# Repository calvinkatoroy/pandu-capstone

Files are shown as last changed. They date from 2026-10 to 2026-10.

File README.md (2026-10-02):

# PANDU capstone (Kelompok 13)

- `weekly/`   laporan dan progres per pekan (WEEK_2 .. WEEK_6)
- `hardware/` ekspor desain (Gerber, netlist, SCAD terbaru), diisi setelah PCB final
- `docs/`     dokumentasi pendukung

Sumber kebenaran skematik/PCB: project EasyEDA Pro "Pandu-Capstone". Repo ini hanya menyimpan salinannya.
Gerber di `weekly/WEEK_6/Gerber` adalah versi lama, JANGAN dipesan.

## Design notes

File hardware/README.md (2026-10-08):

# hardware/

PERHATIAN: Gerber di sini belum boleh dipesan, lihat gerber/README.md dan docs/AUDIT_V2.md. (Teks lama di bawah, usang:)
- `gerber/Gerber_PCB1_2026-10-03.zip`  Vest Node (ESP32 DevKitC V4, 107,95 x 95,25 mm)
- `gerber/Gerber_PCB3_2026-10-03.zip`  Edge Gateway (ESP32 DevKitC V4)

- `gerber/Gerber_PCB2_2026-10-03.zip`  Helmet Node (ditambah C2 100 uF tantalum 6,3 V di 3V0_HELMET, outline +~0,5 inci ke bawah)

Gerber lama di `weekly/WEEK_6/Gerber` JANGAN dipesan.

Sebelum order: lihat checklist "Sebelum order" di ../HANDOVER.md
(ukur board fisik, cek urutan pin modul LoRa/TP4056/boost, VBOOST_5V masih 10 mil).

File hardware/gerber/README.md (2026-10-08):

# Gerber

JANGAN dipesan, semua versi di bawah memuat masalah yang diaudit di docs/AUDIT_V2.md:
- footprint LoRa RA-02 tidak cocok dengan modul XL1276 (RFM95), PCB1 dan PCB3
- proteksi TP4056 terlewati (B- dan OUT- digabung GND), PCB1 dan PCB2
- SAW1 di PCB2 adalah filter SMD, bukan saklar
- TTP223 di PCB2 tidak dipakai lagi

`_obsolete/` = versi lama. Gerber valid berikutnya dibuat dari branch `v3` setelah revisi EasyEDA (docs/PLAN_REVISI.md).
Berkas yang masih ada di folder ini (Gerber_PCB1_2026-10-06, Gerber_PCB2_2026-10-08, Gerber_PCB3_2026-10-06) adalah yang TERBARU sebelum revisi, tetap belum boleh dipesan.

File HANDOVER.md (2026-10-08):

# HANDOVER: PANDU hardware (per 2 Okt 2026)

Penerima: sesi baru (cloud atau lokal). Baca ini dulu, lalu `weekly/WEEK_6/Audit_Skematik_Status.md`.

## Konteks singkat
- Proyek: P.A.N.D.U (Perangkat Alarm Nirkabel Deteksi Urgensi), wearable keselamatan pandu laut. Kelompok 13, user: Calvin (bahasa Indonesia santai).
- Proposal: `weekly/WEEK_2/Proposal Bab 6 ... .pdf`. Riwayat Pekan 2-5: `weekly/WEEK_6/Riwayat_Progres_Pekan2-5.md`. Jangan ulang konten itu di laporan Pekan 6.
- 3 board di EasyEDA Pro project **Pandu-Capstone**: Board1/PCB1 Vest Node Master, Board2/PCB2 Helmet Node, Board3/PCB3 Edge Gateway.
- Sumber kebenaran skematik/PCB = EasyEDA (akun calvinwkatoroy). Repo ini hanya salinan.

## Keputusan yang sudah final
- Sensor Vest: MPU6050, XKC-Y25 (air, non-kontak, VCC 5 V), GPS NEO-6M, LoRa. **Tanpa VL53L0X dan BME680** (false positive anti-crush). Tanpa buzzer di Vest.
- Board ESP32 Vest: **ESP32-DevKitC V4 WROOM-32D (klasik, Micro USB)**, bukan DevKitM-1/C3. Nama part di EasyEDA "ESP32-DEVKITM-1" menyesatkan.
- Daya Vest: 18650 > TP4056 > `VBAT_RAW` (tanpa saklar seri). Boost 5 V selalu aktif memberi pin 5V ESP32 dan `VBOOST_5V`. AMS1117, C1, C2 dihapus.
- SW1 (tact + rubber boot) = input GPIO RTC (IO13), toggle deep sleep di firmware. SOS (SW2) di IO27 (RTC).
- Gating hemat daya: GPS lewat P-MOSFET Q1 (`GPS_EN`=IO4); XKC-Y25 lewat Q2 + level shifter Q5 (`XKC_EN`=IO2). Default OFF saat sleep.
- Casing: PETG, plug silikon bertali untuk USB, SMA bulkhead, boot karet di tombol, gasket di sambungan. Klaim jujur "tahan percikan" kecuali ada uji rendam.

## Status per board
**PCB1 (Vest)**: skematik sudah diperbaiki (RA-02 pin 1 = ANT bukan GND, GND pin 2/9/16, GPS_EN tersambung, gating MOSFET). PCB di-update, auto-route, DRC 0 error, 0 ratline.
**PCB2 (Helmet)**: belum diubah. Risiko brownout CR2032 (tambah 100-220 uF low-ESR di 3V0).
**PCB3 (Gateway, sudah diganti ke DevKitC, lihat blocker 2)**: EN pull-up + 100 nF, header program J1 1x6, ANT RA-02 diperbaiki, EP ke GND, pull-down gate sirine R3. DRC 0 error. Masih ESP32 **modul polos** WROOM-32.

## BLOCKER (urut prioritas)
1. **[SELESAI di PCB1, 2 Okt malam]** Footprint ESP32 PCB1 sudah diganti ke DevKitC V4 (part LCSC C571181, designator U3, jarak baris resmi 1,0"). Skematik PCB1 tersimpan, PCB di-update, auto-route 0 ratline, DRC 0 error. Yang masih harus dicek: ukuran fisik board klon, dan USB micro DevKit sekarang menghadap ke dalam papan (perhatikan akses di casing). Teks lama:
   **Footprint ESP32 di PCB1 salah.** Sekarang 17 pin/sisi, jarak baris 0,9". Board yang dibeli (DevKitC V4) 2x19 pin, jarak baris resmi 25,4 mm (klon kadang 22,86 mm). **Part siap pakai ADA** di library EasyEDA (System): cari "DevKitC" di tab Device, baris ke-7 (LCSC C571181, nama ESP32-DEVKITC...). Simbol 38 pin (3V3, EN, VP, VN, IO34... GND, IO23, IO22, TX, RX, ... CLK) cocok dengan pinout DevKitC V4, footprint 2x19 THT dengan jarak baris sekitar 1,0" (estimasi dari preview, **ukur setelah ditempatkan**). Tidak perlu membuat dari nol. Tetap minta Calvin ukur board fisik (jarak tengah lubang kiri-kanan) sebelum order PCB.
2. **PCB3**: BOM beli DevKit tapi PCB3 didesain untuk modul polos. Rekomendasi: ganti ke footprint DevKitC V4 yang sama, hapus U4/C1/C2/J1/R2/C3 (DevKit sudah punya regulator dan USB).
3. **Modul LoRa yang dibeli bukan Ra-02**: listing "Wifi LoRa XL1276/SX1276 915MHz" (akhishop, Rp95k, datang dengan antena pegas, 1,8-3,7 V, SPI, foto mirip RFM95). Simbol/footprint RA-02 di PCB1/PCB3 mungkin tidak cocok. Minta foto sisi pin atau datasheet modul, cek urutan pin.
4. Setelah 1-3: lebarkan trek daya (VBAT_RAW, VBAT_POS 20 mil; auto-route menimpa ke 10 mil), DRC, ekspor Gerber PCB1/2/3 baru ke `hardware/`.

## Item terbuka lain
- Gateway: Q1 IRFZ44N bukan logic-level, ganti IRLZ44N (footprint sama). USB-C tanpa resistor CC 5,1k (pakai kabel A-ke-C). Dioda flyback hanya jika beban induktif.
- Pin TP4056 dan boost: urutan harus dicek ke modul fisik.
- Casing SCAD (`weekly/WEEK_6/PANDU_VestNode_Casing.scad`) belum diupdate: TP4056 di sisi Bottom (bukaan USB), posisi boost (kiri), XKC-Y25, plug USB, alur gasket.
- Gerber lama (`weekly/WEEK_6/Gerber`) **jangan dipesan**.
- Laporan Pekan 6 belum ditulis. Catat sebagai perubahan scope: tanpa ToF/BME680, PCB1 di-routing ulang setelah audit, casing dibuat ulang mengikuti PCB.
- BOM sheet (Google Sheets "Bills of Materials") belum di-update oleh tim; Rafif bilang semua sudah dibeli kecuali baris kuning dan PCB. ESP32 Vest dan LoRa Gateway tercentang FALSE padahal link sama (kemungkinan sudah dibeli 2). Harga ESP32 di listing Rp128k vs BOM Rp80k. VL53L0X/BME680 masih di BOM (hapus, hemat Rp250k). Belum ada di BOM: boost 5 V, XKC-Y25, antena+SMA untuk Vest, komponen SMD (AO3401A, 2N7002, resistor), IRLZ44N. Total BOM Rp2,495 jt vs dana Rp2 jt.
- RA-02/LoRa: proposal 915 MHz, modul dibeli 915 MHz (OK). Regulasi Indonesia 920-923 MHz, sebut di laporan.
- Angka "akurasi sensor 96,2%" di laporan kelompok tidak punya data pengujian; cek atau hapus.

## Catatan teknis EasyEDA (penting, UI-nya rapuh)
- Dikendalikan lewat ekstensi Claude-in-Chrome (klik koordinat). **Cloud session tidak bisa menjangkau Chrome lokal Calvin**, jadi pekerjaan EasyEDA harus dilakukan di sesi lokal. Cloud cocok untuk dokumen, laporan, riset, BOM, SCAD.
- Kabel yang digambar dengan klik sering meleset beberapa piksel dari ujung pin dan pin tetap mengambang. Taruh **net label tepat di titik ujung pin**, lalu verifikasi dengan DRC skematik ("Pins floating", baca via get_page_text).
- Jangan `ctrl+a` kecuali fokus pasti di kolom input; di kanvas PCB ia memilih semua objek. Mengetik teks saat fokus di kanvas memicu hotkey. Selalu klik kolom input dulu.
- Edit X/Y komponen lewat panel properti kadang tidak tersimpan; verifikasi dengan zoom ke panel. Drag di kanvas lebih andal.
- Alur PCB: Design > Update PCB from Schematic (Apply Changes), Route > Unroute > All, Route > Auto Routing (Run), Tools > Copper Manager Rebuild All, Ctrl+S, Check DRC.
- Setiap tool hotkey/aksi destruktif: cek tab tidak berasterisk (*) bila tidak ingin perubahan.

## File penting
- `weekly/WEEK_6/PANDU_VestNode_Casing.scad` (+ png render), `PCB1_Verifikasi_Skematik.md` (versi lama), `Audit_Skematik_Status.md` (status terbaru), `Riwayat_Progres_Pekan2-5.md`.
- `weekly/WEEK_6/Gerber/` (LAMA, jangan dipesan).
- `APP/` (di luar repo ini) = dashboard wireframe, repo `pandu-dashboard`.

## Pemetaan pin final
- Vest (U3 DevKitC): PWR_BTN=IO13, BTN_SOS=IO27, WATER_SIG=IO34, GPS_EN=IO4, **XKC_EN=IO32** (bukan IO2, strapping), SPI MOSI/MISO/SCK=IO23/19/18, LORA_CS=IO5, LORA_RST=IO25, LORA_DIO0=IO26, I2C SDA/SCL=IO21/22, GPS RX/TX=IO17/16.
- Gateway (U5 DevKitC): SPI IO23/19/18, LORA_CS=IO5, LORA_RST=IO14, LORA_DIO0=IO26, SD_CS=IO13, SIREN_DRV=IO4, 3V3 dan 5V_SYS dari/ke pin DevKit.
- Modul baru yang akan dibeli (kata Calvin): XKC-Y25, boost 5 V; CATATAN KOREKSI: RA-02 itu SX1278 (433 MHz), BUKAN 915 MHz. Footprint "RA-02" di PCB hanya mewakili pinout 16 pin 2 mm. Untuk 915 MHz pakai modul SX1276 (mis. Ra-01H atau RFM95W) dan cek pinout + jarak antar deret pad terhadap footprint, bukan membeli RA-02.

## Update 3 Okt 2026 (akhir sesi lokal)
- Gerber ketiga board baru ada di `hardware/gerber/` (DRC 0 error). PCB1: TP4056 diputar 180 (USB-C ke dinding kiri). PCB2: +C2 100 uF tantalum.
- Casing `weekly/WEEK_6/PANDU_VestNode_Casing.scad` v5 (standoff 9 mm, boost di atas DevKit, ekstensi micro-USB DevKit di dinding bawah). Asumsi yang perlu diverifikasi: tinggi modul TP4056 + header (~8,5 mm), tinggi holder baterai.
- Draft laporan Pekan 6: `weekly/WEEK_6/draft_isian_Pekan6.md` (butuh keputusan tim di bagian [ISI]).
- Sisa: cek fisik modul (LoRa bukan Ra-02, TP4056, boost), pesan modul kurang (XKC-Y25, boost), VBOOST_5V masih 10 mil, casing Helmet dan Gateway belum, firmware belum.

## Versi (6 Okt 2026)
- **v1** = kondisi sebelum perbaikan netlist: tag git `v1` (Gerber 3 Okt, netlist 6 Okt) dan version node EasyEDA `v1-sebelum-perbaikan` (File > Version Control > Version Management; buka node itu untuk revert).
- **v2** = branch git `v2` untuk perbaikan: konektor antena PCB1/PCB3, backfeed 5V, pull-up SD_CS, kapasitor bulk 3V3 PCB1. Di EasyEDA, v2 dikerjakan di `main` (revert lewat node v1).
- Temuan lengkap: `hardware/netlist/` (PCB1-3 .tel + check_netlist.py).

## v2 (6 Okt 2026): perbaikan dari cek netlist (branch `v2`, EasyEDA `main`)
Gerber v2: `hardware/gerber/Gerber_PCB1_2026-10-06.zip` dan `Gerber_PCB3_2026-10-06.zip` (DRC 0 error). PCB2 tidak berubah (pakai Gerber 3 Okt). Netlist terbaru: `hardware/netlist/` (cek: `python check_netlist.py`).
- PCB1: + header 2 pin H1 untuk antena (pigtail ke SMA, `LORA_ANT` sekarang terhubung ke RA-02 pin 1, `GND`); + C1 100 uF tantalum di 3V3_SYS; + D1 SS14 antara `VBOOST_5V` (anoda) dan pin 5V DevKit (`5V_DK`, katoda) agar USB DevKit tidak backfeed ke boost/baterai.
- PCB3: USB-C (USB1) dihapus, hanya micro-USB DevKit (satu port); + R2 10k pull-up SD_CS ke 3V3; + H2 header antena; Q1 IRFZ44N diganti IRLZ44N (logic-level, footprint TO-220 vertikal).
- Catatan: sirine di PCB3 sekarang disuplai lewat jalur 5V DevKit/USB (arus sirine lewat konektor micro-USB; cek rating adaptor dan jalur DevKit). Antena: sambung pigtail U.FL/SMA ke H1/H2 manual.
- Belum: modul fisik belum diverifikasi, PCB2 (dioda D1 + CR2032 vs ESP32), casing Helmet/Gateway, firmware Gateway.

- PCB2 (v2): dioda D1 1N5819 dihapus (drop 0,3-0,45 V membuat modul < 3,0 V dari CR2032); SAW1.OUTPUT langsung ke `3V0_HELMET`. DRC 0 error, Gerber `hardware/gerber/Gerber_PCB2_2026-10-06.zip`. Arus puncak BLE vs CR2032 tetap perlu uji nyata (cadangan: Li-ion kecil / 2xCR2032).

- PCB1 (v2, +pembagi baterai): R6/R7 100k + C2 100 nF, `VBAT_RAW` > `BAT_SENSE` > IO35 (ADC1_CH7). Firmware menambah kolom mV baterai di semua paket LoRa: `PANDU,V1,<jenis>,<lat>,<lon>,<mV>`. Drain pembagi ~21 uA. Kalibrasi `BAT_DIV` dengan multimeter. DRC 0 error; Gerber PCB1 tanggal 6 Okt diganti versi terbaru.

- PCB2 (v2, +tombol on/off): tact switch SW1 (tanpa saklar geser tambahan) antara `PWR_BTN` dan GND, pull-up R1 100k ke `3V0_HELMET`, `PWR_BTN` = GPIO4 SuperMini (pin RTC/deep sleep C3 = GPIO0-5). Firmware Helmet (belum ada) harus toggle deep sleep seperti Vest: tekan = tidur, tekan lagi = bangun (`esp_deep_sleep_enable_gpio_wakeup` aktif-LOW). SAW1 (saklar geser) tetap sebagai isolasi baterai penuh. DRC 0 error, Gerber `Gerber_PCB2_2026-10-06.zip` diganti, netlist `PCB2.tel` diperbarui.

## Status Vest Node (6 Okt 2026, v2)
Firmware: SOS bangun dari sleep dan langsung kirim (3x ulang), alert baru dikirim segera (tanpa tunggu 5 s), FALL/MOB 2x ulang, baterai mV di tiap paket. Casing v5 tidak perlu diubah untuk v2 (SMA bulkhead sudah ada; header antena/dioda/pembagi rendah). Belum: lebarkan trek VBAT_RAW (auto-router + clearance bentrok, 10 mil cukup untuk ~0,5 A rata-rata), uji perangkat nyata, kalibrasi ambang jatuh dan BAT_DIV.

## Firmware Helmet (6 Okt 2026)
`firmware/helmet_node/` (PlatformIO, ESP32-C3 SuperMini, NimBLE). Hanya BLE advertising 'PANDU-HELM', manufacturer data `FF FF 'P' 'H' worn counter`. Dipakai = TOUCH_SIG (GPIO2) stabil 1 s, lepas = 5 s. Tombol GPIO4 = toggle deep sleep (wake GPIO aktif-LOW). Advertising 1 s, 0 dBm, refresh tiap 10 s. Kompilasi OK, belum diuji perangkat. Belum ada: Vest men-scan BLE ini (field 'helm dipakai' di paket LoRa). Tidak ada sensor baterai di Helmet.

- Helmet firmware v2 (hemat daya): Arduino-ESP32 bawaan tanpa CONFIG_PM_ENABLE -> light sleep+BLE tidak tersedia, diganti duty-cycle deep sleep (bangun tiap 8 s, burst BLE 400 ms, state di RTC memory; tombol GPIO4 = toggle ON/OFF, OFF = tidur tanpa timer). Estimasi rata-rata ~1,5-2 mA (belum diukur), lebih baik dari ~15-20 mA sebelumnya. Latensi status helm ~8-24 s. Vest harus menyimpan status helm dengan timeout >= 30 s.

- Vest scanner BLE (6 Okt): NimBLE pasif, interval 62,5 ms/window 31 ms, scan terus-menerus; paket helm = manufacturer data FF FF 'P' 'H' worn counter. Paket LoRa sekarang: `PANDU,V1,<jenis>,<lat>,<lon>,<mV>,<helm>` dengan helm 1=dipakai, 0=terdengar tidak dipakai, 2=tidak terjangkau (timeout 30 s, juga 2 setelah bangun sampai paket pertama ~8 s). Konsekuensi: scan terus menambah arus Vest (perkiraan +10-15 mA, ukur) -> kalau boros, ganti ke scan berkala. Gateway/dashboard harus mem-parse field ke-7. Kompilasi OK (flash 48%), belum diuji.

## Firmware Gateway (6 Okt 2026)
`firmware/gateway/` (PlatformIO, DevKitC V4). Terima LoRa 915 MHz, parse `PANDU,V1,<jenis>,<lat>,<lon>,<mV>,<helm>`, keluarkan JSON per baris di serial 115200 (tambahan rssi/snr), log CSV ke SD (/pandu.csv), sirine (IO4 HIGH): SOS/MOB 500 ms, FALL 200 ms, otomatis berhenti 60 s tanpa alert baru, kirim 'M' di serial untuk mute. Peringatan `vest_lost` setelah 90 s tanpa paket (sirine mati secara default, `SIREN_ON_LOST`). Kompilasi OK (flash 26%), belum diuji. Belum: ACK ke Vest, enkripsi/otentikasi paket, tombol mute fisik (PCB3 tidak punya), jembatan serial -> dashboard.

## PCB2 v2.1 (8 Okt 2026): Helmet pakai LiPo + TP4056 (keputusan Calvin)
CR2032 dan holder dihapus. Rangkaian: LiPo (header H2 2-pin, `VBAT_POS`/GND) > modul TP4056 USB-C berproteksi (U7, OUT+ = `VBAT_RAW`) > saklar geser SAW1 > `VBAT_SW` > pin **5V** SuperMini (regulator onboard 3,3 V). 3V3 dari board memberi daya TTP223 (net `3V0_HELMET`, sebenarnya 3,3 V). Tombol tact GPIO4 dan sensor sentuh GPIO2 tidak berubah. Outline diperpanjang jadi 1245 x 3900 mil. DRC 0, tanpa ratline. Gerber: `hardware/gerber/Gerber_PCB2_2026-10-08.zip` (menggantikan versi 6 Okt). Netlist `PCB2.tel` diperbarui. USB SuperMini aman dicolok bersama baterai karena baterai masuk lewat pin 5V (diode onboard SuperMini ke VBUS harus diverifikasi di board fisik). Belum: casing Helmet, cek apakah pin 5V SuperMini benar-benar lewat LDO (bukan terhubung langsung ke 3V3), arus TP4056 saat beban.

## Temuan modul LoRa (foto pad, 8 Okt 2026)
- Modul XL1276-P01 (SX1276) berpinout **RFM95**, bukan RA-02: footprint PCB1/PCB3 (`WIRELM-SMD_RA-02-BL`) tidak cocok. Pinout dari foto: kiri atas-bawah DIO2, DIO1, DIO0, VCC, DIO4, DIO3, GND, ANT; kanan GND, MISO, MOSI, SCK, NSS, REST, DIO5, GND.
- Kotak pita frekuensi di foto menandai **868M** (belum dicek di modul fisik). Firmware memakai 915 MHz.
- Tindakan: ganti footprint ke RFM95 di EasyEDA (PCB1 dan PCB3) dan netlist ulang; cek pita 868/915 pada modul; jangan order PCB sebelum itu.

## Koreksi desain Helmet (8 Okt 2026)
Deteksi helm TIDAK memakai sensor sentuh. Alur: tombol ON/OFF di Helmet (GPIO4) -> Helmet menyiarkan BLE `PANDU-HELM` -> Vest menilai dekat/jauh dari RSSI (`HELM_RSSI_MIN`, default -85 dBm, dikalibrasi). Field helm di paket LoRa: 1 = beacon terdengar dan dekat, 0 = terdengar tapi jauh, 2 = tidak terdengar (OFF atau jauh > 30 s). Firmware `helmet_node` sudah disederhanakan (tanpa TTP223/GPIO2). TODO PCB2: hapus TTP223 (H1), net `TOUCH_SIG`, dan ganti `SAW1` (salah, bukan saklar). Catatan: checklist dan tutorial breadboard masih menyebut sensor sentuh; abaikan bagian itu.

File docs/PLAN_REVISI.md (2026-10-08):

# Plan revisi PANDU (EasyEDA, firmware, dokumen, dashboard)

Dasar: [AUDIT_V2.md](AUDIT_V2.md) (kode temuan A1.., B1.., C1.., D1..) dan definisi proyek terbaru dari Calvin.
Ukuran pekerjaan: S = kecil (menit), M = sedang (sekitar satu sesi), L = besar (beberapa sesi). Perkiraan kasar, bukan janji.

## Keputusan yang sudah dikunci
- MOB = jatuh, lalu basah (>=3 s) dalam 60 s. FALL sendiri = danger. SOS manual = danger. Basah saja = bukan alarm.
- Tahap: 1 aman, 2 warning (helm tidak dekat), 3 danger. Status terpisah: tidak terjangkau dan inaktif (paket OFF).
- Helm: tombol on/off + beacon BLE + RSSI. Tanpa sensor sentuh. Baterai LiPo + TP4056 (bukan CR2032).
- Sampai 8 Vest, ID tetap 1-8 (firmware) + ID perangkat dari MAC. Heartbeat 30 s dengan jitter, paket biner kompak, SF10-12.
- Gateway di dermaga: WiFi, cloud (Supabase atau Firebase), microSD hanya buffer offline (store-and-forward), buzzer lokal, NTP.
- Alarm hilang saat normal, bisa di-mute dan dihapus operator. Danger yang kehilangan kontak tetap sampai operator mengakui.
- Demo awal tanpa LoRa (lihat TUTORIAL_DEMO_TANPA_LORA.md).

## Keputusan yang masih menunggu
| # | Pertanyaan | Mempengaruhi |
|---|---|---|
| K1 | Varian XKC-Y25 (NPN atau tegangan) dan polaritasnya: ukur saat modul datang | PCB1 rangkaian IO34 |
| K2 | Indikator di Vest (LED/haptic): masuk atau dibuang dari BOM | PCB1 |
| K3 | Dashboard untuk overseer atau pandu? Tombol "I'm safe" dan "Hold to send SOS" dibuang atau dipertahankan (butuh downlink) | APP, Gateway |
| K4 | Baterai helm perlu dilaporkan di dashboard? | PCB2 (pembagi), beacon |
| K5 | Cadangan daya Gateway (UPS atau power bank) | PCB3, casing |
| K6 | Cloud: Supabase atau Firebase (tanya Rafif) | Gateway, APP |

## Gerbang sebelum PCB dipesan
Semua harus terpenuhi: (1) cek modul fisik di bawah selesai, (2) revisi EasyEDA selesai dan DRC 0, (3) tes demo Vest + Helmet lulus, (4) tautan LoRa Vest ke Gateway lulus di breadboard, (5) Gerber lama di repo ditandai tidak valid.

## Fase 0: Persiapan (S)
1. Di EasyEDA buat salinan project ("Pandu-Capstone-v2.1-backup") sebelum mengedit apa pun, supaya bisa dikembalikan.
2. Git: tag `v2.1` pada commit sekarang, kerja revisi di branch baru `v3`.
3. Pindahkan Gerber lama (10-03, 10-06) ke `hardware/gerber/_obsolete/` dan tandai di README.

## Fase 1: Cek modul fisik (M, Calvin, sebelum edit PCB)
Hasilnya ditulis di bagian 7 `TUTORIAL_BREADBOARD.md`.
| Item | Yang diukur/dicek |
|---|---|
| ESP32 DevKit | Jarak tengah lubang kiri-kanan (25,4 atau 22,86 mm), ukuran papan |
| Modul LoRa XL1276-P01 | Lebar dan jarak deret pad, panjang modul, pita 868M atau 915M (kotak yang terisi), jarak pitch 2 mm |
| TP4056 HW-373 | Urutan pad kiri ke kanan (OUT−, B−, B+, OUT+ dari foto), ukuran papan, posisi USB-C |
| GY-521 | Urutan pin header dan jarak, posisi lubang baut |
| GPS NEO-6M | Urutan pin (VCC, RX, TX, GND?), ukuran, konektor antena |
| SuperMini | Pin map (GPIO4, 3V3, 5V, GND), apakah pin 5V lewat regulator (ukur 3V3 dengan 4 V di pin 5V), dioda ke VBUS |
| Boost MT3608 | Urutan pad IN+, IN-, OUT-, OUT+ |
| Modul microSD | Urutan pin header, level logika |
| XKC-Y25 | Varian, tegangan output saat kering dan basah (K1) |
| Sensor air murah | Konektor S/+/- |

## Fase 2: Revisi EasyEDA

### Cara kerja (dari HANDOVER, UI rapuh)
- Satu perubahan, satu simpan, satu DRC. Net label tepat di ujung pin. Jangan `ctrl+a` kecuali fokus pasti di kolom input.
- Alur PCB: Design > Update PCB from Schematic (Apply Changes) > Route > Unroute All > Auto Route (Run) > Tools > Copper Manager Rebuild All > DRC.
- Setelah tiap board: ekspor netlist (`.tel`), jalankan `check_netlist.py`, ekspor Gerber (jangan klik Order PCB), simpan di `hardware/`.

### PCB2 Helmet (M) kerjakan lebih dulu, paling kecil
| # | Tugas | Kode audit |
|---|---|---|
| P2-1 | Ganti `SAW1` dengan saklar geser sungguhan (SPDT/SPST THT 2,54 mm) atau header 2 pin + jumper; perbarui footprint | A1 |
| P2-2 | Pisahkan negatif baterai: net `BAT_NEG` = `H2.2` + pin `B-` TP4056; hanya `OUT-` dan `IN-` ke GND | A2 |
| P2-3 | Hapus TTP223 (`H1`) dan net `TOUCH_SIG` | A5 |
| P2-4 | Cocokkan pin map SuperMini (`U1` pin 13 GPIO4, 14 3V3, 16 5V) dengan modul fisik | A12 |
| P2-5 | (jika K4) pembagi baterai ke satu GPIO ADC | K4 |
| P2-6 | Kecilkan outline setelah TTP223 dilepas, DRC, Gerber, netlist | |

### PCB1 Vest (L)
| # | Tugas | Kode audit |
|---|---|---|
| P1-1 | Pisahkan negatif baterai: `BAT_NEG` = `BT1.2` + `U7.3 (B-)`; `U7.4 (OUT-)` dan `U7.6 (IN-)` ke GND | A2 |
| P1-2 | Ganti footprint LoRa `U6` ke RFM95 (pinout fisik), sambung ulang ANT, GND, 3V3, RST (IO25), DIO0 (IO26), NSS (IO5), SCK/MISO/MOSI | A3 |
| P1-3 | Sensor air: sesuai K1. Siapkan pembagi `R8` 10 k dan `R9` 20 k (bisa tidak dipasang) di `WATER_SIG`; `R1` pull-up hanya untuk varian open-collector | A4 |
| P1-4 | Lebarkan `VBAT_RAW`, `VBOOST_5V`, `VBAT_POS` ke sekitar 25 mil | A13 |
| P1-5 | (jika K2) LED atau haptic + resistor ke GPIO bebas | A11 |
| P1-6 | Cocokkan footprint GY-521, TP4056, GPS, DevKit dengan hasil Fase 1 | A12 |
| P1-7 | (opsional) lepas jalur TX ESP ke GPS | A14 |
| P1-8 | Titik uji untuk 3V3, 5V, GND, BAT, WATER; label versi di silkscreen | |
| P1-9 | Route ulang (papan padat, kemungkinan perlu geser komponen), DRC, Gerber, netlist | |

### PCB3 Gateway (M)
| # | Tugas | Kode audit |
|---|---|---|
| P3-1 | Ganti footprint LoRa `U1` ke RFM95 | A3 |
| P3-2 | Pindahkan microSD ke bus SPI terpisah: usul `SD_SCK`=IO25, `SD_MISO`=IO35 (input-only, cukup), `SD_MOSI`=IO32, `SD_CS`=IO33; hindari pin strapping (0, 2, 5, 12, 15). LoRa tetap di IO18/19/23 | A8 |
| P3-3 | Tombol mute (tact ke GND di IO27, pull-up internal); LED status memakai LED onboard DevKit (IO2) | A9 |
| P3-4 | Dioda flyback (1N4148/1N5819) di terminal sirine, bisa tidak dipasang untuk buzzer elektronik | A15 |
| P3-5 | Cocokkan urutan header microSD `H1` dengan modul fisik | A12 |
| P3-6 | (jika K5) konektor cadangan daya | A10 |
| P3-7 | DRC, Gerber, netlist | |

### Setelah ketiganya
- Perbarui `check_netlist.py` agar mencakup PCB2 dan pin map baru PCB3.
- Pembaruan `hardware/README.md` dan HANDOVER dengan daftar Gerber yang valid.

## Fase 3: Firmware (M-L)
| # | Tugas | Kode audit |
|---|---|---|
| F-1 | Paket biner v2: ID Vest, nomor urut, jenis (HB, SOS, FALL, MOB, OFF), lat, lon, baterai, helm, usia posisi, opsional sat/HDOP | B2, B9 |
| F-2 | Vest: FALL lalu MOB (sudah di kode, perlu uji), paket OFF saat tidur, jitter heartbeat, ID di NVS (set lewat serial) | B1, B6 |
| F-3 | Pairing: beacon helm membawa ID, Vest hanya menerima ID pasangannya | B7 |
| F-4 | LoRa: SF, BW, daya lewat konstanta dua sisi; ACK untuk SOS dengan ulang sampai diterima | B3, B6 |
| F-5 | Gateway: WiFi, NTP, dorong ke server, antrean di SD (store-and-forward), SD di SPI kedua, pemetaan tahap 1/2/3, tombol mute | B4, A8, A9 |
| F-6 | Tes logika di laptop (native test) untuk FALL/MOB, tahap, timeout, antrean | |
| F-7 | Kalibrasi: ambang jatuh, air, RSSI helm dengan data nyata | B5 |

## Fase 4: Dashboard (M-L, Rafif + Calvin)
1. Sepakati skema data JSON (id, seq, waktu, jenis, lat, lon, baterai, helm, rssi, usia posisi).
2. Backend (K6): tabel `events`, `vests` (last_seen); Realtime untuk push ke web.
3. Web/PWA: daftar sampai 8 pandu dengan warna tahap, peta live (Leaflet + OpenStreetMap), log kejadian, mute dan hapus alarm, notifikasi saat danger.
4. Ganti `APP/index.html` statis dengan versi terhubung ke data; sesuaikan elemen yang tidak ada di hardware (C5, C6).
5. Status "tidak terjangkau" setelah 3 heartbeat hilang; "inaktif" jika paket OFF.

## Fase 5: BOM dan dokumen (S-M)
- Perbarui BOM sheet dengan `BOM_V2.md` dan hasil revisi (RFM95, saklar, pembagi, tombol mute, dioda).
- Rapikan HANDOVER, hapus catatan usang, perbarui checklist dan tutorial breadboard (TTP223, CR2032).
- Laporan Pekan 6 dan 7: perubahan scope, temuan audit, hasil tes.

## Fase 6: Uji dan pesan PCB
1. Demo Vest + Helmet lulus (TUTORIAL_DEMO_TANPA_LORA.md).
2. Modul LoRa kedua datang, tautan Vest ke Gateway di breadboard, survei RSSI di beberapa jarak.
3. Tes XKC (hujan, keringat, celup), tes baterai dan charging dengan TP4056 yang benar.
4. Gerbang PCB terpenuhi, baru pesan. Setelah PCB datang: ulangi checklist rakit.
5. Casing Helmet dan Gateway, update casing Vest.

## Urutan kerja yang disarankan
Fase 0 → Fase 1 (paralel: Fase 3 F-1 s/d F-3) → Fase 2 (PCB2, lalu PCB3, lalu PCB1) → Fase 3 F-4 s/d F-6 → Fase 4 → Fase 6.

## Risiko
- Jarak 5 km di atas laut belum terbukti; antena Gateway harus tinggi, perlu survei lapangan.
- XKC terhadap keringat dan hujan hanya terbukti lewat tes nyata.
- Umur baterai Vest kemungkinan sekitar 4-5 jam (perkiraan kasar), di bawah target satu shift.
- Auto-router PCB1 padat; tiap perubahan dapat memerlukan penempatan ulang.

## Status pelaksanaan (8 Okt 2026, malam)
- Fase 0 selesai: tag `v2.1`, branch `v3`, Gerber lama dipindah ke `hardware/gerber/_obsolete/`, backup project EasyEDA `Pandu-Capstone-v2.1-backup`.
- PCB2: P2-1 (SAW1 diganti header jumper `J1`), P2-2 (`BAT_NEG`), P2-3 (TTP223 dan `TOUCH_SIG` dihapus) selesai di EasyEDA, DRC 0, `hardware/netlist/PCB2.tel` diperbarui. Sisa: P2-4 (cek pin SuperMini fisik), P2-6 (kecilkan outline), hapus stub `$1N31` di `U1` pin 11.
- PCB3: P3-2 selesai (SD di bus sendiri: SCK=IO25, MISO=IO35, MOSI=IO32, CS=IO33), DRC 0, `PCB3.tel` diperbarui, firmware Gateway disesuaikan. Sisa: P3-1 (footprint LoRa RFM95), P3-3 (tombol mute), P3-4 (dioda flyback opsional), P3-5, P3-6.
- PCB1: belum disentuh (P1-1 `BAT_NEG`, P1-2 footprint LoRa, P1-3 sensor air, dst).
- Gerber BELUM diekspor ulang untuk revisi ini; tunggu gerbang pesan PCB.
- `check_netlist.py` kini mencakup PCB2 dan pin map PCB3 baru (semua OK).

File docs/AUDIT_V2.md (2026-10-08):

# Audit PANDU v2 vs definisi proyek (8 Okt 2026)

Definisi acuan (dari Calvin): Vest = MOB (jatuh AND ada air di balik casing, non-contact) + deteksi helm via RSSI BLE + LoRa 915 ke Gateway + GPS + USB-C + 18650 1200 mAh + 2 tact (SOS, power). Helmet = beacon BLE, tact on/off, baterai kecil. Gateway = LoRa, microSD, dashboard 3 tahap (1 aman, 2 warning APD tidak lengkap, 3 danger SOS/FALL/MOB), peta real-time, buzzer lokal, WiFi di dermaga, sampai 8 Vest.

Yang diperiksa: netlist `PCB1/2/3.tel`, skematik EasyEDA (Vest, Helmet, Gateway, dibuka langsung), PCB1 (cek sebagian), firmware di `firmware/`, dashboard `APP/index.html`, BOM sheet, dokumen repo.
Tingkat: **KRITIS** = alat tidak jalan/berbahaya, **SEDANG** = tidak sesuai definisi atau berisiko, **MINOR** = rapikan.

## A. Skematik dan PCB (EasyEDA)

| # | Tingkat | Board | Temuan | Perbaikan |
|---|---|---|---|---|
| A1 | KRITIS | PCB2 | `SAW1` = filter SMD SAPPLAND SPST40SU03C (footprint FILTER-SMD 1,1x0,9 mm), bukan saklar. Jalur baterai Helmet lewat komponen ini | Ganti saklar geser sungguhan atau header 2 pin + jumper |
| A2 | KRITIS | PCB1, PCB2 | TP4056: pin `B-` dan `OUT-` sama-sama GND, negatif baterai ke GND. Proteksi DW01 terlewati (over-discharge, over-current, korslet) | Negatif baterai hanya ke `B-`; `OUT-` ke GND sistem |
| A3 | KRITIS | PCB1, PCB3 | Footprint LoRa `RA-02` (pin 1 ANT, 3 3,3V, 4 RST, 5 DIO0, 12-15 SCK/MISO/MOSI/NSS). Modul fisik XL1276-P01 berpinout RFM95 (kiri atas-bawah DIO2, DIO1, DIO0, VCC, DIO4, DIO3, GND, ANT; kanan GND, MISO, MOSI, SCK, NSS, REST, DIO5, GND) | Ganti footprint ke RFM95, cek jarak deret pad, route ulang |
| A4 | KRITIS | PCB1 | XKC-Y25 (5 V) ke IO34 tanpa pembagi/pelindung. Beberapa varian outputnya naik ke tegangan suplai (5 V), batas IO34 sekitar 3,6 V. Pull-up R1 ke 3V3 hanya cocok untuk varian open-collector | Ukur output saat modul datang; tambah pembagi 10k/20k atau pakai pull-up saja sesuai varian; cek polaritas |
| A5 | SEDANG | PCB2 | TTP223 (`H1`), net `TOUCH_SIG` masih ada, padahal deteksi helm via tombol + BLE + RSSI | Hapus H1 dan TOUCH_SIG; GPIO2 bebas |
| A6 | SEDANG | PCB2 | Definisi: CR2032. EasyEDA: LiPo + TP4056 (CR2032 tidak kuat untuk lonjakan BLE dan tidak bisa diisi ulang). Pin 5V SuperMini harus lewat regulator (belum diverifikasi), dan USB SuperMini + baterai bersamaan belum diuji | Perbarui definisi ke LiPo. Cek pin 5V di board fisik |
| A7 | SEDANG | PCB1 | TP4056 HW-373 mengisi default sekitar 1 A (R-prog 1,2k). Baterai 1200 mAh: 0,83C, di atas 0,5C yang umum disarankan | Cek datasheet sel; ganti R-prog sekitar 2k (sekitar 580 mA) |
| A8 | SEDANG | PCB3 | microSD satu bus SPI dengan LoRa (IO18/19/23). Penulisan SD memblokir sampai ratusan ms, paket LoRa bisa hilang | Pisahkan SD ke bus SPI kedua |
| A9 | SEDANG | PCB3 | Tidak ada tombol mute atau LED di Gateway; mute hanya lewat serial `M`. Definisi: operator bisa mematikan alarm | Tombol mute fisik, dan/atau mute dari dashboard (perlu downlink MQTT) |
| A10 | SEDANG | PCB3 | Tidak ada cadangan daya. Mati listrik di dermaga = sistem keselamatan mati | Catat sebagai risiko, atau tambah UPS/powerbank |
| A11 | SEDANG | PCB1 | Tidak ada indikator di Vest (LED/haptic) untuk memberi tahu "SOS terkirim/diterima". HANDOVER: tanpa buzzer di Vest, tapi BOM berisi "LED indikator, buzzer/haptic" | Putuskan: LED/haptic atau hapus dari BOM |
| A12 | MINOR | PCB1 | Urutan pad footprint GY-521 (simbol memberi nomor 8..1, VCC = 8), TP4056, DevKit (jarak baris), SuperMini belum dicocokkan ke modul fisik | Cek satu per satu dengan modul |
| A13 | MINOR | PCB1 | `VBAT_RAW` dan `VBOOST_5V` masih 10 mil untuk arus beberapa ratus mA | Lebarkan 20-30 mil |
| A14 | MINOR | PCB1 | Jalur UART TX ESP ke GPS (IO17) tidak dipakai firmware; saat GPS dimatikan, TX bisa memberi daya lewat dioda proteksi | Boleh tidak disambung |
| A15 | MINOR | PCB3 | Sirine lewat IRLZ44N tanpa dioda flyback (aman untuk buzzer elektronik, tidak untuk beban berkoil) | Pastikan jenis buzzer |

Yang sudah sesuai: 2 tact di Vest (power IO13 RTC, SOS IO27 RTC aktif-HIGH), 18650 + TP4056 USB-C, GPS gating Q1, MPU6050 I2C, pembagi baterai IO35, pin map firmware vs netlist (script OK untuk PCB1 dan PCB3), IRLZ44N logic-level di Gateway, tact on/off + pull-up di Helmet.

## B. Firmware vs definisi

| # | Tingkat | Temuan | Perbaikan |
|---|---|---|---|
| B1 | KRITIS | MOB: firmware memicu `FALL` dan `MOB` sebagai alarm terpisah (OR). Definisi: jatuh AND basah | FALL langsung danger; naik ke MOB jika basah (>=3 s) dalam 60 s setelah jatuh |
| B2 | KRITIS | Paket `PANDU,V1,...` tanpa ID Vest dan nomor urut. Tidak bisa banyak Vest, tidak bisa membuang duplikat SOS | Format biner v2: ID, seq, jenis, lat, lon, baterai, helm, usia posisi |
| B3 | KRITIS | LoRa memakai default library (SF7). Anggaran link sekitar 142 dB; jarak 5 km di atas air perlu SF10-12 | Atur SF, BW, daya lewat konstanta di kedua sisi |
| B4 | KRITIS | Gateway tidak ada WiFi/cloud/pemetaan tahap. Hanya JSON ke serial dan CSV dengan `millis()` | WiFi, NTP, kirim ke server, antrean SD, tahap 1/2/3 |
| B5 | SEDANG | Deteksi jatuh memakai akselerometer saja; definisi menyebut gyroscope. Ambang 0,6 g / 2,5 g belum divalidasi (hanya jatuh ke kasur) | Pertimbangkan laju rotasi; kalibrasi dengan data nyata |
| B6 | SEDANG | SOS dikirim 3x tanpa ACK, heartbeat tetap 30 s tanpa jitter, tidak ada paket OFF (inaktif vs tidak terjangkau tidak bisa dibedakan) | ACK untuk SOS, jitter, paket OFF |
| B7 | SEDANG | Beacon helm tanpa ID: Vest bisa menangkap helm orang lain. Ambang RSSI -85 dBm tebakan | Pairing ID, kalibrasi |
| B8 | SEDANG | Tidak ada downlink Gateway ke Vest (untuk mute/"aku selamat") | Putuskan perlu atau tidak |
| B9 | MINOR | Firmware hanya mengirim posisi terakhir + usia; sat, HDOP, kecepatan, arah tidak dikirim | Tambah jika dashboard menampilkannya |

Sudah sesuai: Helmet beacon + tombol (tanpa sentuh), Vest membaca RSSI, posisi terakhir dengan usia, paket baterai, SOS wake dari tidur, buzzer lokal di Gateway (pola SOS/MOB 500 ms, FALL 200 ms).

## C. Dashboard (`APP/index.html`)

File ini mockup statis (satu pandu, tombol "Mockup state" Safe/Offline/SOS, data hardcode).

| # | Tingkat | Temuan |
|---|---|---|
| C1 | KRITIS | Tidak ada sumber data (tanpa backend/WebSocket), semua teks hardcode |
| C2 | SEDANG | Hanya 3 state: ON STATION / SIGNAL LOST / SOS SENT. Definisi: aman / warning (APD tidak lengkap) / danger. Warning tidak ada; FALL vs MOB tidak dibedakan |
| C3 | SEDANG | Satu pandu ("Capt. A. Ridwan"). Definisi: overseer memantau sampai 8 pandu; perlu daftar dan ringkasan |
| C4 | SEDANG | Peta = SVG statis Tg. Priok, bukan peta live (perlu Leaflet/OpenStreetMap atau peta laut) |
| C5 | SEDANG | Menampilkan baterai helm (%), jumlah satelit, akurasi (m), heading dan kecepatan (kt). Hardware tidak mengirim baterai helm, sat, HDOP, arah, kecepatan |
| C6 | SEDANG | Tombol "I'm safe" dan "Hold to send SOS" di app. Definisi: SOS hanya dari tact Vest. App menyiratkan uplink dan peran pandu sebagai pengguna app, bukan overseer |
| C7 | MINOR | Tidak ada kontrol operator: mute, hapus alarm, log kejadian ("Log ›" belum ada isinya) |
| C8 | MINOR | Label campur Inggris dan Indonesia |

Sudah sesuai: dua indikator yang tersedia (sinyal LoRa dalam dBm, baterai Vest) dan tata letak mobile, peta di tengah, log kejadian terakhir.

## D. Dokumen, BOM, repo

| # | Tingkat | Temuan |
|---|---|---|
| D1 | SEDANG | Folder `hardware/gerber/` memuat versi lama (10-03, 10-06) yang sudah tidak valid, dan semua versi memuat A1-A3. Jangan dipesan |
| D2 | SEDANG | BOM sheet (6 Okt) masih memuat VL53L0X, BME680, AMS1117, CR2032; belum ada boost, MOSFET, LiPo, TP4056 kedua, XKC, saklar |
| D3 | MINOR | `HANDOVER.md` bagian awal usang (mis. "XKC_EN=IO2" vs IO32 di bagian bawah; PCB2 "belum diubah"). `hardware/README.md` menyebut Gerber 3 Okt sebagai terbaru |
| D4 | MINOR | Checklist dan tutorial breadboard masih menyebut TTP223 dan umur CR2032 |
| D5 | MINOR | Laporan kelompok memuat "akurasi sensor 96,2%" tanpa data uji (catatan lama di HANDOVER) |
| D6 | MINOR | Klaim "tahan percikan" belum ada uji |

## E. Belum diperiksa
Footprint dan posisi pad fisik di PCB (GY-521, TP4056, SuperMini, DevKit), hasil DRC terbaru (terakhir 0 error), lebar trek, casing SCAD, dan skematik PCB2 untuk pin map SuperMini terhadap modul fisik.

## F. Ringkasan
- KRITIS: A1, A2, A3, A4, B1, B2, B3, B4, C1 (9 item)
- SEDANG: A5-A11, B5-B8, C2-C6, D1-D2 (21 item)
- MINOR: sisanya
- Yang sudah benar: pin map firmware, 2 tombol, daya Vest, USB-C, gating GPS, beacon + RSSI, logika posisi terakhir.

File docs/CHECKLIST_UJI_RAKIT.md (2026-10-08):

# Checklist Uji Rakit PANDU (v2)

Urutan dari paling aman ke paling berisiko. Centang `[x]` hanya jika diukur sendiri. Jangan lanjut ke tahap berikutnya kalau tahap sebelumnya gagal.
Alat: multimeter, power supply 5 V terbatas arus (atau USB), kabel USB, kabel jumper, perfboard/breadboard, 1 antena LoRa (JANGAN transmit tanpa antena).

Firmware: `firmware/vest_node`, `firmware/helmet_node`, `firmware/gateway` (build: `python -m platformio run`, upload: `python -m platformio run -t upload`, monitor: `python -m platformio device monitor`).

## 0. Verifikasi modul fisik (sebelum order PCB)
- [ ] **ESP32 DevKit**: ukur jarak tengah lubang pin kiri-kanan. Resmi 25,4 mm. Hasil: ____ mm. Jika 22,86 mm, footprint PCB1/PCB3 harus diubah.
- [ ] **Modul LoRa**: foto sisi pin, cocokkan urutan dengan RA-02 (pin 1 ANT, 2 GND, 3 3,3V, 4 RESET, 5 DIO0 ... 12 SCK, 13 MISO, 14 MOSI, 15 NSS, 16 GND). Hasil: ____ (cocok / tidak cocok). Jika bukan RA-02, footprint harus diubah.
- [ ] **TP4056**: urutan pin/pad (IN+, IN-, OUT+, OUT-, B+, B-) dan posisi USB-C sesuai footprint.
- [ ] **Boost MT3608**: urutan IN+/IN-/OUT-/OUT+ sesuai header 4 pin (`IN+ IN- OUT- OUT+`).
- [ ] **SuperMini C3 (Helmet)**: urutan pin dan posisi pin 3V3/5V/GND/GPIO2/GPIO4 sesuai simbol.
- [ ] **XKC-Y25**: tipe output (NPN open-collector atau tegangan) dan tegangan kerja. Hasil: ____. Jika output 5 V, IO34 butuh pembagi/level shifter.
- [ ] **Modul sentuh TTP223**: mode (momentary/toggle), output aktif-HIGH atau LOW. Hasil: ____.
- [ ] **Holder 18650, GPS NEO-6M, MPU6050**: ukur dimensi untuk dicocokkan ke casing.

## 1. Daya Vest (tanpa ESP32 terpasang)
- [ ] **Setel boost ke 5,0 V dulu**, sebelum disambung ke apa pun: input 3,7 V dari power supply, putar trimmer, ukur output. Hasil: ____ V (target 5,0 ± 0,1).
- [ ] TP4056: colok USB-C tanpa baterai, ukur tegangan OUT. Dengan baterai terpasang: LED merah (charging) menyala, lalu biru/hijau saat penuh.
- [ ] Baterai 18650 terpasang, ukur `VBAT_RAW` di PCB: ____ V (3,0–4,2).
- [ ] Ukur `BAT_SENSE` (tengah R6/R7): harus separuh `VBAT_RAW`. Hasil: ____ V.
- [ ] Ukur 5V di pin 5V DevKit dan `VBOOST_5V`. Selisih = drop D1 (SS14, sekitar 0,3–0,5 V). Hasil: ____ V.
- [ ] Ukur arus tanpa beban (hanya boost): ____ mA.

## 2. Vest: boot dan sensor
- [ ] Upload `vest_node`. Serial menunjukkan `Boot: MPU=1 LoRa=1 wake=other`. Jika `MPU=0`: cek I2C (SDA IO21, SCL IO22, alamat 0x68). Jika `LoRa=0`: cek CS IO5, RST IO25, DIO0 IO26, antena.
- [ ] **3V3**: ukur 3V3_SYS = ____ V (3,2–3,4).
- [ ] **Gating GPS**: `GPS_EN` (IO4) LOW → `GPS_3V3` ≈ 3,3 V; hi-Z → `GPS_3V3` ≈ 0 V. Hasil ON: ____ V, OFF: ____ V.
- [ ] **Gating XKC-Y25**: `XKC_EN` (IO32) HIGH → `XKC_5V` ≈ 5 V; LOW → ≈ 0 V. Hasil ON: ____ V, OFF: ____ V.
- [ ] **GPS**: di luar ruangan, NMEA terbaca dan fix didapat dalam ____ detik. Paket LoRa berisi lat/lon (bukan `NOFIX`).
- [ ] **MPU6050**: jatuhkan alat ke kasur dari ±1 m. Ambang jatuh (0,4 g / 2,5 g) memicu `FALL`? Tidak memicu saat diayun/diguncang biasa? Catat nilai yang berhasil: ____ g / ____ g.
- [ ] **Sensor air**: celupkan XKC-Y25 ke air. `WATER_SIG` (IO34) berubah dan `MOB` terkirim setelah 3 detik. Percikan singkat < 3 detik tidak memicu.
- [ ] **Tombol power (IO13)**: tekan = tidur (serial `Sleep...`), tekan lagi = bangun.
- [ ] **Tombol SOS (IO27)**: tahan 2 detik = `SOS` terkirim. Saat tidur, tekan SOS membangunkan alat dan langsung mengirim (3x ulang).
- [ ] **Baterai di paket**: mV di paket ≈ nilai multimeter (selisih < 50 mV). Kalibrasi `BAT_DIV`. Hasil: ____.

## 3. Gateway
- [ ] Upload `gateway`. Serial `{"boot":true,"lora":1,"sd":1}`. Jika `sd":0`: cek kartu SD (FAT32), CS IO13, kabel.
- [ ] Sirine lepas dulu, ukur gate IRLZ44N: 0 V saat idle, ≈ 3,3 V saat sirine ON.
- [ ] Sambung sirine/beban uji (jangan langsung sirine penuh): LED + resistor dulu, lalu sirine. Arus sirine ____ A, jalur 5V DevKit tidak jatuh di bawah 4,5 V.
- [ ] **Hanya satu port USB** dicolok (micro-USB DevKit). Jangan pernah dua sumber 5 V bersamaan.
- [ ] Mute: kirim `M` di serial, sirine berhenti.

## 4. Tautan LoRa Vest → Gateway
- [ ] Frekuensi sama (915 MHz default kedua firmware). Antena terpasang di kedua sisi.
- [ ] Jarak 1 m: paket `HB` (heartbeat tiap 30 s) diterima. Catat RSSI: ____ dBm.
- [ ] Jarak 10, 50, 100 m (terbuka): RSSI ____ / ____ / ____ dBm; paket hilang? ____ %.
- [ ] Simulasikan `SOS`: sirine Gateway bunyi dalam < 2 detik; `/pandu.csv` bertambah satu baris.
- [ ] Simulasikan `FALL` dan `MOB`: pola sirine berbeda (200 ms vs 500 ms).
- [ ] Matikan Vest: setelah 90 detik Gateway mencetak `vest_lost`.
- [ ] Paket asing (kirim string acak dari modul lain) diabaikan (`bad_packet`).

## 5. Helmet
- [ ] LiPo + TP4056: ukur `VBAT_SW` (setelah saklar) ≈ tegangan baterai ____ V; ukur 3V3 output SuperMini = ____ V (harus 3,3 V, di baterai 3,3-4,2 V).
- [ ] Cek di board SuperMini: pin 5V melewati regulator (jangan memberi 4,2 V ke pin 3V3). Colok USB SuperMini sambil baterai terpasang: tidak ada arus balik ke USB (ukur arus), tidak ada panas.
- [ ] Isi baterai lewat TP4056 USB-C: LED charging menyala, suhu normal.
- [ ] Upload `helmet_node`. Serial: `helm dipakai=0`.
- [ ] Sentuh sensor TTP223: setelah 2 siklus (≈ 8–16 s) `helm dipakai=1`. Lepas: berubah ke 0 setelah 3 siklus.
- [ ] Tombol GPIO4: tekan = OFF (tidur tanpa timer), tekan lagi = ON.
- [ ] **Arus rata-rata** (ampere-meter seri dengan baterai, rata-rata ≥ 60 s): ____ mA. Arus saat tidur: ____ µA. Target < 2 mA. Perkiraan umur CR2032 = 220 mAh ÷ arus = ____ jam.
- [ ] Tegangan saat burst BLE (osiloskop jika ada, atau pantau brownout): tidak ada reset acak.
- [ ] Lepas LED daya SuperMini dan ukur ulang arus: ____ mA.

## 6. Vest ↔ Helmet (BLE)
- [ ] Helm dipakai: paket LoRa Vest berisi field helm `1` setelah ≤ 24 s.
- [ ] Helm dilepas: field berubah ke `0`. Helm dimatikan/jauh > 30 s: `2`.
- [ ] Beberapa helm PANDU berdekatan: Vest tidak salah menangkap helm lain? (belum ada ID pasangan)
- [ ] Jarak BLE maksimum (helm ke Vest di badan): ____ m.
- [ ] Arus Vest naik berapa dengan scan BLE terus-menerus? ____ mA (perkiraan +10–15 mA).

## 7. Uji ketahanan
- [ ] Vest aktif penuh (GPS + BLE + LoRa) sampai baterai 3,3 V: ____ jam. Target ≥ 8 jam (satu shift).
- [ ] Uji percikan air pada casing/plug USB (hanya klaim "tahan percikan" kalau lolos).
- [ ] Uji getar/jatuh ringan: tidak ada sambungan lepas.
- [ ] Charging di dalam casing: suhu TP4056 tidak > 60 °C.

## Catatan hasil
| Tanggal | Bagian | Hasil | Tindak lanjut |
|---|---|---|---|
| | | | |

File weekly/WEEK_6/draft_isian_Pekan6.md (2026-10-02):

# Draft isian: LAPORAN KEMAJUAN Pekan 6 Group 13

Periode: 28 Sep - 3 Okt 2026. Hanya hal BARU di Pekan 6 (Pekan 2-5 lihat `Riwayat_Progres_Pekan2-5.md`).
Bagian bertanda `[ISI]` perlu diputuskan tim. Angka dan temuan di bawah sudah diverifikasi lewat EasyEDA (DRC 0 error) dan OpenSCAD.

## Ringkasan
Pekan ini fokus mematangkan desain hardware setelah audit skematik. Routing PCB Vest Node diulang, daya diubah (AMS1117 dihapus, boost 5 V, gating GPS dan sensor air lewat MOSFET), board ESP32 disamakan dengan komponen yang dibeli (ESP32-DevKitC V4), dan casing Vest Node dibuat ulang mengikuti PCB. Ketiga PCB sudah memiliki Gerber baru dengan DRC 0 error.

## Perubahan scope (catat di laporan)
- Sensor VL53L0X (anti-crush) dihapus: berisiko banyak false positive saat pandu menempel dinding kapal tanpa terjepit. Deteksi difokuskan ke jatuh (MPU-6050) dan Man Overboard (sensor air). BME680 sudah dihapus sejak Pekan 2.
- Buzzer di Vest Node dihapus. Alarm bunyi ada di Edge Gateway.
- Sensor air diganti ke XKC-Y25 (non-kontak) untuk ketahanan korosi air laut; membutuhkan 5 V sehingga ditambah modul boost.

## Realisasi kegiatan (tabel Pekan 6)
| Kegiatan | Hasil |
|---|---|
| Audit skematik 3 PCB | Ditemukan: AMS1117 tidak dapat 3,3 V dari Li-ion (dropout), dua sumber 3V3 paralel, tombol sesaat dipakai sebagai saklar daya, pin 1 RA-02 salah dihubungkan ke GND (itu pin antena), GND tambahan RA-02 belum tersambung, ESP32 Gateway tanpa rangkaian program/EN, gate MOSFET sirine tanpa pull-down. Dokumen: `Audit_Skematik_Status.md`. |
| Perbaikan PCB1 (Vest) | Daya: U3/C1/C2 dihapus, TP4056 ke VBAT_RAW, boost 5 V untuk ESP32 dan XKC-Y25. Tombol power jadi input GPIO (deep sleep di firmware). Gating GPS dan XKC-Y25 via MOSFET (standby hemat). RA-02 diperbaiki. Footprint ESP32 diganti ke DevKitC V4. TP4056 di sisi bawah dan diputar agar USB-C menghadap dinding. Trek VBAT_POS 20 mil. DRC 0 error. |
| Perbaikan PCB3 (Gateway) | ESP32 diganti ke DevKitC V4, regulator dan header program dihapus (sudah ada di DevKit), RA-02 diperbaiki, pull-down gate sirine, SD_CS dipindah dari pin strapping. DRC 0 error. |
| Perbaikan PCB2 (Helmet) | Ditambah C2 100 uF tantalum 6,3 V di rel CR2032 untuk menahan lonjakan arus BLE. Outline diperpanjang. DRC 0 error. |
| Gerber ketiga board | `hardware/gerber/` (3 Okt 2026). Belum dipesan. |
| Casing Vest Node v5 | Dibuat ulang mengikuti PCB1: 114 x 101 x 36,6 mm (PETG). Bukaan: USB-C charging (dinding kiri), ekstensi micro-USB DevKit dan SMA (dinding bawah), plunger tombol power/SOS di tutup, boost digantung di tutup. Validasi dimensi otomatis lulus. |
| Cross-check BOM | Ditemukan selisih BOM vs desain (lihat bawah). |

## Selisih BOM vs desain (butuh tindak lanjut Rafif/Gibran)
- Hapus: VL53L0X x2 (Rp80k) dan BME680 (Rp170k) -> hemat Rp250k.
- Tambah: XKC-Y25, modul boost 5 V, antena + SMA bulkhead untuk Vest, MOSFET (AO3401A, 2N7002), resistor/kapasitor, IRLZ44N (Gateway), kapasitor tantalum 100 uF (Helmet), kabel ekstensi panel-mount micro-USB.
- ESP32 DevKit dan LoRa Vest/Gateway: BOM menandai FALSE padahal link sama dengan yang TRUE; konfirmasi jumlah.
- Modul LoRa yang dibeli (SX1276 915 MHz, bentuk RFM95/XL1276) BUKAN Ra-02; footprint PCB memakai Ra-02. Dinilai: beli Ra-02 atau sesuaikan footprint.
- Harga ESP32 di listing Rp128k vs BOM Rp80k. Total BOM Rp2,495 jt vs dana Rp2 jt.

## Kendala dan solusi
| Kendala | Solusi |
|---|---|
| Desain awal tidak cocok dengan komponen yang dibeli (ESP32 dan LoRa) | Desain disesuaikan: footprint DevKitC V4; LoRa menunggu konfirmasi |
| Port USB beberapa modul menghadap ke dalam papan, tidak terjangkau dari dinding | TP4056 diputar 180 derajat; DevKit memakai kabel ekstensi panel-mount |
| Auto-router menimpa lebar trek daya | Dilebarkan manual per net; VBOOST_5V dan VBAT_RAW tetap 10 mil karena clearance |

## Belum selesai / rencana Pekan 7
1. Ukur board ESP32 fisik (jarak baris pin) dan cek urutan pin LoRa, TP4056, boost sebelum order PCB.
2. Pesan modul yang kurang; update BOM dan kolom harga final.
3. Uji rakit di breadboard/perfboard sebelum fabrikasi.
4. Firmware: deep sleep + wake RTC, kontrol GPS_EN/XKC_EN, deteksi jatuh.
5. Casing Helmet Node dan Gateway disesuaikan ke PCB baru.
6. Persentase progres: `[ISI]` (PCB 3 unit desain selesai, belum fabrikasi).

## Dokumentasi (gambar)
- `PANDU_VestNode_Casing.png`, `_exploded.png`, `_top.png` (render OpenSCAD v5).
- Screenshot EasyEDA PCB1/PCB2/PCB3 (ambil ulang dari editor; folder screenshots sengaja tidak di repo).

## Catatan sebelum disubmit
- Angka "akurasi sensor 96,2%" di laporan kelompok lama tidak punya data pengujian; hapus atau lengkapi datanya.
- Samakan penyebutan ESP32 (proposal WROOM-32; laporan lama C3/DevKitM-1; desain final DevKitC V4 WROOM-32D).
- Gerber lama di `weekly/WEEK_6/Gerber` jangan dipesan.

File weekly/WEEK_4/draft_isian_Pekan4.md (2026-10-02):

# Draft isian — LAPORAN KEMAJUAN Pekan 4 Group 13

Tinggal copy-paste ke bagian yang kosong di file .docx. Yang ditandai
`[PILIH SALAH SATU]` perlu diputuskan tim dulu sebelum dipaste.

## Checklist — semua yang harus diisi

- [ ] Section 3: centang checkbox No 3 & 4 jadi "Belum"
- [ ] Section 5: update tugas Calvin (tambahan validasi dimensi via OpenSCAD)
- [ ] Section 4: isi kolom "Penanggung Jawab" di 4 baris (kosong semua)
- [ ] Section 4: isi kolom "Hasil" baris 2 (3D model) & baris 3 (mockup dashboard)
- [ ] Section 6: isi "Status integrasi" (Hardware)
- [ ] Section 6: ganti "..." di Software (Fitur selesai & masih dikembangkan)
- [ ] Section 6: ganti "..." di Mekanik/Biomedik + putuskan angka 18mm vs 23mm
- [ ] Section 7: tambah Gambar 7 & 8 (render OpenSCAD Vest Node & Helmet Node) — lihat di bawah
- [ ] Section 8: isi tabel pengujian (simulasi/verifikasi dimensi) + Analisis Singkat
- [ ] Section 9: isi 3 baris Kendala dan Solusi (kosong total)
- [ ] Section 2: tambah kalimat soal validasi dimensi ke ringkasan (opsional tapi disaranin)
- [ ] Section 11: perjelas task Yoga (revisi dimensi spesifik apa)
- [ ] Section 12: pertimbangkan naikin persentase "Pengujian" (masih 0%, padahal Section 8 sekarang ada isinya)
- [ ] Section 13: tambah kalimat soal temuan validasi ke kesimpulan (opsional tapi disaranin)

---

## 3. Target Pekan Ini — centang checkbox

- No 3 "Perancangan mockup dashboard awal": **☑ Belum** (baru tahap persiapan/referensi, belum jadi mockup)
- No 4 "Order semua komponen lewat e-commerce": **☑ Belum** (baru 80%, sebagian belum sampai)

---

## 4. Realisasi Kegiatan

**Baris 1 — PCB Design**
- Penanggung Jawab: `Gibran, Rifat`

**Baris 2 — 3D model**
- Penanggung Jawab: `Yoga`
- Hasil: `Draft 3D casing P.A.N.D.U selesai dibuat menggunakan Autodesk Fusion 360 (Gambar 1). Blueprint 2D presisi dengan dimensi 55 x 65 x 18 mm telah disusun sebagai acuan tata letak komponen pada PCB (Gambar 2).`

**Baris 3 — Perancangan mockup dashboard**
- Penanggung Jawab: `Rafif, Calvin`
- Hasil: `Persiapan perancangan mockup dashboard sesuai layout device yang akan ditentukan. Belum masuk tahap desain visual final karena masih menunggu layout device dikunci.`

**Baris 4 — Order komponen lewat e-commerce**
- Penanggung Jawab: `Rafif`

---

## 2. Ringkasan Kemajuan Pekanan — tambahan (opsional)

Tambahkan 1 kalimat di akhir paragraf yang sudah ada:
`Validasi dimensi casing terhadap komponen elektronik juga dilakukan menggunakan simulasi parametrik (OpenSCAD), yang menemukan perlunya revisi ukuran casing sebelum masuk tahap cetak 3D.`

---

## 5. Kemajuan Tiap Anggota — update baris Calvin

Tugas Pekan Ini (tambahkan ke isi yang sudah ada, jangan diganti):
`Melakukan persiapan perancangan mockup dashboard sesuai layout device yang nanti ditentukan.`
`Melakukan validasi dimensi casing Vest Node Master & Helmet Node menggunakan model parametrik (OpenSCAD) untuk memastikan komponen elektronik (baterai, PCB, modul LoRa/GPS, ESP32-C3) muat sesuai rancangan sebelum masuk tahap cetak 3D.`

Persentase Penyelesaian: `100%` (tetap, dua-duanya sudah selesai dikerjakan)

---

## 6. Hasil Implementasi

**Hardware — Status integrasi:**
`Belum ada integrasi fisik antar unit. Ketiga PCB (Vest Node Master, Helmet Node, Edge Gateway) masih dalam tahap desain layout di EasyEDA Pro, belum masuk tahap fabrikasi/assembly.`

**Software — Fitur yang telah selesai:**
`Belum ada fitur software yang selesai pada pekan ini.`

**Software — Fitur yang masih dikembangkan:**
`Mockup dashboard (baru tahap persiapan referensi desain). Firmware embedded dan backend belum dimulai, menunggu PCB dan komponen selesai.`

**Mekanik/Biomedik:**
`Draft 3D casing P.A.N.D.U selesai dibuat di Autodesk Fusion 360 (Gambar 1).`
`Blueprint 2D presisi dengan dimensi 55 x 65 x [PILIH SALAH SATU: 18 / 23] mm telah disusun sebagai acuan tata letak komponen PCB (Gambar 2).`

> Catatan buat tim (hapus sebelum submit): dimensi tebal (depth) casing
> awalnya 18mm, tapi hasil validasi ulang terhadap baterai 18650 (Ø18mm)
> menunjukkan 18mm nggak cukup setelah dikurangi dinding cetak 3D —
> direvisi jadi 23mm. Kalau laporan ini mau tetap pakai 18mm (angka asli
> Yoga), berarti masih perlu dikoordinasikan revisinya ke pekan depan.
> Kalau mau langsung pakai angka yang udah divalidasi, ganti ke 23mm.

---

## 8. Pengujian yang Dilakukan

> Ini bukan pengujian fisik (belum ada hardware jadi), tapi pengujian
> simulasi/verifikasi desain -- tetap valid dimasukkan ke tabel ini.

| Parameter | Target | Hasil | Status |
|---|---|---|---|
| Kesesuaian dimensi internal casing Vest Node vs komponen elektronik (baterai 18650, ESP32-WROOM-32, modul LoRa SX1276, GPS NEO-6M) | Seluruh komponen muat di dalam casing tanpa overlap/tabrakan | Ketebalan awal 18mm tidak cukup (baterai overlap 2mm); setelah direvisi ke 23mm dan divalidasi ulang lewat simulasi parametrik (OpenSCAD), seluruh komponen tervalidasi muat | Lulus (setelah revisi) |

**Analisis Singkat:**
`Verifikasi dimensi dilakukan secara simulasi menggunakan model parametrik (OpenSCAD) sebelum casing masuk tahap cetak 3D. Ditemukan bahwa ketebalan awal 18mm tidak mengakomodasi baterai 18650 (diameter 18mm) setelah diperhitungkan dengan tebal dinding cetak. Revisi ketebalan menjadi 23mm, serta revisi tinggi casing dari 65mm menjadi 70mm untuk mengakomodasi panjang baterai (65mm) beserta dinding di kedua ujungnya. Hasil render 3D (Gambar 7, Gambar 8) dan pengecekan otomatis pada model mengonfirmasi seluruh komponen tervalidasi muat setelah revisi.`

**Dokumentasi pendukung:** lihat Gambar 7 & 8 di Section 7 (sudah direferensikan di Analisis Singkat sebagai "Gambar 7, 8").

---

## 7. Dokumentasi Hasil — tambahan gambar

Tambahkan di bagian "Lainnya" (setelah Gambar 6), lanjutan penomoran:

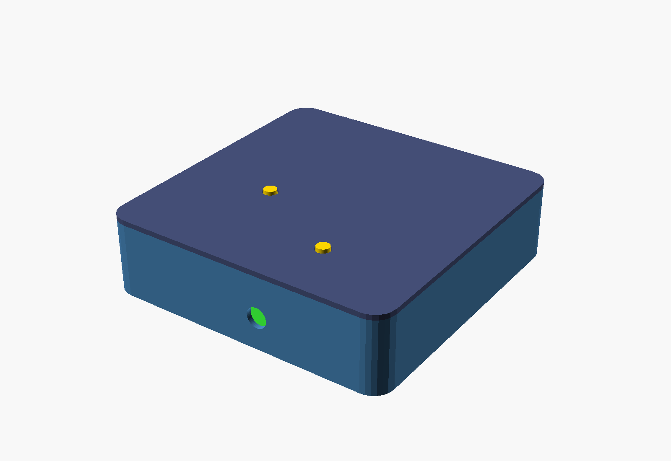
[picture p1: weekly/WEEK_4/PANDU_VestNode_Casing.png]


Gambar 7. Hasil simulasi render 3D casing Vest Node Master untuk validasi kesesuaian dimensi internal komponen (baterai 18650, PCB, modul LoRa/GPS) menggunakan OpenSCAD.

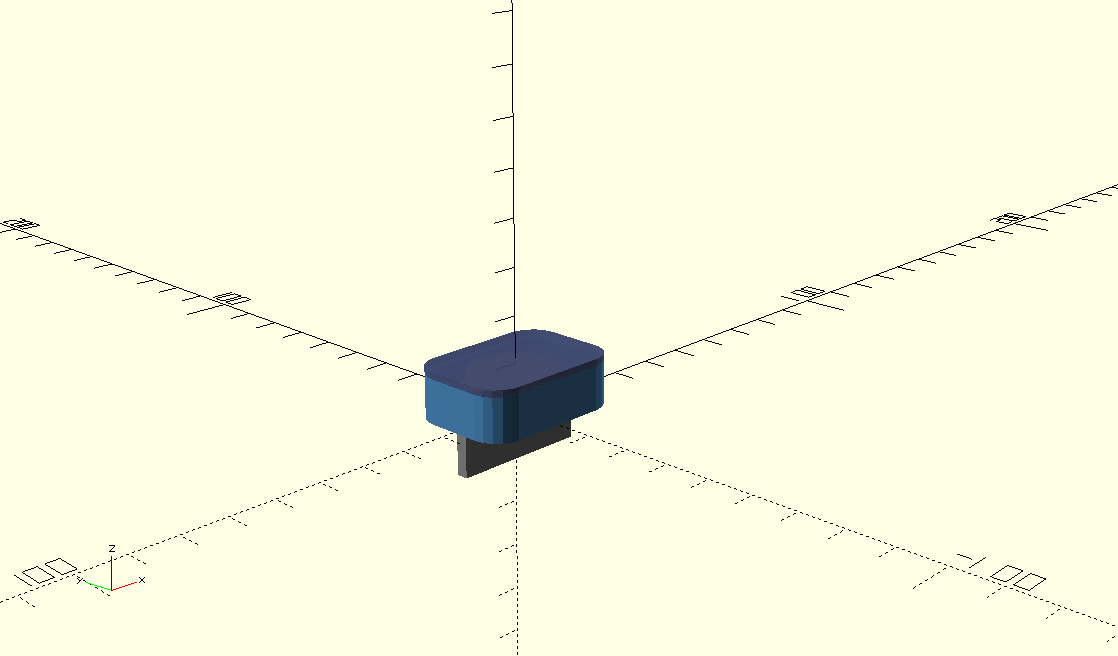
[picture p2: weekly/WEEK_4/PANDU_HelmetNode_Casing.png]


Gambar 8. Hasil simulasi render 3D casing Helmet Node untuk validasi kesesuaian dimensi internal komponen (ESP32-C3 SuperMini, CR2032, tab mounting Euroslot) menggunakan OpenSCAD.

> Catatan: re-export dulu kedua PNG ini setelah render ulang model (ada
> revisi case_h Vest Node 65mm -> 70mm), biar gambar yang masuk laporan
> nunjukkin hasil yang udah bener, bukan yang masih ada baterai nongol.

---

## 11. Rencana Kerja Pekan Berikutnya — perjelas baris Yoga

Ganti "Finalisasi Desain 3D Casing" jadi lebih spesifik:
`Finalisasi Desain 3D Casing (termasuk revisi dimensi hasil validasi: tebal 18mm->23mm, tinggi 65mm->70mm)`

---

## 12. Persentase Progress Proyek — pertimbangkan

Baris "Pengujian" masih 0%, tapi Section 8 sekarang ada isi (pengujian
simulasi dimensi). Diskusikan sama tim: naikkan jadi `5%` (baru mulai,
masih simulasi bukan fisik) atau tetap `0%` kalau tim mau "Pengujian"
cuma dihitung pas ada hardware fisik. Kalau naik ke 5%:
`Progress Total = 27,25% + (15% x 5%) = 28%`

---

## 13. Kesimpulan — tambahan (opsional)

Tambahkan 1 kalimat di akhir paragraf yang sudah ada:
`Validasi dimensi casing menggunakan simulasi parametrik turut dilakukan pekan ini, menemukan kebutuhan revisi ukuran (ketebalan dan tinggi) sebelum desain 3D dikunci final oleh Yoga.`

---

## 9. Kendala dan Solusi

| Kendala | Dampak | Solusi yang Dilakukan |
|---|---|---|
| Routing jalur kelistrikan PCB Edge Gateway (Unit 3) belum selesai | PCB Edge Gateway belum bisa difinalisasi & ikut masuk antrian order bareng 2 unit lain | Melanjutkan routing di pekan berikutnya, diprioritaskan Gibran/Rifat sebelum target order PCB 26 September 2026 |
| Sebagian komponen yang dipesan lewat e-commerce belum sampai | Menghambat rencana perakitan & pengujian komponen individual di pekan berikutnya | Memantau status pengiriman secara berkala; siapkan alternatif vendor kalau keterlambatan signifikan |
| Dimensi awal blueprint casing (55x65x18mm) ternyata tidak cukup untuk baterai 18650 (Ø18mm) setelah diperhitungkan dengan tebal dinding cetak 3D | Yoga perlu merevisi model 3D casing di Fusion 360 (ketebalan 18mm -> 23mm) sebelum desain dikunci final | Ketebalan direvisi menjadi 23mm; divalidasi ulang menggunakan simulasi parametrik (OpenSCAD) untuk memastikan seluruh komponen (baterai, PCB, modul GPS/LoRa) muat sebelum fabrikasi |

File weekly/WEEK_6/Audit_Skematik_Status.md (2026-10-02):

# Audit skematik PANDU: temuan dan status (Pekan 6)

Menggantikan status di `PCB1_Verifikasi_Skematik.md`. Tanggal: 2 Okt 2026.

## Keputusan desain Pekan 6
- Sensor Vest: MPU6050 (jatuh), XKC-Y25 (air/MOB), GPS, LoRa. **Tanpa VL53L0X dan BME680** (ToF rawan false positive saat crew menempel dinding).
- Board ESP32 Vest: **ESP32-WROOM-32 DevKit klasik** (nama part di EasyEDA "DEVKITM-1" menyesatkan).
- Daya: baterai 18650 > TP4056 > `VBAT_RAW` (tanpa saklar seri). Boost 5 V selalu aktif, menyuplai pin 5V ESP32. AMS1117 dan C1/C2 dihapus.
- Tombol power SW1 (tact + rubber boot): input GPIO RTC (IO13), toggle deep sleep di firmware.
- Gating daya (arus standby rendah): GPS lewat P-MOSFET Q1 (`GPS_EN`=IO4), XKC-Y25 lewat Q2 + level shifter Q5 (`XKC_EN`=IO2).
- `BTN_SOS` di IO27 (RTC) agar SOS bisa membangunkan rompi.

## PCB1 (Vest Node Master)
| Temuan | Status |
|---|---|
| AMS1117 tidak cukup dropout dari Li-ion | Beres (dihapus) |
| Dua sumber 3V3 paralel | Beres |
| Tact switch sebagai saklar daya | Beres (jadi input GPIO) |
| RA-02: pin 1 itu ANT, GND = pin 2/9/16 | Beres (`LORA_ANT`, GND tersambung) |
| `GPS_EN` dan GND RA-02 sempat tidak tersambung (kabel meleset) | Beres, diverifikasi DRC "Pins floating" |
| Footprint ESP32 (17 pin/sisi, 0,9") tidak cocok DevKit klasik 30/38 pin | **Terbuka**: butuh nama/foto board |
| Urutan pin TP4056 dan boost | **Terbuka**: cek modul fisik |
| Trek daya kembali 10 mil setelah auto-route | **Terbuka** |
| Gerber PCB1 | **Perlu ekspor ulang** |

## PCB3 (Edge Gateway)
| Temuan | Status |
|---|---|
| ESP32 tanpa pull-up EN, tanpa BOOT, tanpa header program | Beres (R2 10k, C3 100 nF, J1 1x6) |
| Pin 1 RA-02 ke GND | Beres (`LORA_ANT`) |
| Gate MOSFET tanpa pull-down | Beres (R3 100k) |
| EP ESP32 tidak ke GND | Beres |
| IRFZ44N bukan logic-level | **Terbuka**: beli IRLZ44N (footprint sama) |
| USB-C tanpa resistor CC 5,1k | **Terbuka** (pakai kabel A-ke-C untuk PoC) |
| Dioda flyback (jika beban induktif) | Terbuka, bergantung beban |
| Gerber PCB3 | **Perlu ekspor ulang** |

## PCB2 (Helmet Node)
- CR2032 menyuplai ESP32-C3 lewat dioda: lonjakan arus BLE berisiko brownout. Tambah kapasitor 100-220 uF low-ESR di jalur 3V0 atau pakai LiPo kecil. **Terbuka.**

## Lintas board
- RA-02 = SX1278 **433 MHz**, proposal menyebut **915 MHz** (Indonesia: 920-923 MHz). Perlu dicek modul yang dipesan.
- Gerber lama di `WEEK_6\Gerber` **jangan dipesan**.

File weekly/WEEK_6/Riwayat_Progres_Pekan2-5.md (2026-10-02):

# Riwayat progres PANDU, Pekan 2–5 (ringkasan agar Pekan 6 tidak redundan)

Sumber: laporan kemajuan kelompok dan laporan individu Calvin (WEEK_2–WEEK_5).

| Pekan | Tanggal | Yang sudah dilaporkan |
|---|---|---|
| 2 | 31 Agt–5 Sep | On-site visit kapal SPJM (Tanjung Priok). Verifikasi spesifikasi komponen. **Sensor BME680 dipangkas** (tidak relevan). Draft BoM. Masalah: spesifikasi belum IP67. Skenario diubah ke Proof of Concept. Progres total 16,25%. |
| 3 | 7–12 Sep | **Skematik 3 unit selesai** di EasyEDA Pro (Vest, Helmet, Edge Gateway). Pemesanan komponen dimulai. Draft 3D casing Fusion 360 dan blueprint 2D 55×65×18 mm. Wireframe dashboard (Figma). Progres 24,25%. |
| 4 | 14–19 Sep | Laporan menyatakan **PCB Vest dan Helmet "selesai"**, Edge Gateway masih kendala routing. Order komponen 80%. Validasi OpenSCAD: casing direvisi 18→23 mm tebal dan 65→70 mm tinggi (baterai 18650). Progres 27,25%. |
| 5 | 21–26 Sep | Dashboard: marine pilot view dan supervisor view, wireframe HTML/CSS/JS (repo `calvinkatoroy/pandu-dashboard`). Menunggu hardware stack dan endpoint ESP32. |

## Yang BARU di Pekan 6 (jangan dilaporkan ulang sebagai hasil lama)

- **Routing ulang PCB1** sampai bersih DRC. Klaim "PCB Vest selesai" di Pekan 4 ternyata belum final. Placement dirombak. Papan 108×95 mm, tombol dan modul diatur ulang.
- **Casing Vest Node dibuat ulang mengikuti PCB**: 114×101×30,6 mm. Ini menggantikan 55×65×23/70 mm dari Pekan 4. Termasuk bukaan USB, SMA, dan 2 tombol, serta modul boost yang digantung di tutup.
- **Perubahan desain**: buzzer dihapus dari Vest, sensor air diganti **XKC-Y25 (VCC 5 V via boost)**, TP4056 dipindah ke Bottom, trek daya dilebarkan (20 mil).
- **PCB3 (Edge Gateway) diselesaikan.** PCB1 dan PCB3 dibuat lebih kompak.
- **Audit 3 board** dan **export Gerber ketiganya** (belum boleh dipesan, lihat bawah).
- **Verifikasi skematik PCB1 pin-per-pin** (`PCB1_Verifikasi_Skematik.md`). Temuan: AMS1117 tidak bisa 3,3 V dari Li-ion, dua sumber 3V3 diparalel, tact switch dipakai sebagai saklar daya, pin GND RA-02 kurang.

## Catatan konsistensi

- BME680 sudah dibuang sejak **Pekan 2**. Keputusan "tidak pakai VL53L0X" belum tercatat di laporan mana pun. Itu perubahan scope baru, catat di Pekan 6.
- Skematik sedang diperbaiki (U3/C1/C2 dihapus, pin 5V ESP32 ke boost), jadi Gerber lama tidak dipesan dulu.
- Angka "akurasi sensor 96,2%" muncul di semua laporan kelompok tanpa data pengujian. Cek ulang sebelum dikumpulkan.
- Laporan Pekan 4 menyebut ESP32-C3 dan DevKitM-1, sedangkan proposal menyebut ESP32-WROOM-32. Samakan.

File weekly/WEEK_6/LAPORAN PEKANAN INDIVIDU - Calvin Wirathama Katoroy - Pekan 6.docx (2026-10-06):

LAPORAN PEKANAN INDIVIDU

Capstone Project Desain Proyek 2

A. Identitas Mahasiswa

Item | Keterangan
Nama | Calvin Wirathama Katoroy
NPM | 2306242395
Program Studi | Teknik Elektro
Kelompok | 13
Judul Proyek | P.A.N.D.U (Perangkat Alarm Nirkabel Deteksi Urgensi)
Pekan ke- | 6
Periode Tanggal | 28 September - 3 Oktober 2026
Dosen Pembimbing | Tomy Abuzairi, S.T., M.Sc., Ph.D.

B. Target Mingguan

Target yang direncanakan pada awal pekan berdasarkan WBS dan pembagian tugas kelompok.

No | Target Pekerjaan | Luaran yang Diharapkan | Status
1 | Audit skematik 3 PCB (Vest, Helmet, Edge Gateway) dan perbaikan desain PCB hingga siap fabrikasi | Skematik & PCB terkoreksi, DRC 0 error, Gerber baru | ☐ Belum ☑ Selesai
2 | Merancang ulang casing Vest Node mengikuti PCB final | Model OpenSCAD casing + render + validasi dimensi | ☐ Belum ☑ Selesai
3 | Cross-check BOM dengan desain dan komponen yang sudah dibeli | Daftar selisih BOM vs desain | ☐ Belum ☑ Selesai
4 | Finalisasi daftar fitur dashboard & tech stack aplikasi mobile (rencana Pekan 5) | Daftar fitur & keputusan tech stack | ☑ Belum ☐ Selesai

C. Logbook Aktivitas Harian

Hari/Tanggal | Uraian Aktivitas | Waktu (Jam) | Bukti/Dokumen
Senin (28 Sep) | [ISI: kegiatan 28 Sep] | [ISI] | -
Selasa (29 Sep) | [ISI: kegiatan 29 Sep] | [ISI] | -
Rabu (30 Sep) | [ISI: kegiatan 30 Sep] | [ISI] | -
Kamis (1 Okt) | Review proposal & riwayat Pekan 2-5; menetapkan perubahan scope Vest Node (tanpa VL53L0X/BME680, fokus jatuh & sensor air); audit skematik PCB1 dan redesain daya (tanpa AMS1117, boost 5 V, tombol power GPIO, MOSFET untuk GPS & XKC-Y25); perbaikan skematik, update PCB dan routing ulang PCB1 (DRC 0 error) | 8 | EasyEDA project Pandu-Capstone; Audit_Skematik_Status.md
Jumat (2 Okt) | Audit dan perbaikan PCB3 Edge Gateway; mengganti footprint ESP32 PCB1 & PCB3 ke DevKitC V4 sesuai komponen yang dibeli; cross-check BOM (Google Sheets) dengan desain; membuat repository GitHub pandu-capstone dan HANDOVER.md | 7 | github.com/calvinkatoroy/pandu-capstone
Sabtu (3 Okt) | Menambah kapasitor tantalum 100 uF di PCB2; ekspor Gerber 3 board; memutar TP4056 agar USB-C menghadap dinding; membuat ulang casing Vest Node v5 (OpenSCAD); audit dan update Laporan Kemajuan Kelompok Pekan 6 (bagian Calvin) | 7 | hardware/gerber/; PANDU_VestNode_Casing.scad; commit Git

Total Jam Kerja Minggu Ini: [ISI] Jam

D. Realisasi Pekerjaan

1. Aktivitas yang Berhasil Diselesaikan

Tuliskan hasil pekerjaan yang benar-benar telah selesai.

- Audit skematik tiga PCB dan perbaikan temuan: AMS1117 tidak mendapat 3,3 V dari Li-ion, dua sumber 3V3 paralel, tombol sesaat dipakai sebagai saklar daya, pin 1 RA-02 (antena) salah terhubung ke GND, GND tambahan RA-02 belum tersambung, ESP32 Gateway tanpa rangkaian EN/program, gate MOSFET sirine tanpa pull-down.
- Redesain daya Vest Node: baterai 18650 > TP4056 > boost 5 V; tombol power berupa tact switch GPIO (toggle deep sleep di firmware, tahan air dengan boot karet); GPS dan sensor air XKC-Y25 dihemat lewat MOSFET.
- Penyesuaian footprint ESP32 PCB1 dan PCB3 ke DevKitC V4 (komponen yang dibeli), routing ulang, DRC 0 error / 0 ratline pada ketiga board; PCB2 ditambah tantalum 100 uF di rel CR2032.
- Perancangan ulang casing Vest Node v5 (PETG, 114 x 101 x 36,6 mm), cross-check BOM, pembuatan repository dan HANDOVER.md, serta audit dan update Laporan Kemajuan Kelompok Pekan 6 bagian Calvin.

2. Luaran yang Dihasilkan

- Gerber baru PCB1, PCB2, PCB3 (hardware/gerber/, 3 Okt 2026; belum dipesan) dan dokumen Audit_Skematik_Status.md
- Model casing Vest Node v5 (PANDU_VestNode_Casing.scad) beserta render dan validasi dimensi — repository: github.com/calvinkatoroy/pandu-capstone
- Daftar selisih BOM vs desain (hapus VL53L0X/BME680; tambah XKC-Y25, boost 5 V, MOSFET, antena + SMA, dll.)
- Repository pandu-capstone (weekly, hardware, docs) + HANDOVER.md dan update Laporan Kemajuan Kelompok Pekan 6 (bagian Calvin)

E. Capaian Teknis Mingguan

Komponen/Subsistem yang Dikerjakan (pilih sesuai tugas)

Subsistem | Target | Realisasi | Persentase
Hardware | Audit skematik & perbaikan PCB1-3, Gerber siap | Skematik terkoreksi, PCB DevKitC V4, DRC 0 error, Gerber 3 board (belum dipesan) | 90%
Software | - | - | -
Mekanik | Casing Vest Node mengikuti PCB final | Casing v5 (OpenSCAD) tervalidasi dimensi; Helmet & Gateway belum | 70%
Pengujian | - | - | -
Dokumentasi | Dokumentasi audit, BOM, handover, laporan | Audit_Skematik_Status, repo + HANDOVER.md, update laporan kelompok | 100%

Ringkasan Kemajuan

Pekan ini pekerjaan Calvin berfokus pada hardware: audit skematik ketiga PCB, redesain daya Vest Node (tanpa AMS1117, boost 5 V, tombol power GPIO, gating GPS dan sensor air lewat MOSFET), penyesuaian footprint ESP32 ke DevKitC V4, serta pembuatan Gerber baru dengan DRC 0 error. Scope Vest Node disederhanakan (tanpa VL53L0X dan BME680) untuk menghindari false positive. Casing Vest Node dibuat ulang (v5) mengikuti PCB, dan cross-check BOM menemukan sejumlah selisih yang perlu ditindaklanjuti. PCB belum dipesan karena ukuran fisik modul (ESP32, LoRa, TP4056, boost) masih harus diverifikasi. Finalisasi fitur dashboard dan tech stack mobile belum dikerjakan pekan ini.

F. Permasalahan dan Kendala

No | Kendala | Dampak | Tingkat Risiko
1 | Desain awal tidak cocok dengan komponen yang dibeli: footprint ESP32 salah (DevKitC V4) dan modul LoRa yang dibeli (SX1276 915 MHz) bukan Ra-02 | PCB harus diubah; order PCB ditunda hingga pinout dan ukuran modul fisik terverifikasi | Tinggi
2 | Port USB beberapa modul menghadap ke dalam papan sehingga tidak terjangkau dari dinding casing | Orientasi TP4056 diputar dan DevKit memakai kabel ekstensi micro-USB panel-mount; casing perlu dicek ulang dengan modul asli | Sedang
3 | BOM belum diperbarui dan melebihi dana (Rp2,495 jt vs Rp2 jt); beberapa komponen belum ada | Pembelian XKC-Y25, boost 5 V, SMD, dan antena tertunda; perlu keputusan tim | Sedang

Analisis Penyebab

Desain awal dibuat sebelum komponen final dibeli sehingga terdapat ketidaksesuaian footprint dan sistem daya; audit baru dilakukan pekan ini. Tim juga belum memperbarui BOM sehingga selisih baru ditemukan saat cross-check.

G. Tindakan Korektif dan Solusi

Kendala | Solusi/Tindak Lanjut | PIC | Target Penyelesaian
Footprint/pinout tidak cocok komponen fisik | Memakai ukuran resmi DevKitC V4 sementara; ukur modul fisik (jarak baris pin ESP32, pinout LoRa, TP4056, boost) sebelum order PCB | Calvin | 10 Oktober 2026
USB tidak terjangkau dari dinding casing | TP4056 diputar 180 derajat, ekstensi micro-USB panel-mount untuk DevKit; verifikasi dimensi dengan modul asli | Calvin | 10 Oktober 2026
BOM selisih dengan desain dan melebihi dana | Hapus VL53L0X/BME680 (hemat Rp250 rb), tambah komponen yang kurang, update sheet bersama Rafif/Gibran | Calvin, Rafif, Gibran | 10 Oktober 2026

H. Dokumentasi Kemajuan

Lampirkan:

- Foto kegiatan
- Foto perangkat/prototipe
- Screenshot software/dashboard
- Hasil pengujian
- Diagram revisi
- Bukti commit Git
- Bukti pembelian atau pengadaan (jika relevan)

Minimal 2-3 dokumentasi setiap pekan.

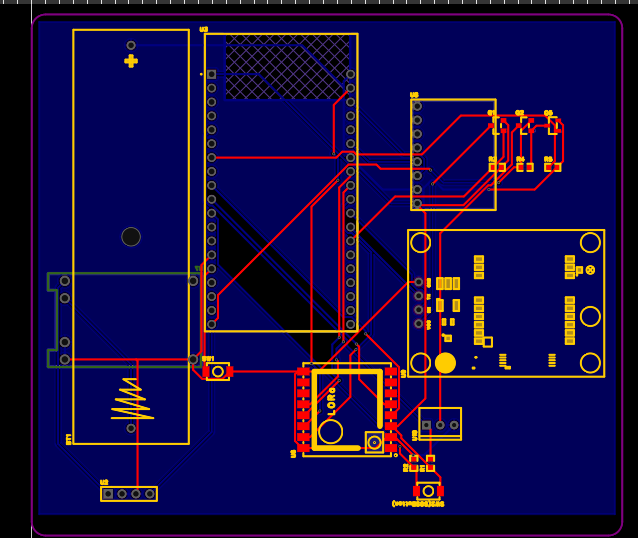
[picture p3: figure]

Gambar 1. Layout PCB1 Vest Node Master setelah audit (ESP32-DevKitC V4, TP4056, boost 5 V, RA-02), DRC 0 error.

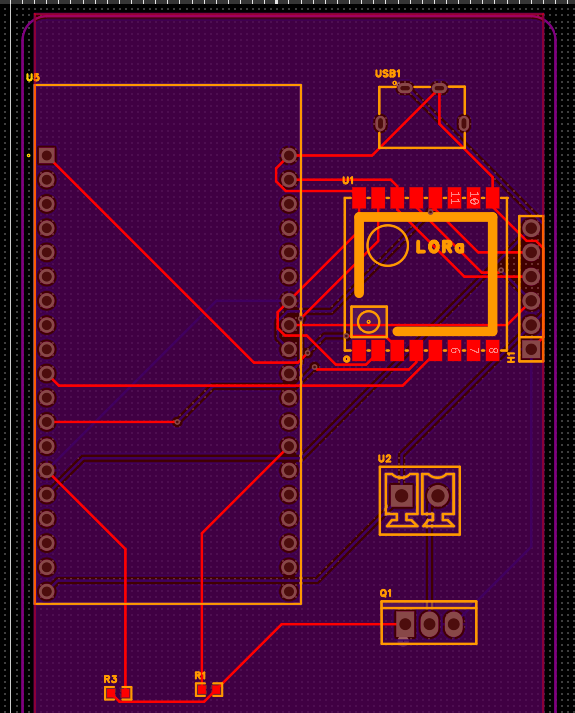
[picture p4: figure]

Gambar 2. Layout PCB3 Edge Gateway setelah diganti ke DevKitC V4, DRC 0 error.

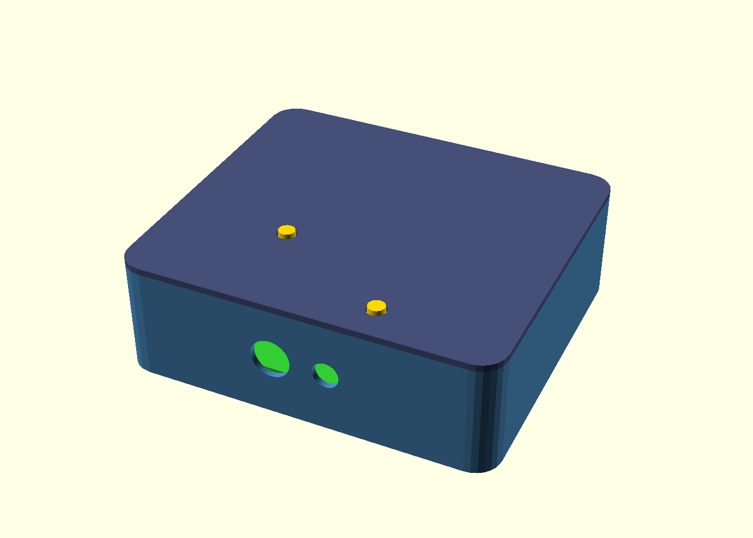
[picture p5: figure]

Gambar 3. Render casing Vest Node v5 (OpenSCAD, PETG) berukuran 114 x 101 x 36,6 mm. Repository: github.com/calvinkatoroy/pandu-capstone

I. Kontribusi Terhadap Tim

Koordinasi yang Dilakukan

- Diskusi tim: penetapan perubahan scope Vest Node (tanpa VL53L0X dan BME680; fokus deteksi jatuh dengan MPU-6050 dan sensor air) bersama anggota kelompok
- Koordinasi BOM: cross-check daftar komponen dengan Rafif dan Gibran (komponen yang sudah dibeli vs desain) serta serah-terima desain lewat repository dan HANDOVER.md
- Koordinasi dengan dosen: Belum ada sesi khusus minggu ini; pembahasan dilakukan internal tim

Kontribusi Pribadi

Berperan dalam mengaudit skematik ketiga PCB, mendesain ulang daya Vest Node, memperbaiki dan merouting ulang PCB1-PCB3 hingga DRC 0 error, mengekspor Gerber, merancang ulang casing Vest Node (OpenSCAD), melakukan cross-check BOM, serta menyiapkan repository dan dokumentasi (HANDOVER.md, laporan kelompok bagian Calvin).

J. Evaluasi Diri

Yang Berjalan Baik

- Audit skematik sebelum order PCB menemukan banyak kesalahan desain (daya, pin RA-02, rangkaian EN) yang tertangkap sebelum fabrikasi.
- Keputusan scope (tanpa VL53L0X/BME680) cepat disepakati dan menyederhanakan desain serta mengurangi biaya.
- Ketiga PCB dan casing Vest Node selesai desain dengan validasi otomatis (DRC dan cek dimensi).

Yang Perlu Diperbaiki

- Desain dibuat sebelum komponen final dipastikan sehingga banyak yang harus diulang; BOM dan desain perlu disinkronkan lebih awal.
- Fitur dashboard dan tech stack aplikasi mobile belum dikerjakan pekan ini karena fokus hardware.
- Ukuran fisik modul belum diverifikasi sehingga order PCB tertunda; perlu jadwal pengecekan fisik.

Pelajaran yang Didapat Minggu Ini

- Desain PCB harus mengacu pada modul yang benar-benar dibeli (nama listing dan ukuran), bukan hanya simbol library.
- Port USB dan akses fisik harus dipertimbangkan sejak desain PCB karena menentukan desain casing.
- Audit kelistrikan (sumber daya, pin strapping, pull-up/down) wajib dilakukan sebelum fabrikasi.

K. Rencana Pekan Berikutnya

No | Rencana Kegiatan | Target Luaran | Estimasi Jam
1 | Ukur modul fisik (ESP32, LoRa, TP4056, boost) dan sesuaikan footprint/casing | Verifikasi dimensi & pinout modul | 3 Jam
2 | Pesan modul yang kurang, update BOM, lalu order PCB | BOM final & PCB dipesan | 3 Jam
3 | Uji rakit perfboard dan mulai firmware (deep sleep, GPS_EN/XKC_EN, deteksi jatuh); lanjut fitur dashboard | Prototipe awal & firmware dasar | 6 Jam

L. Persetujuan

Mahasiswa

Nama: Calvin Wirathama Katoroy

Tanda tangan:

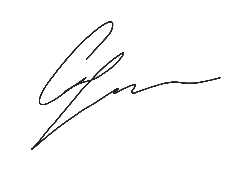
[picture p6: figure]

Tanggal: 3 Oktober 2026

Ketua Kelompok

Nama: Adhi Rajasa Rafif

Tanda tangan:

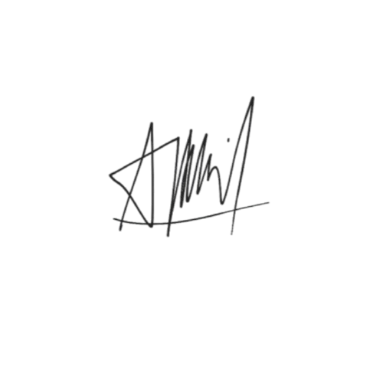
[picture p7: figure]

Tanggal: 3 Oktober 2026

Catatan Pembimbing

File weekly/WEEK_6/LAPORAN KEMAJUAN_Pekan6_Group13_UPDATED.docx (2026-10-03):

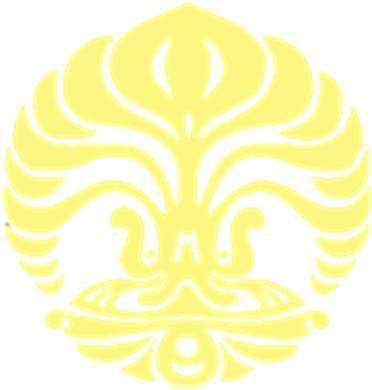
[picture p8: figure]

LAPORAN KEMAJUAN PEKANAN

DESAIN PROYEK TEKNIK ELEKTRO, KOMPUTER, BIOMEDIK 2

Judul Proyek : P.A.N.D.U: Perangkat Alarm Nirkabel Deteksi Urgensi

Kelompok : 13

Pekan Ke- : 6

Periode : 28 September - 3 Oktober 2026

Dosen Pembimbing : Tomy Abuzairi, S.T., M.Sc., Ph.D.

Ketua Kelompok : Adhi Rajasa Rafif (2306266943)

Anggota Kelompok :

- Adhi Rajasa Rafif (2306266943)
- Calvin Wirathama Katoroy (2306242395)
- M Gibran Arya Avicena (2306156643)
- Muhammad Rifat Faqih (2306250762)
- Tri Yoga Arsyad (2306161920)

1. Ringkasan Tentang Project

Wearable Safety Multi-Modul untuk pandu kapal dengan Deteksi Fall + Man Overboard (MOB) + APD compliance, dengan Emergency Beacon LoRa + GPS untuk rescue dispatch dalam detik. Tujuan khusus alat PANDU sebagai berikut:

- Menciptakan perangkat wearable keselamatan (Vest dan Helmet Node) berbasis multi-sensor dan ESP32, yang terintegrasi langsung dengan sistem komunikasi LoRa dan Edge Gateway, untuk memastikan bahwa transmisi sinyal darurat (SOS) tetap lancar di wilayah perairan dengan sinyal yang lemah (blank spot).
- Membangun sistem backend (protokol MQTTS) dan dashboard pemantauan berbasis web yang memungkinkan pelacakan lokasi pekerja (live tracking) dan pencatatan log insiden secara real-time.
- Mengimplementasikan lapisan kecerdasan (Intelligence Layer) dengan skenario bahaya berjenjang yang terhubung dengan SOP-AI (RAG dan LLM) untuk memberikan panduan evakuasi yang akurat dan menghindari kelelahan alarm (alarm fatigue) pada supervisor.

Sistem PANDU mengintegrasikan beberapa komponen perangkat keras utama untuk mendeteksi kecelakaan kerja secara akurat dan yang telah disesuaikan dengan spesifikasi yang dibutuhkan:

- Sensor giroskop MPU-6050 berfungsi sebagai detektor primer untuk mengukur perubahan orientasi tubuh pekerja dan mengenali insiden terjatuh.
- Sensor air non-kontak XKC-Y25 bekerja sebagai detektor sekunder untuk memvalidasi keberadaan air saat pekerja jatuh ke laut.
- LoRa (SX1276, 915 MHz) untuk mengirimkan sinyal alarm secara mandiri, Jaringan LoRa ini mentransmisikan paket data darurat dari perangkat pekerja menuju gateway kapal dengan jangkauan maksimal tiga mil.

2. Ringkasan Kemajuan Pekanan

Pada pekan ini, kegiatan proyek PANDU berfokus pada audit dan perbaikan desain hardware sebelum pemesanan PCB. Skematik tiga unit (Vest Node Master, Helmet Node, Edge Gateway) diaudit pin per pin di EasyEDA Pro dan ditemukan beberapa kesalahan desain yang telah diperbaiki: regulator AMS1117 tidak dapat menghasilkan 3,3 V dari baterai Li-ion, tombol sesaat dipakai sebagai saklar daya, pin antena modul LoRa tersambung ke GND, serta rangkaian pemrograman ESP32 pada Edge Gateway belum lengkap. Desain disesuaikan dengan komponen yang telah dibeli (ESP32-DevKitC V4); sensor anti-crush VL53L0X dan buzzer pada Vest Node dihapus untuk menekan false positive, dan sensor air diganti ke tipe non-kontak XKC-Y25 agar sesuai target IP67. Ketiga PCB telah lolos DRC (0 error) dan Gerber telah diekspor, namun pemesanan PCB ditunda sampai verifikasi fisik modul (pin LoRa, TP4056, ukuran board ESP32) selesai. Casing Vest Node dibuat ulang mengikuti PCB final (114 x 101 x 36,6 mm) menggunakan model parametrik OpenSCAD. Wireframe dashboard dari pekan sebelumnya tetap menjadi acuan visual; finalisasi fitur menunggu definisi endpoint ESP32.

3. Target Pekan Ini

No | Target | Status
1 | Order PCB (ditunda, lihat bagian 10) | ☐ Tercapai ☒ Belum
2 | Simulasi Assembly 3D (casing Vest Node, OpenSCAD) | ☒ Tercapai ☐ Belum
3 | Membuat design dashboard | ☐ Tercapai ☐ Belum

4. Realisasi Kegiatan

No | Kegiatan | Penanggung Jawab | Hasil

1

Revisi skematik dan PCB, persiapan order PCB

Gibran, Rifat, Calvin

Rancangan skematik harus direvisi lagi untuk mengurangi banyaknya false positive, kami menghilangkan penggunaan sensor jarak untuk anti-crushing dan kami mencoba mencari alternatif sensor kedalaman air yang kemungkinan lebih compatible dengan design yang direncanakan, karena alasan sebelumnya penggunaan sensor kedalaman air yang sebelumnya akan membuat device utama memiliki risiko kemasukan air yang cukup signifikan yang dampaknya bisa tidak sesuai dengan rencana device bisa menembus IP67

Tambahan Pekan 6 (audit dan perbaikan, Calvin): skematik tiga unit diaudit pin per pin dan diperbaiki (AMS1117 dihapus dan diganti modul boost 5 V, saklar daya jadi input GPIO, GPS dan sensor air via MOSFET, pin antena dan GND modul LoRa dikoreksi, rangkaian EN/pemrograman ESP32 Gateway dilengkapi, pull-down gate sirine). Footprint ESP32 disesuaikan dengan board yang dibeli (DevKitC V4). PCB1, PCB2, PCB3 lolos DRC (0 error) dan Gerber diekspor 3 Oktober 2026; order PCB ditunda sampai verifikasi fisik modul.
2 | 3D model casing | Calvin, Yoga | Casing Vest Node dibuat ulang mengikuti PCB final dengan model parametrik OpenSCAD (PETG, dinding 2 mm): dimensi luar 114 x 101 x 36,6 mm, bukaan USB-C pengisian (dinding kiri), ekstensi micro-USB ESP32 dan SMA antena LoRa (dinding bawah), plunger tombol power dan SOS pada tutup, serta modul boost digantung pada tutup. Validasi dimensi otomatis lulus (Gambar 11). Draft 3D awal di Autodesk Fusion 360 (Gambar 1) menjadi referensi bentuk.

3

Mockup Design Dashboard

Diskusi kebutuhan fitur dashboard PANDU telah dilakukan, menghasilkan penentuan dua tampilan pengguna (marine pilot view dan supervisor view) beserta data yang perlu ditampilkan pada masing-masing tampilan. Wireframe awal dashboard berbasis HTML telah selesai dibuat sebagai acuan visual, mencakup status keselamatan pilot, live tracking posisi, serta telemetri perangkat (baterai, sinyal LoRa, GPS fix). Finalisasi daftar fitur dan penentuan tech stack aplikasi mobile (Android & iOS) akan dilakukan pekan berikutnya, menunggu hardware stack dan definisi endpoint dari ESP32 (Vest Node, Helmet Node, Edge Gateway).

5. Kemajuan Tiap Anggota

Nama | Tugas Pekan Ini | Persentase Penyelesaian
Adhi Rajasa Rafif | Melakukan diskusi kebutuhan fitur dashboard PANDU bersama Calvin, termasuk penentuan dua tampilan pengguna (marine pilot view & supervisor view) dan data yang wajib ditampilkan di tiap tampilan Menyusun wireframe awal dashboard PANDU berbasis HTML sebagai acuan desain aplikasi mobile | 100%

Calvin Wirathama Katoroy

Mengaudit skematik tiga unit (Vest Node, Helmet Node, Edge Gateway) pin per pin dan memperbaiki temuan: AMS1117 dihapus (diganti boost 5 V), saklar daya dijadikan input GPIO, gating GPS dan sensor air via MOSFET, pin antena dan GND modul LoRa, rangkaian ESP32 Gateway, dan pull-down gate sirine.
Menyesuaikan PCB dengan komponen yang dibeli (ESP32-DevKitC V4), me-routing ulang ketiga PCB hingga DRC 0 error, dan mengekspor Gerber (tersimpan di repository tim).
Membuat ulang casing Vest Node (OpenSCAD) mengikuti PCB final 114 x 101 x 36,6 mm beserta validasi dimensi otomatis.
Melakukan cross-check BOM terhadap desain, serta menyusun dokumen audit dan handover.

Membangun wireframe interaktif dashboard PANDU (HTML/CSS/JS) sebagai acuan visual sebelum masuk tahap penentuan fitur final dan tech stack aplikasi mobile Android & iOS pekan berikutnya.

90%
M Gibran Arya Avicena | Membantu revisi rancangan skematik Vest Node untuk menekan tingkat false positive pada perangkat utama. Turut menyelesaikan pembaruan desain rangkaian skematik. Mempersiapkan pesanan cetak PCB dalam beberapa hari ke depan. | 90%
Muhammad Rifat Faqih | Rancangan skematik harus direvisi lagi untuk mengurangi banyaknya false positive terutama pada device utama yaitu vest node. untuk rangkaian schematic terbarunya sudah selesai dibuat, direncanakan beberapa hari kedepan rangkaian PCB akan selesai dibuat juga dan akan segara memesan PCB. Pembuatan Schematic dan design PCB helmet node dan edge gateway | 90%
Tri Yoga Arsyad | Membuat draf sketsa kasar 3D casing P.A.N.D.U dengan menggunakan Fusion 360, serta menyusun cetak biru (blueprint) 2D yang presisi dengan ukuran 55 x 65 x 18 mm sebagai acuan untuk tata letak komponen pada PCB yang dibuat oleh tim hardware. | 100%

6. Hasil Implementasi

Hardware

- Komponen yang telah direalisasikan:
  - PCB Design untuk seluruh ekosistem PANDU telah selesai dan lolos DRC (0 error): Unit 1 Vest Node Master (107,95 x 95,25 mm, ESP32-DevKitC V4), Unit 2 Helmet Node (ditambah kapasitor tantalum 100 uF pada rel baterai CR2032), dan Unit 3 Edge Gateway (ESP32-DevKitC V4). Gerber ketiga unit telah diekspor (3 Oktober 2026) dan belum dipesan.
- Status integrasi:
  - Belum ada integrasi fisik antar unit. Ketiga PCB telah selesai didesain dan diekspor ke Gerber, namun belum difabrikasi karena menunggu verifikasi fisik modul (urutan pin modul LoRa, TP4056, modul boost 5 V, dan ukuran board ESP32) serta pembelian modul yang masih kurang (sensor XKC-Y25 dan modul boost 5 V).

Software

- Fitur yang telah selesai:
  - Wireframe awal dashboard mobile PANDU (HTML) untuk tampilan marine pilot dan supervisor. Wireframe tersebut bisa diakses di repository github berikut: https://github.com/calvinkatoroy/pandu-dashboard
- Fitur yang masih dikembangkan:
  - Finalisasi daftar fitur dashboard dan pemilihan tech stack aplikasi mobile (Android & iOS). Firmware embedded dan backend (MQTTS) belum dimulai, menunggu hardware stack dan endpoint API dari ESP32 selesai didefinisikan oleh tim hardware.

Mekanik/Biomedik

- Casing Vest Node dibuat ulang mengikuti PCB final menggunakan model parametrik OpenSCAD (PETG, dinding 2 mm): dimensi luar 114 x 101 x 36,6 mm, dengan bukaan USB-C pengisian (dinding kiri), ekstensi micro-USB ESP32 dan SMA antena LoRa (dinding bawah), plunger tombol power dan SOS pada tutup (Gambar 11). Draft 3D awal di Autodesk Fusion 360 (Gambar 1) menjadi referensi bentuk.
- Blueprint 2D awal (55 x 65 x 18 mm) tidak lagi berlaku karena PCB final berukuran 107,95 x 95,25 mm; model casing telah disesuaikan.

7. Dokumentasi Hasil

Foto Kegiatan

Dokumentasi 3D Modelling

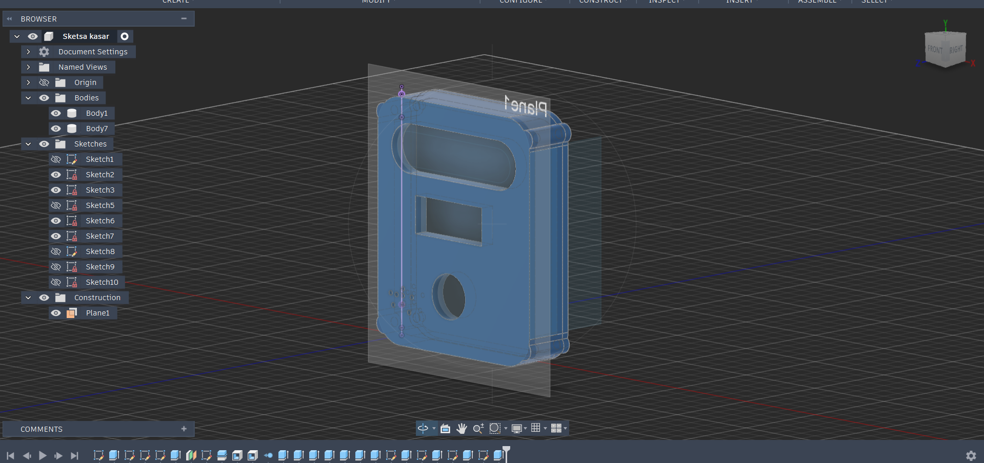
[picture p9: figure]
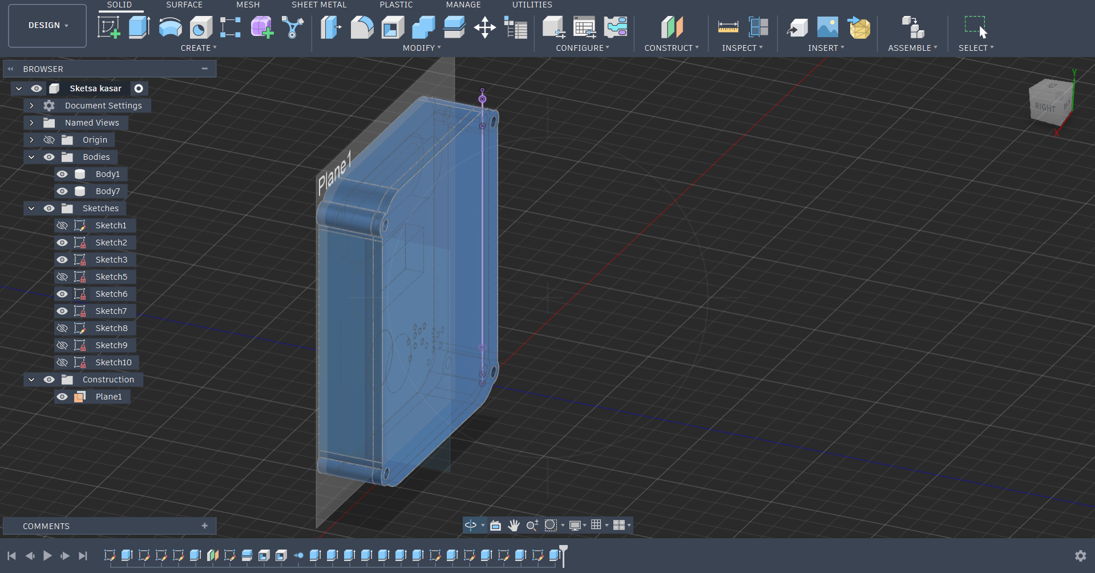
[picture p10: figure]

Gambar 1. draf 3D casing P.A.N.D.U di Fusion 360 tampak depan dan Belakang (arsip Pekan 3)

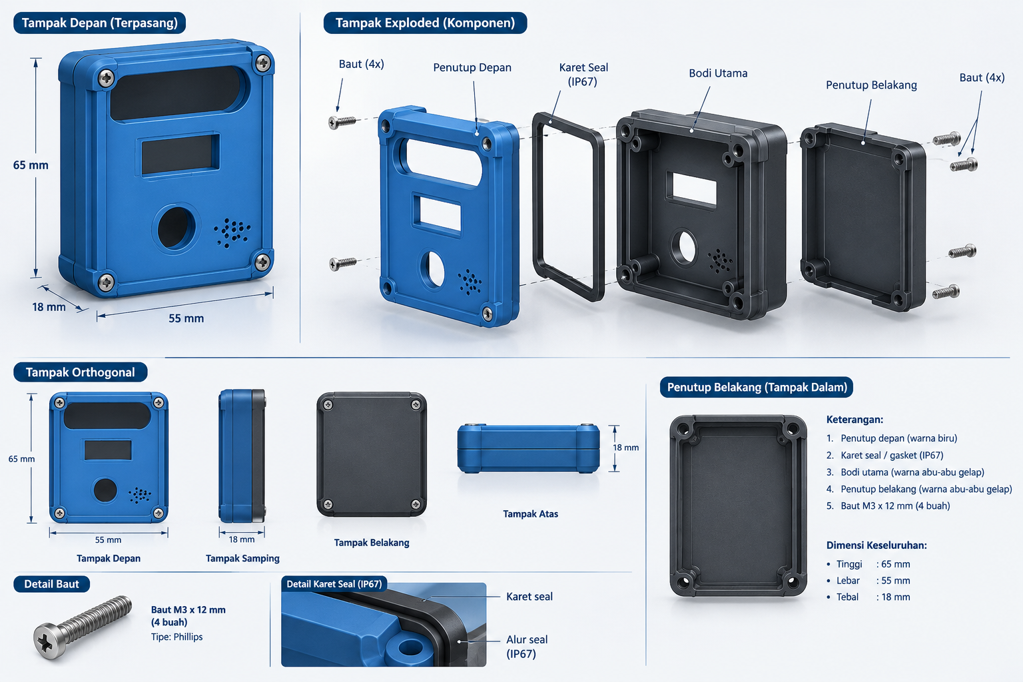
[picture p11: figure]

Gambar 2. Cetak biru (blueprint) 2D dimensi casing P.A.N.D.U (55 x 65 x 18 mm) (arsip Pekan 3)

Screenshot Sistem

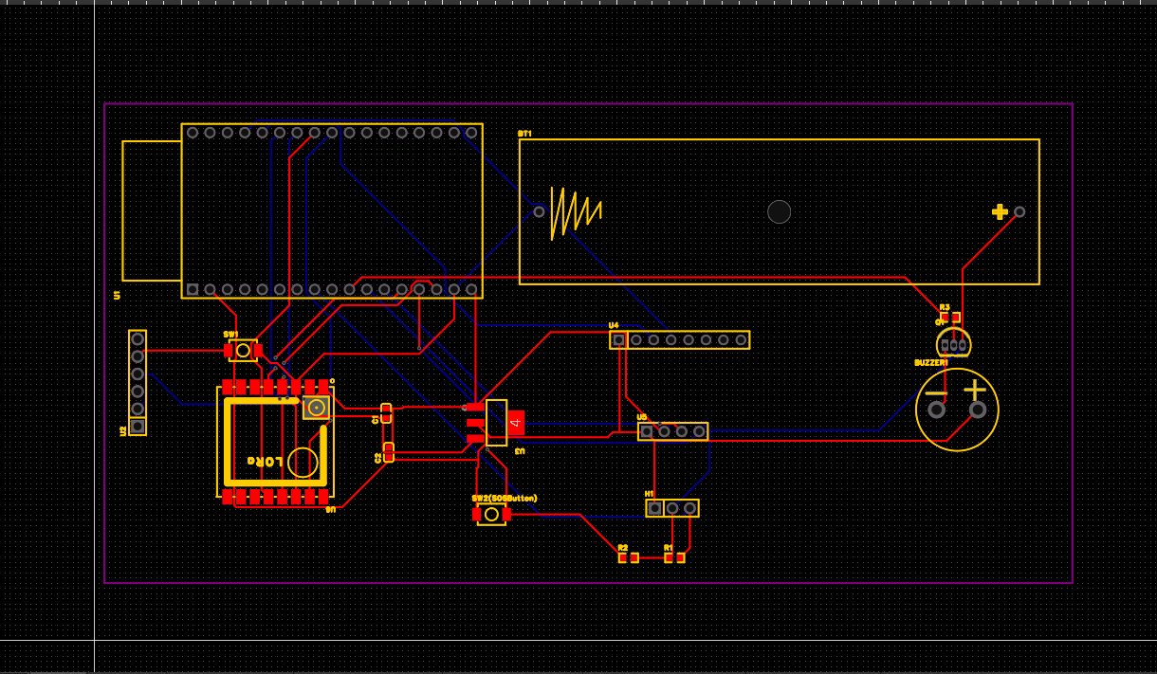
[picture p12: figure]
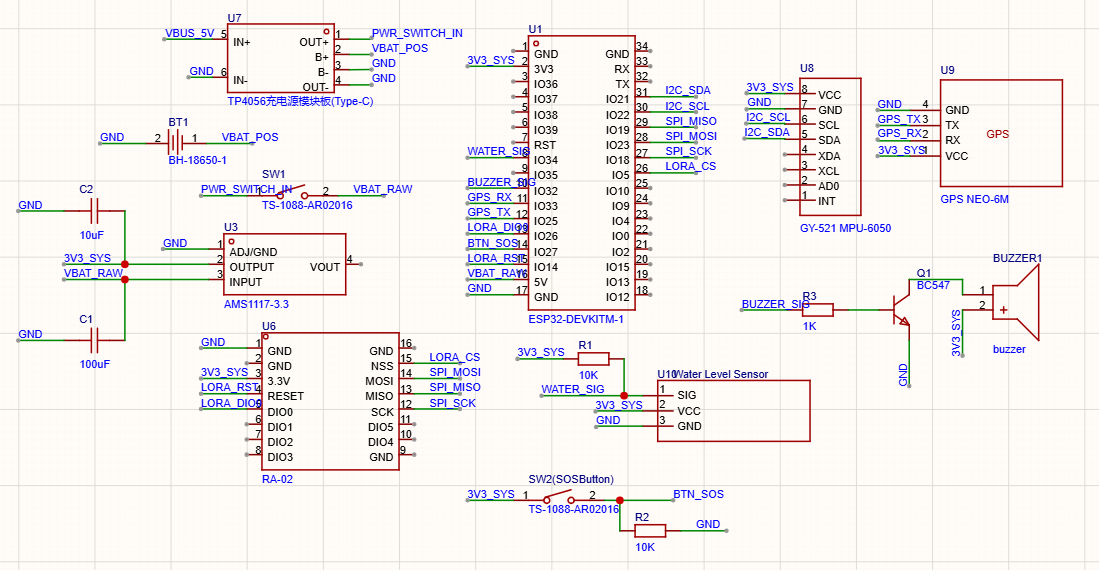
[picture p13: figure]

Gambar 3. Finalisasi Skematik Rangkaian dan Design PCB Layout untuk Rangkaian Vest Node menggunakan EasyEDA (versi sebelum perbaikan Pekan 6; lihat Gambar 8)

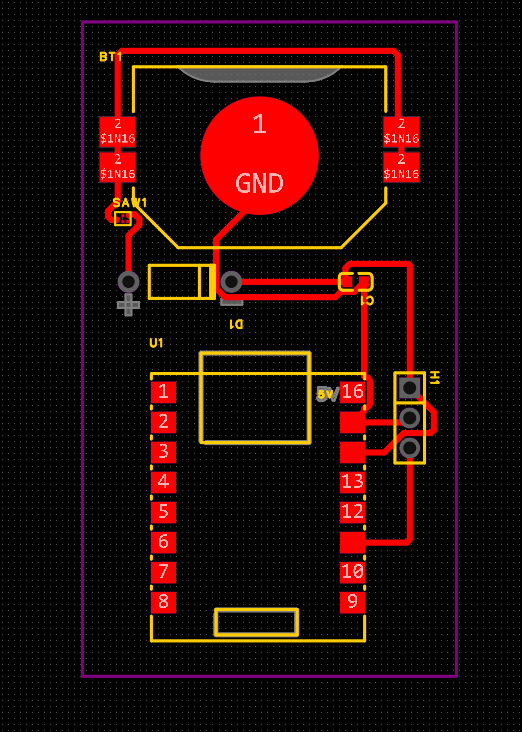
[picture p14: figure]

Gambar 4. Pembuatan Design PCB Layout untuk Rangkaian Helmet Node menggunakan EasyEDA (versi sebelum perbaikan; lihat Gambar 9)

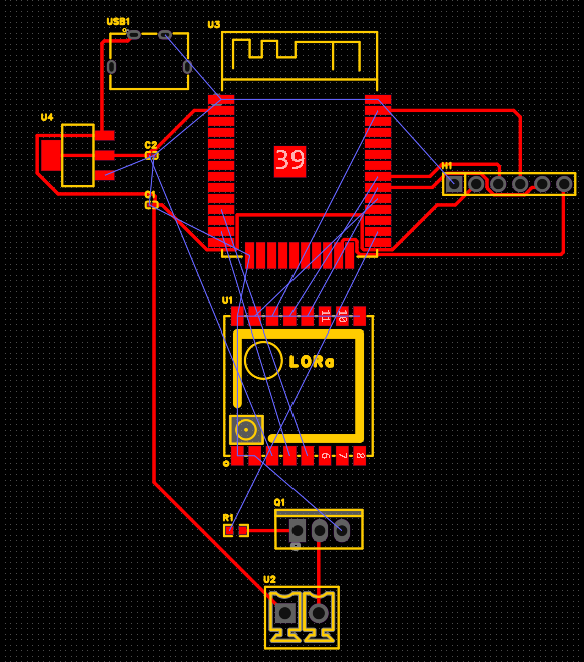
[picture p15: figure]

Gambar 5. Pembuatan Design PCB Layout untuk Rangkaian edge gateway menggunakan EasyEDA (versi sebelum perbaikan; lihat Gambar 10)

Lainnya

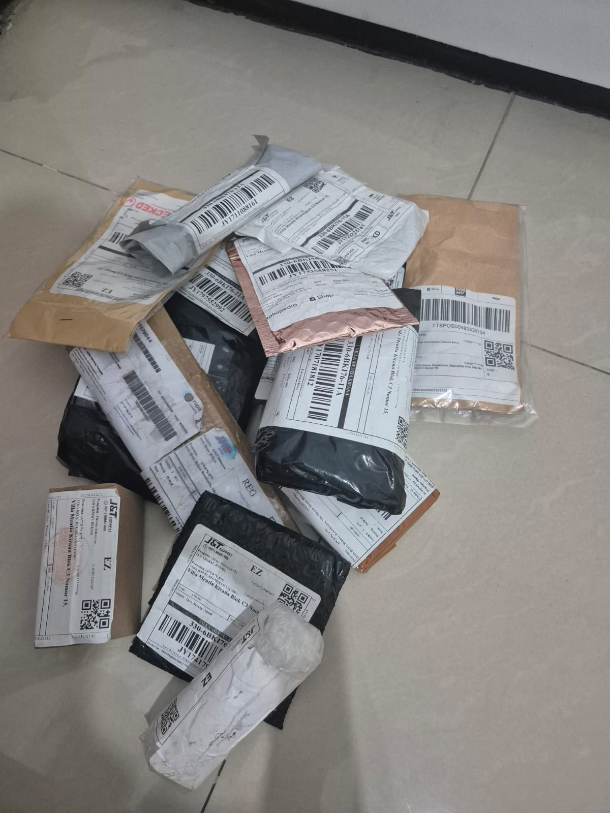
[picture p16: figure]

Gambar 6. Pemesanan komponen yang sudah datang

Screenshot Dashboard

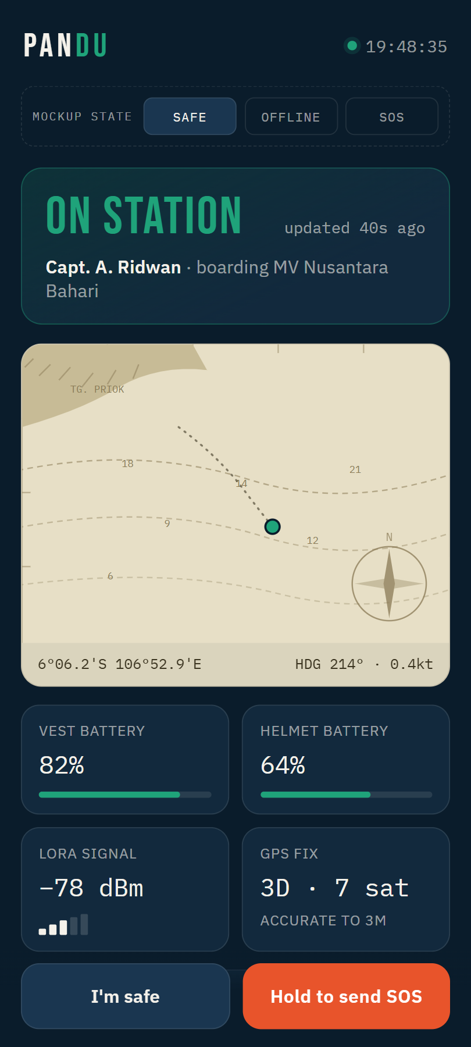
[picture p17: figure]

Gambar 7. Wireframe mockup dashboard mobile PANDU, menampilkan status keselamatan pilot (On Station / Offline / SOS), posisi live pilot pada peta chart pendekatan pelabuhan, telemetri baterai Vest Node & Helmet Node, kekuatan sinyal LoRa, status GPS fix, serta tombol darurat SOS (hold-to-confirm).


Gambar 8. Layout PCB1 Vest Node Master final (ESP32-DevKitC V4, TP4056 di sisi bawah), DRC 0 error.

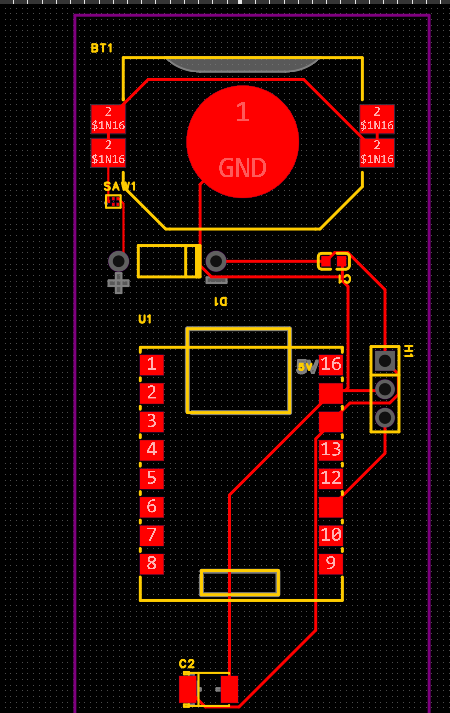
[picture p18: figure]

Gambar 9. Layout PCB2 Helmet Node final (ditambah C2 tantalum 100 uF), DRC 0 error.


Gambar 10. Layout PCB3 Edge Gateway final (ESP32-DevKitC V4), DRC 0 error.


Gambar 11. Render casing Vest Node v5 (OpenSCAD), 114 x 101 x 36,6 mm, dengan bukaan USB-C, ekstensi micro-USB, SMA, dan plunger tombol.

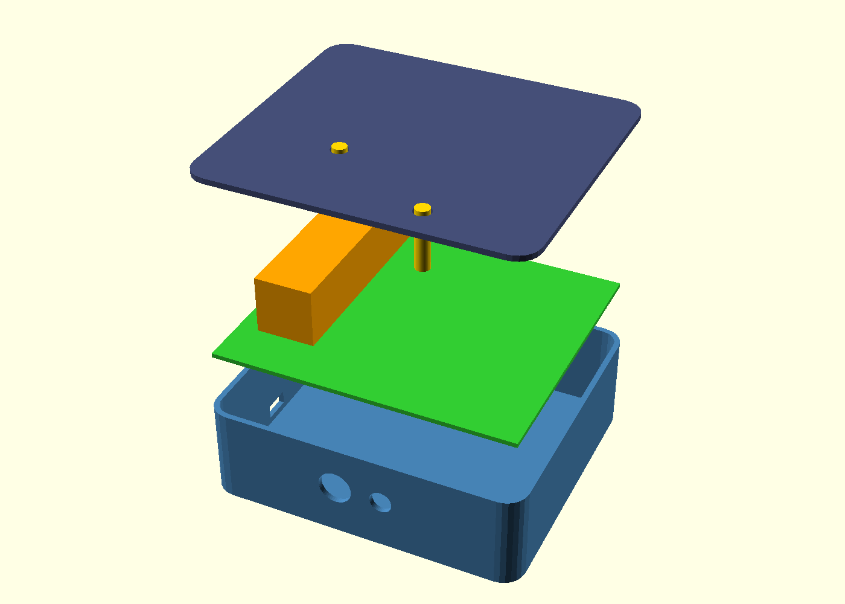
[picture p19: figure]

Gambar 12. Exploded view casing Vest Node v5 (cangkang, PCB, holder baterai, modul boost, tutup, plunger).

8. Pengujian yang Dilakukan

Parameter | Target | Hasil | Status
Kesesuaian dimensi internal casing Vest Node v5 terhadap komponen (PCB1 107,95 x 95,25 mm, ESP32-DevKitC V4, holder baterai 18650, TP4056 di sisi bawah, modul boost) | Seluruh komponen muat tanpa overlap/tabrakan | Validasi otomatis OpenSCAD: holder baterai muat (atas holder 33,6 mm vs tinggi shell 34,6 mm), modul boost muat dan tidak menimpa header (dasar boost 16,5 mm vs header 8,5 mm). Dimensi luar 114 x 101 x 36,6 mm. | ☒ Lulus ☐ Tidak
Design Rule Check PCB1, PCB2, PCB3 (EasyEDA Pro) | 0 error DRC dan 0 ratline (semua net ter-route) | PCB1, PCB2, PCB3: 0 error dan 0 ratline (3 Oktober 2026). | ☒ Lulus ☐ Tidak
DRC skematik (pin mengambang) PCB1 dan PCB3 | Seluruh pin yang dipakai tersambung | Ditemukan dan diperbaiki GND RA-02 dan GPS_EN yang sempat tidak tersambung; peringatan tersisa hanya pin modul yang memang tidak dipakai. | ☒ Lulus ☐ Tidak

Analisis Singkat

Pengujian pekan ini berupa verifikasi desain secara simulasi (belum ada pengujian fisik karena PCB belum difabrikasi). Dimensi casing divalidasi dengan model parametrik OpenSCAD dan pengecekan otomatis atas kecocokan holder baterai dan modul boost di dalam casing (Gambar 11, 12). DRC pada ketiga PCB dan DRC skematik berhasil menemukan kesalahan koneksi (pin antena LoRa ke GND, pin GND dan GPS_EN yang tidak tersambung) sebelum Gerber dipesan. Nilai yang masih berupa asumsi dan perlu diverifikasi pada barang fisik: tinggi modul TP4056 beserta header (8,5 mm) dan tinggi holder baterai.

9. Kendala dan Solusi

Kendala | Dampak | Solusi yang Dilakukan
Belum tersedia hardware stack dan API endpoint yang fix dari modul ESP32 (Vest Node, Helmet Node, Edge Gateway) | Tim dashboard belum bisa mengunci daftar fitur final maupun tech stack aplikasi mobile (Android & iOS) karena skema data dari perangkat belum pasti | Menunggu Gibran & Rifat menyelesaikan desain hardware dan definisi endpoint; sementara itu tim dashboard fokus pada requirement gathering dan pengembangan wireframe berdasarkan asumsi data sensor yang sudah diketahui
Desain awal tidak cocok dengan komponen yang dibeli (footprint ESP32 17 pin per sisi vs DevKitC V4 38 pin; modul LoRa yang dibeli bukan Ra-02) | Footprint PCB salah sehingga board tidak dapat dipasang dan PCB tidak dapat dipesan | Simbol dan footprint diganti ke DevKitC V4 pada PCB1 dan PCB3; kecocokan modul LoRa menunggu foto/datasheet modul; ukur board fisik sebelum order
Port USB TP4056 dan ESP32 menghadap ke dalam papan sehingga tidak terjangkau dari dinding casing | Sulit mengisi baterai dan memprogram setelah dirakit | TP4056 diputar 180 derajat (USB-C ke dinding), ESP32 memakai kabel ekstensi panel-mount micro-USB
Kesalahan desain ditemukan saat audit (AMS1117, pin antena LoRa, rangkaian EN/IO0 ESP32 Gateway, dll.) | Berisiko papan tidak berfungsi jika langsung dipesan | Diperbaiki dan diverifikasi DRC; order PCB ditunda sampai verifikasi fisik modul
BOM belum sinkron dengan desain (VL53L0X dan BME680 masih tercantum; XKC-Y25, boost 5 V, komponen SMD belum ada) | Anggaran dan pembelian tidak sesuai kebutuhan | Daftar selisih BOM disusun; Rafif memperbarui BOM dan membeli modul yang kurang

10. Deviasi Terhadap Jadwal

Aktivitas | Jadwal Awal | Realisasi | Keterangan
Observasi Lapangan (SPJM) | Minggu 1 | Pra-Perkuliahan (Juli 2026) | Survei ke Pelabuhan SPJM dilakukan sebelum jadwal perkuliahan dimulai sebagai upaya mengurangi risiko terkait desain operasional.
F1: Procurement & Setup | Minggu 1-2 | Minggu 1-2 | Pembelian komponen (BoM) di tunda sementara di awal minggu untuk mengkalibrasi kembali spesifikasi perangkat keras (standar IP67) setelah observasi di SPJM.
Pemodelan 3D Casing (Mekanik) | Minggu 3 | Diundur ke Minggu 4 | Pemodelan 3D ditunda sampai minggu keempat agar fokus pada pembuatan blueprint 2D sesuai instruksi dosen.
Pemodelan 3D Casing (Mekanik) | Minggu 4 | Sedang Berjalan | Melanjutkan desain 3D dengan fokus pada pembuatan struktur internal dan pemisahan bodi casing
Finalisasi 3D casing | Minggu 5 | Minggu 6 | Casing Vest Node dibuat ulang mengikuti PCB final (114 x 101 x 36,6 mm, OpenSCAD).
Order PCB | Minggu 5 (target 26 Sep, lalu 3 Okt) | Diundur ke Minggu 7 | Audit skematik menemukan kesalahan desain dan footprint ESP32/modul LoRa harus disesuaikan dengan komponen yang dibeli; Gerber sudah siap, order menunggu verifikasi fisik modul.

Analisis Deviasi

Terdapat penyimpangan positif pada observasi lapangan (Juli 2026) yang memberi keleluasaan menyesuaikan perangkat dengan standar IP67. Pemodelan 3D casing bergeser ke Minggu 4 untuk memprioritaskan blueprint 2D sesuai arahan dosen. Pada Minggu 6, pemesanan PCB yang dijadwalkan sebelumnya belum terlaksana: audit skematik menemukan beberapa kesalahan desain yang harus diperbaiki, serta footprint ESP32 dan modul LoRa harus disesuaikan dengan komponen yang telah dibeli. Perbaikan dan ekspor Gerber telah selesai, sedangkan order PCB ditunda sampai verifikasi fisik modul selesai (target Minggu 7). Penundaan ini mencegah biaya fabrikasi ulang, tetapi perlu dijaga agar tidak mengganggu jadwal integrasi sistem.

11. Rencana Kerja Pekan Berikutnya

No | Aktivitas | PIC | Target Selesai
1 | Verifikasi fisik modul (pin LoRa, TP4056, boost, ukuran ESP32) lalu Order PCB | Gibran, Rifat, Calvin | 10 Oktober 2026
2 | Membeli modul yang kurang (XKC-Y25, boost 5 V, komponen SMD) dan memperbarui BOM | Rafif | 10 Oktober 2026
3 | Sinkronisasi model casing Fusion 360 dan casing Helmet Node/Gateway ke PCB baru | Yoga, Calvin | 17 Oktober 2026
4 | Finalisasi fitur dashboard dan tech stack setelah endpoint ESP32 ditetapkan | Rafif, Calvin | 17 Oktober 2026
5 | Perakitan uji (breadboard/perfboard) dan mulai firmware (deep sleep, kontrol GPS/sensor air, deteksi jatuh) | Calvin | 24 Oktober 2026

12. Persentase Progress Proyek

Komponen | Bobot (%) | Progress (%)
Perancangan | 25 | 90
Implementasi Hardware | 20 | 25
Implementasi Software | 20 | 10
Integrasi Sistem | 15 | 0
Pengujian | 15 | 5
Dokumentasi | 5 | 25

Progress Total Proyek

Progress Total = 31,5%

13. Kesimpulan

PCB Design ketiga unit (Vest Node Master, Helmet Node, Edge Gateway) telah selesai dan lolos DRC dengan Gerber yang sudah diekspor. Audit skematik pada pekan ini menemukan dan memperbaiki beberapa kesalahan desain yang berpotensi membuat papan tidak berfungsi, dan desain disesuaikan dengan komponen yang telah dibeli (ESP32-DevKitC V4). Sensor anti-crush dan buzzer pada Vest Node dihapus untuk menekan false positive, dan sensor air diganti ke tipe non-kontak untuk target IP67. Casing Vest Node dibuat ulang mengikuti PCB final. Pemesanan PCB ditunda sampai verifikasi fisik modul (pin LoRa, TP4056, boost, ukuran ESP32) selesai dan modul yang kurang dibeli. Di sisi software, wireframe dashboard mobile PANDU telah tersedia; finalisasi fitur dan tech stack aplikasi (Android dan iOS) menunggu kepastian endpoint dari ESP32.

Persetujuan

Jabatan | Nama | Tanda Tangan

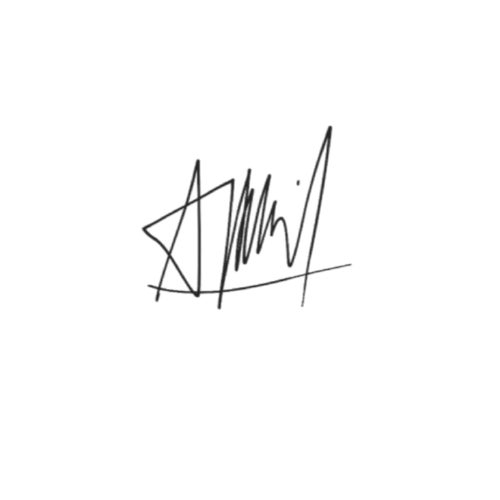
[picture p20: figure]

Ketua Kelompok | Adhi Rajasa Rafif
Pembimbing | Tomy Abuzairi, S.T., M.Sc., Ph.D.

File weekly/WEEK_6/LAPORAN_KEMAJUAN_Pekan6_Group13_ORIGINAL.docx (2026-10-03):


LAPORAN KEMAJUAN PEKANAN

DESAIN PROYEK TEKNIK ELEKTRO, KOMPUTER, BIOMEDIK 2

Judul Proyek : P.A.N.D.U: Perangkat Alarm Nirkabel Deteksi Urgensi

Kelompok : 13

Pekan Ke- : 6

Periode : 2

Dosen Pembimbing : Tomy Abuzairi, S.T., M.Sc., Ph.D.

Ketua Kelompok : Adhi Rajasa Rafif (2306266943)

Anggota Kelompok :

- Adhi Rajasa Rafif (2306266943
- Calvin Wirathama Katoroy (2306242395)
- M Gibran Arya Avicena (2306156643)
- Muhammad Rifat Faqih (2306250762)
- Tri Yoga Arsyad (2306161920)

1. Ringkasan Tentang Project

Wearable Safety Multi-Modul untuk pandu kapal dengan Deteksi Fall + Man Overboard (MOB) + APD compliance, dengan Emergency Beacon LoRa + GPS untuk rescue dispatch dalam detik. Tujuan khusus alat PANDU sebagai berikut:

- Menciptakan perangkat wearable keselamatan (Vest dan Helmet Node) berbasis multi-sensor sensor dan ESP32, yang terintegrasi langsung dengan sistem komunikasi LoRa dan Edge Gateway, untuk memastikan bahwa transmisi sinyal darurat (SOS) tetap lancar di wilayah perairan dengan sinyal yang lemah (blank spot).
- Membangun sistem backend (protokol MQTTS) dan dashboard pemantauan berbasis web yang memungkinkan pelacakan lokasi pekerja (live tracking) dan pencatatan log insiden secara real-time.
- Mengimplementasikan lapisan kecerdasan (Intelligence Layer) dengan skenario bahaya berjenjang yang terhubung dengan SOP-AI (RAG dan LLM) untuk memberikan panduan evakuasi yang akurat dan menghindari kelelahan alarm (alarm fatigue) pada supervisor.

Sistem PANDU mengintegrasikan beberapa komponen perangkat keras utama untuk mendeteksi kecelakaan kerja secara akurat dan yang telah disesuaikan dengan spesifikasi yang dibutuhkan:

- Sensor giroskop MPU (MPU-6059) berfungsi sebagai detektor primer untuk mengukur perubahan orientasi tubuh pekerja dan mengenali insiden terjatuh.
- Water contact sensor bekerja sebagai detektor sekunder untuk memvalidasi keberadaan air saat pekerja jatuh ke laut.
- LoRaWAN untuk mengirimkan sinyal alarm secara mandiri, Jaringan LoRaWAN ini mentransmisikan paket data darurat dari perangkat pekerja menuju gateway kapal dengan jangkauan maksimal tiga mil.

2. Ringkasan Kemajuan Pekanan

Pada pekan ini, kegiatan proyek PANDU berfokus pada finalisasi perancangan sistem dan persiapan menuju tahap implementasi. Rangkaian PCB untuk tiga unit utama, yaitu Vest Node Master, Helmet Node, dan Edge Gateway(75%) telah dilakukan perancangan menggunakan EasyEDA Pro. Desain sistem juga telah disesuaikan kembali berdasarkan hasil observasi lapangan di SPJM. Selain itu, perancangan awal mockup dashboard telah dimulai dan beberapa komponen sudah mulai dipesan. Validasi dimensi casing terhadap komponen elektronik juga dilakukan menggunakan simulasi parametrik (OpenSCAD), yang menemukan perlunya revisi ukuran casing sebelum masuk tahap cetak 3D.

3. Target Pekan Ini

No | Target | Status
1 | Order PCB | ☐ Tercapai ☐ Belum
2 | Simulasi Assembly 3D | ☐ Tercapai v Belum
3 | Membuat design dashboard | ☐ Tercapai ☐ Belum

4. Realisasi Kegiatan

No | Kegiatan | Penanggung Jawab | Hasil
1 | Order PCB | | Rancangan skematik harus direvisi lagi untuk mengurangi banyaknya false positive, kami menghilangkan penggunaan sensor jarak untuk anti-crushing dan kami mencoba mencari alternatif sensor kedalaman air yang kemungkinan lebih compatible dengan design yang direncanakan, karena alasan sebelumnya penggunaan sensor kedalaman air yang sebelumnya akan membuat device utama memiliki risiko kemasukan air yang cukup signifikan yang dampaknya bisa tidak sesuai dengan rencana device bisa menembus IP67
2 | 3D model | | Draft 3D casing P.A.N.D.U selesai dibuat menggunakan Autodesk Fusion 360 (Gambar 1). Blueprint 2D presisi dengan dimensi 55 x 65 x 18 mm telah disusun sebagai acuan tata letak komponen pada PCB (Gambar 2)

3

Mockup Design Dashboard

Diskusi kebutuhan fitur dashboard PANDU telah dilakukan, menghasilkan penentuan dua tampilan pengguna (marine pilot view dan supervisor view) beserta data yang perlu ditampilkan pada masing-masing tampilan. Wireframe awal dashboard berbasis HTML telah selesai dibuat sebagai acuan visual, mencakup status keselamatan pilot, live tracking posisi, serta telemetri perangkat (baterai, sinyal LoRa, GPS fix). Finalisasi daftar fitur dan penentuan tech stack aplikasi mobile (Android & iOS) akan dilakukan pekan berikutnya, menunggu hardware stack dan definisi endpoint dari ESP32 (Vest Node, Helmet Node, Edge Gateway).

5. Kemajuan Tiap Anggota

Nama | Tugas Pekan Ini | Persentase Penyelesaian
Adhi Rajasa Rafif | Melakukan diskusi kebutuhan fitur dashboard PANDU bersama Calvin, termasuk penentuan dua tampilan pengguna (marine pilot view & supervisor view) dan data yang wajib ditampilkan di tiap tampilan Menyusun wireframe awal dashboard PANDU berbasis HTML sebagai acuan desain aplikasi mobile | 100%
Calvin Wirathama Katoroy | Melakukan diskusi kebutuhan fitur dashboard PANDU bersama Rafif, termasuk penentuan dua tampilan pengguna (marine pilot view & supervisor view) dan data yang wajib ditampilkan di tiap tampilan. Membangun wireframe interaktif dashboard PANDU (HTML/CSS/JS) sebagai acuan visual sebelum masuk tahap penentuan fitur final dan tech stack aplikasi mobile Android & iOS pekan berikutnya. | 100%
M Gibran Arya Avicena | Membantu revisi rancangan skematik Vest Node untuk menekan tingkat false positive pada perangkat utama. Turut menyelesaikan pembaruan desain rangkaian skematik. Mempersiapkan pesanan cetak PCB dalam beberapa hari ke depan. | 90%
Muhammad Rifat Faqih | Rancangan skematik harus direvisi lagi untuk mengurangi banyaknya false positive terutama pada device utama yaitu vest node. untuk rangkaian schematic terbarunya sudah selesai dibuat, direncanakan beberapa hari kedepan rangkaian PCB akan selesai dibuat juga dan akan segara memesan PCB. Pembuatan Schematic dan design PCB helmet node dan edge gateway | 90%
Tri Yoga Arsyad | Membuat draf sketsa kasar 3D casing P.A.N.D.U dengan menggunakan Fusion 360, serta menyusun cetak biru (blueprint) 2D yang presisi dengan ukuran 55 x 65 x 18 mm sebagai acuan untuk tata letak komponen pada PCB yang dibuat oleh tim hardware. | 100%

6. Hasil Implementasi

Hardware

- Komponen yang telah direalisasikan:
  - PCB Design untuk seluruh ekosistem PANDU (Unit 1: Vest Node Master, Unit 2: Helmet Node, dan Unit 3: Edge Gateway on progress).
- Status integrasi:
  - Belum ada integrasi fisik antar unit. Ketiga PCB (Vest Node Master, Helmet Node, Edge Gateway) masih dalam tahap desain layout di EasyEDA Pro, belum masuk tahap fabrikasi/assembly.

Software

- Fitur yang telah selesai:
  - Wireframe awal dashboard mobile PANDU (HTML) untuk tampilan marine pilot dan supervisor. Wireframe tersebut bisa diakses di repository github berikut: https://github.com/calvinkatoroy/pandu-dashboard
- Fitur yang masih dikembangkan:
  - Finalisasi daftar fitur dashboard dan pemilihan tech stack aplikasi mobile (Android & iOS). Firmware embedded dan backend (MQTTS) belum dimulai, menunggu hardware stack dan endpoint API dari ESP32 selesai didefinisikan oleh tim hardware.

Mekanik/Biomedik

- Draft 3D casing P.A.N.D.U selesai dibuat di Autodesk Fusion 360 (Gambar 1).
- Blueprint 2D presisi dengan dimensi 55 x 65 x 23 mm telah disusun sebagai acuan tata letak komponen PCB (Gambar 2).

7. Dokumentasi Hasil

Foto Kegiatan

Dokumentasi 3D Modelling


Gambar 1. draf 3D casing P.A.N.D.U di Fusion 360 tampak depan dan Belakang


Gambar 2. Cetak biru (blueprint) 2D dimensi casing P.A.N.D.U (55 x 65 x 18 mm)

Screenshot Sistem


Gambar 3. Finalisasi Skematik Rangkaian dan Design PCB Layout untuk Rangkaian Vest Node menggunakan EasyEDA


Gambar 4. Pembuatan Design PCB Layout untuk Rangkaian Helmet Node menggunakan EasyEDA


Gambar 5. Pembuatan Design PCB Layout untuk Rangkaian edge gateway menggunakan EasyEDA

Lainnya


Gambar 6. Pemesanan komponen yang sudah datang

Screenshot Dashboard


Gambar 7. Wireframe mockup dashboard mobile PANDU, menampilkan status keselamatan pilot (On Station / Offline / SOS), posisi live pilot pada peta chart pendekatan pelabuhan, telemetri baterai Vest Node & Helmet Node, kekuatan sinyal LoRa, status GPS fix, serta tombol darurat SOS (hold-to-confirm).

8. Pengujian yang Dilakukan

Parameter | Target | Hasil | Status
Kesesuaian dimensi internal casing Vest Node vs komponen elektronik (baterai 18650, ESP32-WROOM-32, modul LoRa SX1276, GPS NEO-6M) | Seluruh komponen muat di dalam casing tanpa overlap/tabrakan | Ketebalan awal 18mm tidak cukup (baterai overlap 2mm); setelah direvisi ke 23mm dan divalidasi ulang lewat simulasi parametrik (OpenSCAD), seluruh komponen tervalidasi muat | v Lulus ☐ Tidak
| | | ☐ Lulus ☐ Tidak
| | | ☐ Lulus ☐ Tidak

Analisis Singkat

Verifikasi dimensi dilakukan secara simulasi menggunakan model parametrik (OpenSCAD) sebelum casing masuk tahap cetak 3D. Ditemukan bahwa ketebalan awal 18mm tidak mengakomodasi baterai 18650 (diameter 18mm) setelah diperhitungkan dengan tebal dinding cetak. Revisi ketebalan menjadi 23mm, serta revisi tinggi casing dari 65mm menjadi 70mm untuk mengakomodasi panjang baterai (65mm) beserta dinding di kedua ujungnya. Hasil render 3D (Gambar 7, Gambar 8) dan pengecekan otomatis pada model mengkonfirmasi seluruh komponen tervalidasi muat setelah revisi.

9. Kendala dan Solusi

Kendala | Dampak | Solusi yang Dilakukan
Belum tersedia hardware stack dan API endpoint yang fix dari modul ESP32 (Vest Node, Helmet Node, Edge Gateway) | Tim dashboard belum bisa mengunci daftar fitur final maupun tech stack aplikasi mobile (Android & iOS) karena skema data dari perangkat belum pasti | Menunggu Gibran & Rifat menyelesaikan desain hardware dan definisi endpoint; sementara itu tim dashboard fokus pada requirement gathering dan pengembangan wireframe berdasarkan asumsi data sensor yang sudah diketahui

10. Deviasi Terhadap Jadwal

Aktivitas | Jadwal Awal | Realisasi | Keterangan
Observasi Lapangan (SPJM) | Minggu 1 | Pra-Perkuliahan (Juli 2026) | Survei ke Pelabuhan SPJM dilakukan sebelum jadwal perkuliahan dimulai sebagai upaya mengurangi risiko terkait desain operasional.
F1: Procurement & Setup | Minggu 1-2 | Minggu 1-2 | Pembelian komponen (BoM) di tunda sementara di awal minggu untuk mengkalibrasi kembali spesifikasi perangkat keras (standar IP67) setelah observasi di SPJM.
Pemodelan 3D Casing (Mekanik) | Minggu 3 | Diundur ke Minggu 4 | Pemodelan 3D ditunda sampai minggu keempat agar fokus pada pembuatan blueprint 2D sesuai instruksi dosen.
Pemodelan 3D Casing (Mekanik) | Minggu 4 | Sedang Berjalan | Melanjutkan desain 3D dengan fokus pada pembuatan struktur internal dan pemisahan bodi casing
Finalisasi 3D casing secara penuh | Minggu 5 | Minggu 5 | Desain 3D casing final telah selesai 80% (meliputi ruang internal, penutup belakang, dan dudukan baut), serta siap untuk tahap simulasi perakitan."

Analisis Deviasi

Terdapat penyimpangan positif dalam observasi lapangan pada bulan Juli 2026, yang memberikan keleluasaan waktu untuk menunda pembelian komponen demi menyesuaikan perangkat dengan standar IP67 serta mengoptimalkan anggaran yang ada. Pemodelan tiga dimensi yang tadinya direncanakan pada Minggu 3 dipindahkan ke Minggu 4 agar dapat lebih memfokuskan pada pembuatan blueprint dua dimensi sesuai arahan dari dosen. Pada Minggu 5, proses penyelesaian desain tiga dimensi casing mencapai 80%; meskipun struktur utama telah siap untuk tahap simulasi perakitan bersama tim perangkat keras, sisa 20% penyelesaian final (finishing detail) harus dilanjutkan ke minggu berikutnya. Secara keseluruhan, perubahan jadwal dan pekerjaan yang tersisa ini masih terpantau aman dan tidak mengganggu batas waktu selesainya proyek.

11. Rencana Kerja Pekan Berikutnya

No | Aktivitas | PIC | Target Selesai
1 | Order PCB | Gibran, Rifat | 3 Oktober 2026
3 | Membantu perancangan layout PCB & Simulasi Assembly 3D | Yoga | 3 Oktober 2026
4 | Membuat design dashboard | Rafif, Calvin | 3 Oktober 2026
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

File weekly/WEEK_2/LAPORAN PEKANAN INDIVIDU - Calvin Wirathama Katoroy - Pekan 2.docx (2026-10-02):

# LAPORAN PEKANAN INDIVIDU

## Capstone Project Desain Proyek 2

### A. Identitas Mahasiswa

Item | Keterangan
Nama | Calvin Wirathama Katoroy
NPM | 2306242395
Program Studi | Teknik Elektro
Kelompok | 13
Judul Proyek | P.A.N.D.U (Perangkat Alarm Nirkabel Deteksi Urgensi)
Pekan ke- | 2
Periode Tanggal | 31 Agustus - 5 September 2026
Dosen Pembimbing | Tomy Abuzairi, S.T., M.Sc., Ph.D.
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

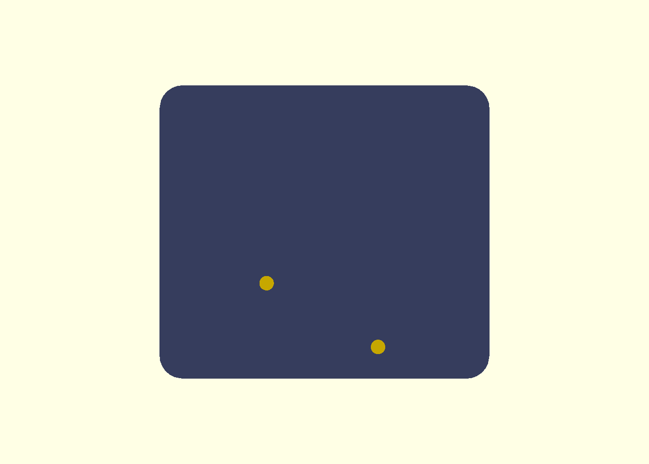
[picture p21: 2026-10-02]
weekly/WEEK_6/PANDU_VestNode_Casing_top.png

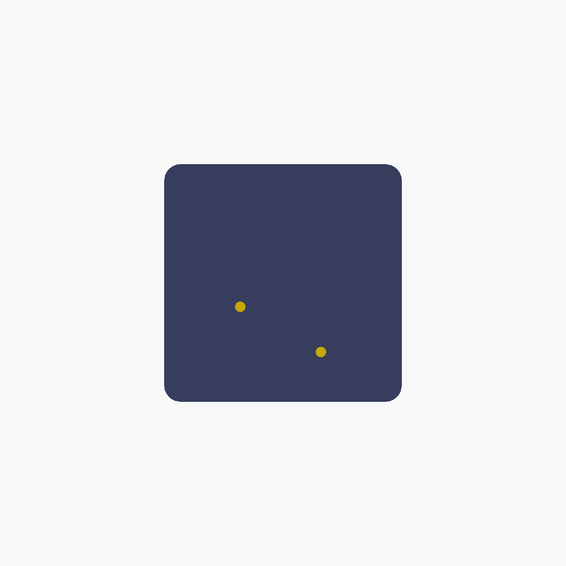
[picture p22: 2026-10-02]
weekly/WEEK_4/PANDU_VestNode_Casing_top.png

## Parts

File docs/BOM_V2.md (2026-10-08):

# BOM PANDU (desain v2, per 8 Okt 2026)

Sumber: netlist `hardware/netlist/PCB1.tel`, `PCB2.tel`, `PCB3.tel`, firmware, dan hasil tes sesi ini. Tanpa harga (harga final ikut invoice di sheet "Bills of Materials").
Kolom **Status** diambil dari checklist sheet BOM (6 Okt) dan percakapan; belum tentu terkini, cek ulang dengan Rafif/Gibran.
Tanda **PERLU DIPERBAIKI** = item di desain/EasyEDA yang salah atau belum cocok dengan komponen fisik (lihat HANDOVER.md).

## 1. Vest Node Master (PCB1)
| Ref | Komponen | Jml | Status / catatan |
|---|---|---|---|
| U3 | ESP32-DevKitC V4 (WROOM-32) | 1 | Ada. Cek jarak baris pin (25,4 vs 22,86 mm) |
| U8 | GY-521 (MPU6050) | 1 | Ada, tes jatuh jalan. Urutan footprint belum dicek |
| U9 | GPS NEO-6M + antena keramik | 1 | Ada, dapat fix (sinyal lemah). Antena aktif eksternal disarankan |
| U6 | Modul LoRa SX1276 (XL1276-P01, 915 MHz) + antena pegas | 1 | Ada 1. **PERLU DIPERBAIKI:** pinout RFM95, footprint PCB = RA-02. Belum disolder. Cek pita 868M vs 915M |
| U10 | Sensor air analog (S, +, -) | 1 | Ada, ambang 1000 mV. **PERLU DIPERBAIKI:** VCC ke 3V3, hapus R1. (XKC-Y25 tidak dipakai/belum dibeli) |
| BT1 | Holder 18650 | 1 | Ada |
| - | Baterai 18650 1200 mAh | 1 | Ada |
| U7 | Modul TP4056 USB-C berproteksi (HW-373) | 1 | Ada. **PERLU DIPERBAIKI:** B- dan OUT- sama-sama GND (proteksi terlewati) |
| U2 | Modul boost MT3608 (set 5,0 V), header 1x4 | 1 | Belum ada |
| D1 | Dioda SS14 (SMA) | 1 | Belum ada |
| Q1, Q2 | MOSFET P-channel AO3401A (SOT-23) | 2 | Belum ada. Q2 mungkin tidak perlu lagi jika XKC dibuang |
| Q5 | MOSFET N-channel 2N7002 (SOT-23) | 1 | Belum ada. Sama, mungkin tidak perlu |
| R1, R2 | Resistor 10 k (0603) | 2 | R1 dihapus untuk sensor analog. R2 = pull-down SOS |
| R3, R4, R5, R6, R7 | Resistor 100 k (0603) | 5 | R6/R7 = pembagi baterai |
| C1 | Kapasitor 100 uF (case B 3528) | 1 | |
| C2 | Kapasitor 100 nF (0603) | 1 | |
| SW1, SW2 | Tact switch SMD (TS-1088-AR02016) | 2 | Power dan SOS |
| H1 | Header 2 pin 2,54 mm | 1 | Untuk pigtail antena LoRa |
| - | Antena LoRa 915 MHz + pigtail (SMA) | 1 | Untuk Vest belum ada di BOM; antena pegas bawaan modul bisa dipakai tes |

## 2. Helmet Node (PCB2)
| Ref | Komponen | Jml | Status / catatan |
|---|---|---|---|
| U1 | ESP32-C3 SuperMini | 1 | Ada, BLE beacon jalan. Pastikan pin 5V lewat regulator |
| H1 | Header 3 pin + modul TTP223 | 0 | **TIDAK DIPAKAI**: deteksi helm lewat tombol on/off + BLE + RSSI (tanpa sensor sentuh). Hapus H1, net `TOUCH_SIG` (GPIO2) dari PCB2 |
| H2 | Header 2 pin (LiPo) | 1 | |
| - | Baterai LiPo 3,7 V ~400-500 mAh berproteksi | 1 | Belum ada |
| U7 | Modul TP4056 USB-C berproteksi | 1 | Perlu yang kedua (sheet hanya 1) |
| SAW1 | Saklar geser (jalur baterai ke pin 5V) | 1 | **PERLU DIPERBAIKI:** di EasyEDA berisi filter SMD SAPPLAND SPST40SU03C, bukan saklar. Ganti saklar geser sungguhan |
| SW1 | Tact switch SMD (TS-1088-AR02016) | 1 | On/off |
| R1 | Resistor 100 k (0603) | 1 | Pull-up tombol |
| C1 | Kapasitor 10 uF (0603) | 1 | |
| C2 | Kapasitor 100 uF (case B 3528) | 1 | |
| - | CR2032 + holder | 0 | Dihapus di v2.1, tidak dipakai lagi |

## 3. Edge Gateway (PCB3)
| Ref | Komponen | Jml | Status / catatan |
|---|---|---|---|
| U5 | ESP32-DevKitC V4 (WROOM-32) | 1 | Ada |
| U1 | Modul LoRa SX1276 915 MHz | 1 | **Belum dibeli (baru 1 modul)**. Footprint RA-02 sama masalahnya |
| H1 | Header 1x6 + modul microSD (SPI) | 1 | Ada. Urutan pin dan level logika perlu dicek |
| - | Kartu microSD 16/32 GB (FAT32) | 1 | Ada |
| Q1 | MOSFET IRLZ44N (TO-220) | 1 | Belum ada |
| R1 | Resistor 220 ohm (0603) | 1 | |
| R2 | Resistor 10 k (0603) | 1 | Pull-up CS SD |
| R3 | Resistor 100 k (0603) | 1 | Pull-down gate |
| U2 | Terminal block 2 pin 3,81 mm | 1 | Untuk sirine |
| - | Sirine/strobo 5 V (>= 85 dB) | 1 | Belum ada. Perlu dioda flyback jika sirine berkoil/motor |
| H2 | Header 2 pin | 1 | Pigtail antena |
| - | Antena LoRa 915 MHz + pigtail SMA | 1 | Ada |
| - | Adaptor 5 V 2 A + kabel | 1 | Ada |
| - | Box enclosure gateway | 1 | Belum ada |

## 4. Fabrikasi dan bahan pendukung
| Item | Status |
|---|---|
| PCB 2 layer: PCB1, PCB2, PCB3 | Belum dipesan. Jangan pesan sebelum revisi footprint dan proteksi |
| Casing 3D print PETG (Vest, Helmet, Gateway) | Vest v5 ada (belum update parts baru). Helmet dan Gateway belum |
| Konektor IP67, cable gland, seal | Belum |
| Kabel, header, JST, spacer, screw, heat shrink | Belum |
| Solder, flux, conformal coating, silikon | Belum |
| Perfboard/breadboard dan jumper | Ada (breadboard) |
| Resistor/kapasitor assortment untuk prototipe breadboard | Cek stok (10 k, 100 k, 330 ohm, 100 uF) |

## 5. Dihapus dari BOM lama (tidak dipakai di desain)
VL53L0X x2 (Rp80 rb), BME680 (Rp170 rb), AMS1117/step-down, CR2032 + holder, XKC-Y25 (belum dibeli; sensor air analog dipakai).

## 6. Minimum untuk prototipe breadboard (tanpa PCB, power bank/USB)
Vest: ESP32 DevKit, GY-521, GPS NEO-6M, sensor air, 2 tact, 1 resistor 10 k, kabel jumper, LoRa (setelah disolder + antena).
Helmet: SuperMini, 1 tact (opsional), kabel USB (LiPo + TP4056 + saklar nanti).
Gateway: ESP32 DevKit, LoRa + antena, modul microSD + kartu, LED + 330 ohm (pengganti sirine), kabel USB.

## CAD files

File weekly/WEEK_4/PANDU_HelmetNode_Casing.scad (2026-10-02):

// ============================================================
// P.A.N.D.U — Helmet Node Casing (v3: Euroslot mount, PERKIRAAN)
// Komponen: ESP32-C3 SuperMini + CR2032 (badan modul)
//           + TTP223 (pad terpisah, kabel flex ke harness webbing)
// ============================================================
// MOUNTING: pakai slot aksesoris universal "Euroslot" di sisi shell
// helm (lebar 30mm, standar lintas-brand -- earmuff/faceshield pakai
// slot yang sama). Ini titik pasang AMAN krn di luar zona benturan
// crown (celah shell-harness 25-32mm wajib kosong, ANSI Z89.1).
//
// TTP223 TIDAK lagi di badan modul ini -- ditaruh di pad kecil
// terpisah + kabel flex pendek ke webbing harness (titik yang
// beneran deket/nempel kepala). Nggak dimodelkan detail di sini,
// cuma catatan posisi.
//
// PERKIRAAN yang masih perlu diverifikasi:
//   - Kedalaman & ketebalan slot Euroslot (lebar 30mm relatif pasti,
//     tapi depth/thickness tab blade belum ketemu data resminya)
//   - Panjang kabel flex TTP223 ke titik kontak harness
// ============================================================

/* [Render Control] */
explode_factor = 0; // [0:0.1:3]
dxf_view = "none"; // [none, front, top, side]

/* [Dimensi Casing utama (mm)] */
case_w   = 34;   // badan modul, muat ESP32-C3 SuperMini + CR2032
case_h   = 24;
case_t   = 11;  // direvisi dari 9mm -- 9mm nggak cukup buat MCU(4mm)+baterai(3.2mm)+dinding 2x
corner_r = 6;
wall     = 1.5;
lid_t    = 1.5;

/* [Euroslot tab (PERKIRAAN kedalaman & tebal, lebar 30mm cukup pasti)] */
slot_w = 30;   // standar Euroslot, lintas-brand
slot_t = 2.5;  // PERKIRAAN -- verifikasi ke slot fisik
slot_depth = 10; // PERKIRAAN -- seberapa dalam tab masuk ke slot

/* [ESP32-C3 SuperMini] */
mcu_w = 22.5;
mcu_h = 18;
mcu_t = 4;

/* [CR2032] */
batt_d = 20;
batt_t = 3.2;

avail_w = case_w - wall*2;
avail_h = case_h - wall*2;

module rounded_rect(w, h, r) {
    offset(r = r) offset(delta = -r) square([w, h], center = true);
}

module bottom_shell() {
    shell_h = case_t - lid_t;
    difference() {
        linear_extrude(height = shell_h) rounded_rect(case_w, case_h, corner_r);
        translate([0, 0, wall - 0.02])
            linear_extrude(height = shell_h)
                offset(delta = -wall) rounded_rect(case_w, case_h, corner_r);
    }
}

module lid() {
    linear_extrude(height = lid_t) rounded_rect(case_w, case_h, corner_r);
}

// Tab Euroslot -- blade pipih menonjol dari belakang casing
module euroslot_tab() {
    translate([0, 0, -slot_depth/2])
        cube([slot_w, slot_t, slot_depth], center = true);
}

module mcu_board() {
    translate([0, 0, 0])
        cube([mcu_w, mcu_h, mcu_t], center = true);
}

module battery() {
    translate([0, 0, 0])
        cylinder(d = batt_d, h = batt_t, center = true, $fn = 48);
}

module assembly(explode = explode_factor) {
    shell_h = case_t - lid_t;

    color("SteelBlue") bottom_shell();
    color("Gray") euroslot_tab();

    translate([0, 0, wall + mcu_t/2 + explode*10])
        color("LimeGreen") mcu_board();

    translate([0, 0, wall + mcu_t + batt_t/2 + explode*20])
        color("Orange") battery();

    translate([0, 0, shell_h + explode*35])
        color([0.27, 0.31, 0.47, 0.85]) lid();
}

if (dxf_view == "front") {
    projection(cut = false) assembly(0);
} else if (dxf_view == "top") {
    projection(cut = false) rotate([90, 0, 0]) assembly(0);
} else if (dxf_view == "side") {
    projection(cut = false) rotate([0, 90, 0]) assembly(0);
} else {
    assembly();
}

// ---- Cek dimensi (MCU + baterai ditumpuk krn slot mount = casing sempit) ----
w_fits = max(mcu_w, batt_d) <= avail_w;
h_fits = max(mcu_h, batt_d) <= avail_h;
t_needed = wall + mcu_t + batt_t + wall;
t_fits = t_needed <= case_t;
slot_ok = slot_w <= case_w;

echo(str("=== HASIL CEK DIMENSI HELMET NODE (v3, Euroslot mount, PERKIRAAN) ==="));
echo(str("Lebar casing: ", case_w, " mm | komponen terlebar: ", max(mcu_w, batt_d), " mm -- ",
    w_fits ? "MUAT" : "TERLALU SEMPIT"));
echo(str("Tinggi casing: ", case_h, " mm | komponen tertinggi: ", max(mcu_h, batt_d), " mm -- ",
    h_fits ? "MUAT" : "TERLALU PENDEK"));
echo(str("Tebal casing: ", case_t, " mm | butuh (MCU+baterai ditumpuk+dinding): ", t_needed, " mm -- ",
    t_fits ? "MUAT" : "TERLALU TIPIS, naikkan case_t"));
echo(str("Slot Euroslot 30mm muat di lebar casing ", case_w, "mm: ", slot_ok ? "YA" : "TIDAK, lebarkan case_w"));
echo("CATATAN: slot_t & slot_depth masih PERKIRAAN. TTP223 dipasang terpisah (pad + flex cable ke harness webbing), tidak termodelkan di file ini.");

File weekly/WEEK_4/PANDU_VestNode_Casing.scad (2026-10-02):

// ============================================================
// P.A.N.D.U — Vest Node Master Casing
// v4: disesuaikan ke PCB1 final (EasyEDA, 4250x4250 mil) --
//     baterai 18650 sekarang di holder BH-18650-1 DI ATAS PCB,
//     buzzer dihapus, jendela GPS dihapus.
// assembly (shell+lid+PCB+holder baterai) + exploded view + DXF 2D export
// ============================================================
// CARA PAKAI (semua lewat GUI OpenSCAD, nggak perlu command line):
//   1. Buka file ini di OpenSCAD
//   2. Window -> Customizer (kalau panel kanan belum muncul)
//   3. Di tab "Render Control": geser slider "explode_factor" buat
//      lihat exploded view, atau pilih "dxf_view" buat siapkan 2D
//   4. Multi-view 3D: pakai menu View -> Top / Front / Right / Diagonal,
//      lalu File -> Export -> Export as Image (PNG)
//   5. Export teknik 2D: set dxf_view ke "front"/"top"/"side" (explode_factor
//      otomatis dipaksa 0 saat export DXF), preview (F5), lalu
//      File -> Export -> Export as DXF
// ============================================================

/* [Render Control] */
// 0 = assembly normal, naikkan buat pisahkan komponen (exploded view)
explode_factor = 0; // [0:0.1:3]
// pilih view buat export DXF 2D -- "none" nampilin model 3D biasa
dxf_view = "none"; // [none, front, top, side]

/* [PCB1 final (mm)] */
// Outline PCB1 di EasyEDA: 4250 x 4250 mil = 107.95 mm
pcb_w = 108;
pcb_h = 108;
pcb_t = 1.6;

/* [Dimensi Casing (mm)] */
wall      = 2;    // asumsi tebal dinding cetak 3D (PETG)
lid_t     = 2;    // tebal tutup/lid atas
pcb_gap   = 1;    // clearance PCB ke dinding tiap sisi
standoff  = 3;    // tinggi tiang penyangga PCB dari lantai casing
corner_r  = 8;    // radius sudut (sesuai blueprint awal R8)

/* [Holder baterai BH-18650-1 di atas PCB] */
// ukuran diukur dari footprint di PCB1 (~21 x 75 mm); TINGGI = ASUMSI
// (sel 18mm + badan holder), VERIFIKASI ke datasheet / holder yang dibeli
hold_w = 21;
hold_l = 75;
hold_h = 21;
// posisi pojok kiri-atas holder dari pojok kiri-atas PCB (dari layout PCB1)
hold_dx = 7.3;
hold_dy = 2.7;

// ---- Dimensi turunan ----
case_w = pcb_w + 2*(wall + pcb_gap);
case_h = pcb_h + 2*(wall + pcb_gap);
// lantai + standoff + PCB + komponen tertinggi + clearance + lid

/* [Modul boost MT3608 -- dipasang pakai KABEL] */
// Modul TIDAK dicolok ke header U2. Header 1x4 U2 di PCB1 (pusat 3500,2000 mil)
// cuma titik sambung kabel 4 pin (IN+ IN- OUT- OUT+). Modul sendiri ditempel
// (double tape / lem) di SISI BAWAH TUTUP, digantung di atas area kosong
// pojok kanan-bawah, jauh dari GPS (antena) dan plunger tombol SOS.
// Koordinat dari pojok kiri-atas PCB (mm), toleransi +-1.5 mm
boost_pos = [86, 100];      // pusat modul
boost_l = 37;               // panjang modul (sejajar sumbu X)
boost_w = 17;               // lebar modul
boost_h = 5.5;              // tebal modul termasuk induktor (ASUMSI)
header_top = 8.5;           // tinggi header U2 + pin di atas PCB (ASUMSI)

// tinggi casing: lantai + standoff + PCB + komponen tertinggi + clearance + lid
// (modul boost menggantung dari tutup, jadi tidak menentukan tinggi casing)
tall_h = hold_h;
case_t = wall + standoff + pcb_t + tall_h + 1 + lid_t;
// dasar modul di atas PCB = sisi dalam tutup - tebal modul
boost_z0 = (case_t - lid_t) - (wall + standoff + pcb_t) - boost_h;

/* [Bukaan casing] */
// Koordinat komponen = posisi (mm) dari POJOK KIRI-ATAS PCB (layout PCB1,
// diukur dari screenshot EasyEDA -- toleransi +-1.5 mm, cek lagi sebelum cetak)
// Fungsi di bawah mengubahnya ke koordinat model (origin di tengah PCB).
function pcb_xy(px, py) = [px - pcb_w/2, pcb_h/2 - py];

pcb_top_z = wall + standoff + pcb_t;   // permukaan atas PCB dari lantai

// Pembagian sisi (tampak atas model, +Y = atas PCB di EasyEDA):
//   KIRI  (-X)  : USB-C charging  -- dekat modul TP4056 (U7)
//   BAWAH (-Y)  : SMA antena LoRa -- dekat RA-02 (U6)
//   TUTUP (+Z)  : tombol power & SOS, via plunger cetak
//   Water level : XKC-Y25 ditempel di SISI DALAM dinding bawah, TANPA lubang
//   GPS         : TANPA jendela (PETG tipis tembus sinyal), antena menghadap atas
//   Buzzer      : dihapus dari desain

// USB-C (ukuran plug + overmold; blueprint lama 8x4 terlalu pas)
usb_w = 10;   usb_h = 5;
usb_pos = pcb_xy(18, 90);              // y tengah modul U7; x tidak dipakai
usb_z   = pcb_top_z + 3;               // tengah colokan ~3 mm di atas PCB
// SMA / pigtail antena LoRa
sma_d   = 8;
sma_pos = pcb_xy(62.4, 0);             // x di dekat pad ANT RA-02
sma_z   = pcb_top_z + 6;
// Tombol (tact switch di PCB, ditekan lewat plunger di tutup)
sw_power = pcb_xy(33.5, 65.4);         // SW1
sw_sos   = pcb_xy(72.2, 87.1);         // SW2 (SOSButton)
sw_h       = 3.5;                      // ASUMSI tinggi tact switch di atas PCB
btn_hole_d = 6;                        // lubang di tutup
plunger_d  = 5;                        // batang plunger (celah 0.5 mm)
plunger_fl = 8;                        // flens penahan di bawah tutup
plunger_gap = 1;                       // celah plunger ke tombol saat diam

module rounded_rect(w, h, r) {
    offset(r = r) offset(delta = -r) square([w, h], center = true);
}

// ---- PART: bottom shell (tray, terbuka di atas) ----
module bottom_shell() {
    shell_h = case_t - lid_t;
    difference() {
        linear_extrude(height = shell_h) rounded_rect(case_w, case_h, corner_r);
        // offset(delta=-wall) dari profil yang SAMA -> bentuk konsentris presisi,
        // menghindari warning "not a valid 2-manifold" dari CGAL
        translate([0, 0, wall - 0.02])
            linear_extrude(height = shell_h)
                offset(delta = -wall) rounded_rect(case_w, case_h, corner_r);

        // USB-C di dinding kiri (-X): kotak membujur menembus dinding
        translate([-case_w/2, usb_pos[1], usb_z])
            cube([wall*4, usb_w, usb_h], center = true);
        // SMA di dinding bawah (-Y): silinder membujur menembus dinding
        translate([sma_pos[0], -case_h/2, sma_z])
            rotate([90, 0, 0]) cylinder(d = sma_d, h = wall*4, center = true, $fn = 48);
    }
}

// ---- PART: lid / tutup atas (dengan 2 lubang tombol) ----
module lid() {
    difference() {
        linear_extrude(height = lid_t) rounded_rect(case_w, case_h, corner_r);
        for (p = [sw_power, sw_sos])
            translate([p[0], p[1], -0.1])
                cylinder(d = btn_hole_d, h = lid_t + 0.2, $fn = 40);
    }
}

// ---- PART: plunger tombol (cetak terpisah, 2x: power & SOS) ----
// z=0 = permukaan atas PCB. Batang menembus lubang tutup, flens menahan
// plunger supaya tidak lepas keluar, ujung atas menonjol 1.2 mm di atas tutup.
module plunger() {
    shell_h  = case_t - lid_t;
    z0       = sw_h + plunger_gap;                  // dasar batang
    z_lid_in = shell_h - pcb_top_z;                 // sisi dalam tutup
    shaft_h  = (z_lid_in + lid_t + 1.2) - z0;
    translate([0, 0, z0])
        cylinder(d = plunger_d, h = shaft_h, $fn = 40);
    translate([0, 0, z_lid_in - 1.5])
        cylinder(d = plunger_fl, h = 1.5, $fn = 40);
}

// ---- PART: PCB (representasi visual, centered di origin lokal) ----
// ---- PART: modul boost MT3608 di atas header U2 (representasi visual) ----
// z=0 = permukaan atas PCB; panjang modul sejajar sumbu X
module boost_module() {
    p = pcb_xy(boost_pos[0], boost_pos[1]);
    translate([p[0], p[1], boost_z0 + boost_h/2])
        cube([boost_l, boost_w, boost_h], center = true);
}

module pcb() {
    cube([pcb_w, pcb_h, pcb_t], center = true);
}

// ---- PART: holder baterai di atas PCB (representasi visual) ----
// posisi dihitung dari pojok kiri-atas PCB, z=0 = permukaan atas PCB
module battery_holder() {
    translate([-pcb_w/2 + hold_dx + hold_w/2,
                pcb_h/2 - hold_dy - hold_l/2,
                hold_h/2])
        cube([hold_w, hold_l, hold_h], center = true);
}

// ---- ASSEMBLY dengan exploded view ----
// explode_factor=0 -> semua rapat (assembly normal)
// explode_factor naik -> tiap part menjauh dari posisi assembly-nya
module assembly(explode = explode_factor) {
    shell_h = case_t - lid_t;
    pcb_z   = wall + standoff + pcb_t/2;

    color("SteelBlue") bottom_shell();

    translate([0, 0, pcb_z + explode*30]) {
        color("LimeGreen") pcb();
        translate([0, 0, pcb_t/2])
            color("Orange") battery_holder();

    }

    // plunger tombol (ikut naik bareng lid biar kelihatan di exploded view)
    for (p = [sw_power, sw_sos])
        translate([p[0], p[1], pcb_top_z + explode*60])
            color("Gold") plunger();

    // modul boost digantung di sisi bawah tutup -> ikut naik bareng tutup
    translate([0, 0, wall + standoff + pcb_t + explode*60])
        color("Crimson") boost_module();

    translate([0, 0, shell_h + explode*60])
        color([0.27, 0.31, 0.47, 1]) lid(); // alpha dibikin 1 (full opaque) -- alpha<1 bikin OpenSCAD preview (F5) salah urut render transparency
}
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

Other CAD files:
weekly/WEEK_6/PANDU_VestNode_Casing.scad

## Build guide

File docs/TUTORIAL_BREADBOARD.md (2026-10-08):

# Tutorial Rakit Breadboard PANDU (tanpa PCB)

Tujuan: membuktikan rangkaian dan firmware v2 bekerja sebelum PCB dipesan. Semua sambungan diambil dari netlist (`hardware/netlist/PCB1.tel`, `PCB2.tel`, `PCB3.tel`).
Pakai bersama [CHECKLIST_UJI_RAKIT.md](CHECKLIST_UJI_RAKIT.md). Setiap tahap punya "Lulus jika ...": jangan lanjut kalau gagal.

> **Penting.** Nomor pin modul di bawah memakai **label yang tercetak di modul**, bukan nomor pin footprint EasyEDA. Selalu baca label di modul fisik kamu. Kalau tidak cocok dengan tabel, **berhenti dan catat**: itu temuan yang harus diperbaiki di PCB.

## Jalur cepat: prototipe hanya dengan bahan BOM (tanpa boost, MOSFET, LiPo)
Untuk bukti konsep sebelum belanja tambahan. Firmware tidak diubah. Lewati bagian yang disebut "lewati".
Butuh tambahan murah: 2 resistor 10 k (SOS), beberapa jumper, 1 LED + resistor 330 Ω.

**Vest**: daya dari **power bank lewat micro-USB DevKit** (lewati 2.1, 2.2, 2.3, 2.9; tanpa baterai, boost, SS14, TP4056).
- MPU6050 (2.5), GPS langsung ke 3V3 (2.6), LoRa + antena pegas bawaan (2.7), tombol power IO13 dan SOS IO27 (2.8) tetap sama.
- IO4 dan IO32 dibiarkan kosong (firmware tetap jalan, GPS selalu hidup).
- **Sensor air murah**: pinnya biasanya analog, bukan HIGH/LOW bersih. Untuk uji MOB, sambungkan IO34 ke 3V3 pakai jumper selama 3 detik (= basah), lepas (= kering); tambah resistor 10 k IO34 ke GND supaya tidak mengambang. Pakai sensor asli hanya setelah diukur: tegangan pin S saat basah harus > ±2 V.
- Angka baterai (mV) di paket tidak berarti tanpa baterai/pembagi; abaikan.

**Gateway**: daya dari adaptor 5 V lewat micro-USB DevKit. Pin LoRa dan SD sesuai tabel di bagian 3.
- Lewati IRLZ44N dan sirine. Pengganti: **IO4 → LED + 330 Ω → GND** (LED nyala = sirine ON). Jangan sambungkan sirine 85 dB langsung ke pin.

**Helmet**: daya dari **USB SuperMini** (lewati LiPo, TP4056, saklar; CR2032 tidak kuat untuk BLE). TTP223 VCC → 3V3, OUT → GPIO2, tombol GPIO4 ke GND (pull-up internal sudah ada).
- Pada C3 dengan USB, serial putus-sambung tiap siklus deep sleep (8 s). Normal; buka ulang monitor atau baca lewat paket Vest.

**Urutan uji**: Gateway sendiri (`lora":1,"sd":1`) → Vest sendiri (`MPU=1 LoRa=1`) → heartbeat Vest ke Gateway → SOS (LED Gateway menyala) → jatuh dan MOB → Helmet (`helm` di paket berubah `2 → 0 → 1`).
Yang **belum** terbukti dengan jalur ini: daya baterai Vest, gating GPS/XKC, siren daya penuh, helm dengan baterai.

## 0. Keselamatan dan aturan
1. Baterai 18650 **harus berproteksi** (ada PCB proteksi) atau lewat TP4056 modul berproteksi (DW01). Jangan pernah korsleting baterai. Pasang sekring/polyfuse kalau ada.
2. **Jangan transmit LoRa tanpa antena** (merusak chip RF). Pasang antena sebelum upload firmware yang memanggil `LoRa.begin`.
3. Setel **boost ke 5,0 V dengan multimeter sebelum** disambung ke ESP32 atau sensor (lihat 2.1).
4. **Satu sumber 5 V pada satu waktu** untuk ESP32: jika USB dicolok untuk upload, lepas sumber 5 V dari boost ke pin 5V (atau pakai dioda SS14 seperti di PCB).
5. Semua GPIO ESP32 hanya 3,3 V. Pin 5 V tidak boleh masuk ke GPIO.
6. Tiap kali ganti kabel, matikan daya dulu.

## 1. Daftar bahan
**Vest**
- ESP32-DevKitC V4, breadboard besar, kabel jumper M-M / M-F
- Baterai 18650 + holder, modul TP4056 (USB-C, berproteksi), modul boost MT3608
- Dioda SS14 (atau 1N5819), kapasitor 100 µF tantalum/elko, 100 nF
- GY-521 (MPU6050), GPS NEO-6M, modul LoRa (+ adapter 2 mm ke 2,54 mm) + antena
- XKC-Y25 (air), tact switch 2 buah (power dan SOS), resistor 10 k, 100 k (2 buah untuk pembagi baterai + 1 pull), 100 k
- Opsional untuk uji gating: MOSFET P-channel logic-level (mis. AO3401A di adapter SOT-23) dan 2N7000

**Helmet**
- ESP32-C3 SuperMini, LiPo 3,7 V berproteksi (±400-500 mAh) + modul TP4056 USB-C, saklar geser, modul TTP223, tact switch, resistor 100 k, 10 µF dan 100 µF

**Gateway**
- ESP32-DevKitC V4, modul LoRa + antena, modul microSD (SPI), kartu microSD (FAT32)
- IRLZ44N, resistor 220 Ω dan 100 k, sirine 5 V (atau LED + resistor 330 Ω untuk uji), kabel

**Alat**: multimeter, kabel micro-USB data (bukan kabel charge-only), laptop dengan PlatformIO.

## 2. Vest: tahap per tahap

### 2.1 Daya (belum ada ESP32)
Sambungan:

| Dari | Ke | Catatan |
|---|---|---|
| Baterai + | TP4056 `B+` | |
| Baterai - | TP4056 `B-` | |
| TP4056 `OUT+` | Boost `IN+` | net `VBAT_RAW` |
| TP4056 `OUT-` | Boost `IN-` dan GND bersama | |
| Boost `OUT-` | GND bersama | |
| Boost `OUT+` | rel 5 V (net `VBOOST_5V`) | |

Langkah:
1. Colok USB-C ke TP4056 (tanpa baterai dulu), ukur `OUT+`: harus kira-kira 4,2 V atau tegangan USB. Lalu pasang baterai.
2. **Setel trimmer boost** sampai `OUT+` = **5,0 V** (± 0,1).
3. Ukur `VBAT_RAW` (di `OUT+` TP4056): 3,0–4,2 V.

Lulus jika: boost 5,0 V stabil, TP4056 LED charging menyala saat USB dicolok.

### 2.2 Pembagi baterai (BAT_SENSE)
- `VBAT_RAW` → R 100 k → titik tengah → R 100 k → GND.
- Titik tengah → **IO35** dan C 100 nF ke GND.
- Ukur titik tengah = separuh `VBAT_RAW` (4,0 V → 2,0 V).

### 2.3 ESP32 dan sumber 5 V
- Rel 5 V boost → anoda SS14; **katoda** SS14 → pin **5V** DevKit (net `5V_DK`).
- GND bersama → pin GND DevKit.
- 100 µF antara 3V3 dan GND DevKit (net `3V3_SYS`).
- **Jangan** colok USB DevKit saat boost menyuplai 5V tanpa dioda SS14 terpasang.

Upload (USB dicolok, bisa bersamaan dengan SS14):
```
cd firmware/vest_node
python -m platformio run -t upload
python -m platformio device monitor
```
Lulus jika: serial tercetak `Boot: ...`. (MPU/LoRa=0 normal pada tahap ini karena belum disambung.)

### 2.4 Peta pin ESP32 Vest

| Fungsi | Pin DevKit | Ke modul / komponen |
|---|---|---|
| Tombol power | **IO13** | tact → GND (pull-up internal) |
| Tombol SOS | **IO27** | tact → **3V3**, resistor 10 k dari IO27 ke GND (aktif-HIGH) |
| Sensor air `WATER_SIG` | **IO34** | output XKC-Y25 (lihat catatan tipe output) |
| Enable GPS | **IO4** | gate P-MOSFET (lihat 2.9); sementara kosongkan |
| Enable XKC | **IO32** | gate N-MOSFET (lihat 2.9); sementara kosongkan |
| Baterai | **IO35** | titik tengah pembagi (2.2) |
| I2C SDA / SCL | **IO21 / IO22** | GY-521 SDA / SCL |
| GPS RX (ESP) / TX (ESP) | **IO16 / IO17** | **TX modul GPS → IO16**, RX modul GPS ← IO17 |
| SPI SCK / MISO / MOSI | **IO18 / IO19 / IO23** | LoRa SCK / MISO / MOSI |
| LoRa NSS (CS) | **IO5** | |
| LoRa RESET | **IO25** | |
| LoRa DIO0 | **IO26** | |

### 2.5 MPU6050 (GY-521)
- VCC → 3V3, GND → GND, SCL → IO22, SDA → IO21.
- Lulus jika serial: `Boot: MPU=1 ...`.
- **Catatan PCB:** urutan pin footprint GY-521 di PCB tampak terbalik dari urutan header modul (VCC, GND, SCL, SDA, XDA, XCL, AD0, INT). Cek apakah footprint cocok dengan modul fisik, atau modul harus dipasang terbalik. Catat hasilnya (temuan PCB).

### 2.6 GPS NEO-6M
- VCC → 3V3 (sementara langsung, tanpa gating), GND → GND.
- Pin **TX modul** → **IO16**, pin **RX modul** → **IO17**.
- Lulus jika: di luar ruangan, setelah beberapa menit paket berisi lat/lon (bukan `NOFIX`).

### 2.7 LoRa (pasang antena dulu)
Label modul → pin DevKit: `3.3V` → 3V3, `GND` → GND (semua pin GND), `SCK` → IO18, `MISO` → IO19, `MOSI` → IO23, `NSS` → IO5, `RESET` → IO25, `DIO0` → IO26. **Pin 1 modul = antena (ANT)**, bukan GND.
- Lulus jika: `Boot: MPU=1 LoRa=1 ...`. Jika `LoRa=0`: cek kabel, GND, 3V3, dan label modul (modul yang dibeli mungkin bukan RA-02: baca label di sisi pin).
- Daya: arus pulsa transmit ±120 mA. Sertakan 100 µF dekat modul.

### 2.8 Sensor air XKC-Y25 dan tombol
- XKC-Y25: `VCC` → 5 V (rel `VBOOST_5V`), `GND` → GND, `OUT` → **IO34**, dengan resistor 10 k dari IO34 ke 3V3 (pull-up).
- **Cek tipe output dulu**: ukur pin OUT saat kering dan basah. Jika outputnya naik ke 5 V, **jangan sambung ke IO34** langsung: pasang pembagi 10 k/20 k atau level shifter.
- Tombol power: antara IO13 dan GND. Tombol SOS: antara IO27 dan 3V3, plus 10 k dari IO27 ke GND.
- Lulus jika: celup sensor 3 detik → serial/LoRa `MOB`. Tahan tombol SOS 2 detik → `SOS`. Tekan tombol power → `Sleep...`, lalu SOS membangunkan alat dan langsung mengirim.

### 2.9 (Opsional) Gating GPS / XKC
Di PCB, GPS lewat P-MOSFET (Q1), XKC lewat P-MOSFET + N-MOSFET (Q2/Q5). Di breadboard, SOT-23 sulit. Uji gating terpisah dengan adapter SOT-23:
- GPS: source P-MOSFET → 3V3, drain → VCC GPS, gate → IO4 dan pull-up 100 k ke 3V3. IO4 LOW = ON, hi-Z (INPUT) = OFF.
- XKC: source P-MOSFET → 5 V, drain → VCC XKC, gate → pull-up 100 k ke 5 V; N-MOSFET: gate ← IO32 (pull-down 100 k ke GND), source → GND, drain → gate P-MOSFET. IO32 HIGH = ON.
- Lulus jika: ukur VCC modul ON ≈ 3,3 V / 5 V dan OFF ≈ 0 V.

### 2.10 Tes sistem Vest
Lihat tahap 2 pada [CHECKLIST_UJI_RAKIT.md](CHECKLIST_UJI_RAKIT.md): jatuh, MOB, SOS, baterai (kalibrasi `BAT_DIV`), tidur/bangun.

## 3. Gateway

| Fungsi | Pin DevKit | Ke |
|---|---|---|
| LoRa SCK / MISO / MOSI | **IO18 / IO19 / IO23** | modul LoRa SCK / MISO / MOSI |
| LoRa NSS | **IO5** | |
| LoRa RESET | **IO14** | (beda dengan Vest!) |
| LoRa DIO0 | **IO26** | |
| SD SCK / MISO / MOSI | IO18 / IO19 / IO23 | bus SPI **sama** dengan LoRa |
| SD CS | **IO13** | + pull-up 10 k ke 3V3 |
| Sirine drive | **IO4** | → 220 Ω → gate IRLZ44N; gate → 100 k → GND |
| 3V3 / GND | 3V3, GND | LoRa, SD |

- IRLZ44N: source → GND, drain → sirine `−`; sirine `+` → pin 5V DevKit. Untuk uji awal pakai **LED + resistor 330 Ω** sebagai pengganti sirine.
- Modul microSD butuh 5 V atau 3,3 V sesuai modulnya: cek label (kebanyakan modul punya regulator dan menerima 5 V, tetapi level SPI harus 3,3 V).
- **Hanya satu port USB**. Gateway diprogram lewat micro-USB DevKit; sirine disuplai dari pin 5V DevKit (arus sirine mengalir lewat jalur USB).
- Upload dan monitor:
```
cd firmware/gateway
python -m platformio run -t upload
python -m platformio device monitor
```
- Lulus jika: `{"boot":true,"lora":1,"sd":1}`. Kirim `M` di serial untuk mute.

## 4. Helmet

| Fungsi | Pin SuperMini | Ke |
|---|---|---|
| Sensor sentuh | **GPIO2** | OUT TTP223 (aktif-HIGH) |
| Tombol on/off | **GPIO4** | tact → GND, pull-up 100 k ke 3V3 |
| Daya masuk | pin **5V** | LiPo `+` > TP4056 `B+`; TP4056 `OUT+` > saklar geser > pin 5V SuperMini (net `VBAT_SW`). Jangan ke pin 3V3 (4,2 V terlalu tinggi) |
| 3V3 | pin 3V3 (output) | catu TTP223, 10 µF + 100 µF ke GND |
| GND | GND | `−` CR2032, TTP223 GND |
| TTP223 VCC | 3V3 | |

- **Daya:** baterai masuk lewat pin 5V (bukan 3V3). Cek di board fisik bahwa pin 5V melewati regulator 3,3 V dan ada dioda ke VBUS; ukur 3V3 = 3,3 V dengan baterai 3,3-4,2 V. Isi baterai lewat USB-C TP4056, bukan lewat USB SuperMini.
- Upload lewat USB SuperMini (saklar geser OFF supaya aman):
```
cd firmware/helmet_node
python -m platformio run -t upload
python -m platformio device monitor
```
- Lulus jika: sentuh sensor → setelah 2 siklus (±8–16 s) `helm dipakai=1`; lepas → `0` setelah 3 siklus. Tombol: OFF/ON bergantian.
- Ukur arus rata-rata dengan multimeter ampere seri dengan baterai.

## 5. Tautan Vest ↔ Gateway ↔ Helmet
1. Nyalakan Gateway (serial terbuka). Nyalakan Vest. Tunggu `HB` (heartbeat 30 s) muncul di Gateway: `{"type":"HB",...,"rssi":-xx}`.
2. Tekan SOS di Vest → sirine/LED Gateway menyala dalam < 2 detik, baris baru di `/pandu.csv`.
3. Nyalakan Helmet dan sentuh sensor: field `helm` di paket Vest berubah `2 → 0 → 1` dalam ≤ 24 s.

## 6. Troubleshooting singkat

| Gejala | Cek |
|---|---|
| ESP32 tidak terdeteksi USB | kabel data, driver CP210x/CH340, tahan BOOT saat upload |
| `LoRa=0` | antena, 3V3, GND, label pin modul, NSS/RST/DIO0 benar |
| `MPU=0` | SDA/SCL tertukar, VCC, alamat 0x68 (AD0 ke GND) |
| GPS selalu `NOFIX` | di luar ruangan, TX/RX tertukar, tunggu cold start |
| Reset acak | catu 3V3/5V jatuh (kapasitor 100 µF, kabel panjang), arus sirine |
| Boost keluar bukan 5 V | setel trimmer sebelum disambung |
| Tidak bangun dari sleep | tombol ke pin RTC yang benar (IO13, IO27), wiring tombol |

## 7. Catat temuan untuk revisi PCB
Setiap kali pinout/ukuran modul tidak cocok dengan skematik, tulis di sini lalu laporkan:

| Modul | Temuan | Dampak PCB |
|---|---|---|
| LoRa XL1276-P01 (chip SX1276) | Dari foto sisi pad: kolom kiri atas ke bawah `DIO2, DIO1, DIO0, VCC, DIO4, DIO3, GND, ANT`; kolom kanan `GND, MISO, MOSI, SCK, NSS, REST, DIO5, GND`. Urutan ini = pinout **RFM95**, bukan RA-02 (RA-02: 1 ANT, 2 GND, 3 3,3V, 4 RST, 5 DIO0, ... 15 NSS). | Footprint `WIRELM-SMD_RA-02-BL` di PCB1/PCB3 **tidak cocok** dengan modul ini. Ganti footprint ke RFM95 (atau beli Ra-01H) sebelum order PCB. Cek juga jarak antar deret pad. |
| LoRa XL1276-P01 | Di foto sisi pad, kotak pita frekuensi (915M/868M/433M/315M/169M) yang terisi/ditandai hitam adalah **868M**. Belum dicek di modul fisik. | Kalau modul fisik juga 868M, matching RF-nya untuk 868 MHz, bukan 915/920 MHz. Cek modul dan listing. |

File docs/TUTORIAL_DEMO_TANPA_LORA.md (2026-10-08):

# Tutorial demo: Helmet Node dan Vest Node (tanpa LoRa)

Tujuan: demo bahwa fungsi inti Vest dan Helmet berjalan. Daya dari USB laptop, dua laptop dengan serial monitor (Laptop A = Vest, Laptop B = Helmet). Tanpa LoRa, Gateway, dashboard, dan baterai.

Yang didemokan:
- Helm: beacon BLE dengan tombol ON/OFF.
- Vest: deteksi helm dari RSSI (dekat, jauh, tidak terdengar), jatuh (FALL), MOB (jatuh DAN air dalam 60 detik), SOS manual (tahan 2 detik), tombol power (tidur dan bangun), GPS (opsional, perlu di luar ruangan).
- Paket yang akan dikirim lewat LoRa tetap dicetak ke serial (`PANDU,V1,...`), jadi isi paket bisa ditunjukkan.

Tidak didemokan: pengiriman LoRa, Gateway, dashboard, baterai dan charging.

## 0. Persiapan
- Dua kabel micro-USB **data** (bukan charge-only) dan USB-C/micro sesuai board. Pakai kabel pendek dan tebal (BLE bisa memicu brownout kalau kabel buruk).
- PlatformIO terpasang (`python -m platformio --version`), repo `pandu-capstone` di laptop yang dipakai untuk upload.
- **Tip:** upload kedua firmware dari satu laptop dulu. Setelah itu board cukup dicolok ke laptop masing-masing untuk daya dan serial.
- Cari port tiap board: `python -m platformio device list`. DevKit biasanya CP210x, SuperMini biasanya `303A:1001`. Ganti `COMx` di perintah di bawah.

## 1. Helmet Node (SuperMini ESP32-C3), Laptop B

### Bahan
ESP32-C3 SuperMini, 1 tact switch, 2 kabel jumper, kabel USB. (Tanpa TTP223, tanpa baterai.)

### Wiring
```
SuperMini pin GPIO4 ---- [tact switch] ---- SuperMini pin GND
```
Pull-up sudah internal. Daya dan serial lewat kabel USB ke laptop.

### Upload (mode demo: siaran terus, serial tetap hidup)
```bash
cd pandu-capstone/firmware/helmet_node
python -m platformio run -e supermini_test -t upload --upload-port COMx
python -m platformio device monitor --port COMx
```
Kalau upload macet: tahan **BOOT**, tekan **RESET**, lepas BOOT, ulangi. Setelah upload tekan RESET sekali.

### Yang muncul di serial
```
HELMET demo: beacon ON. Tekan tombol (GPIO4) untuk ON/OFF.
siaran counter=1
siaran counter=2
```
Tekan tombol: `BEACON OFF`, tekan lagi: `BEACON ON`. Counter naik tiap detik selama ON.

Catatan: mode ini bukan firmware produk (produk memakai deep sleep, `-e supermini`). Deep sleep memutus serial USB tiap 8 detik, jadi tidak cocok untuk demo dengan serial monitor.

## 2. Vest Node (ESP32 DevKit), Laptop A

### Bahan
ESP32-DevKitC, GY-521 (MPU6050), GPS NEO-6M, sensor air (sensor murah S/+/- atau XKC-Y25), 2 tact switch, 1 resistor 10 kΩ, kapasitor 100 µF (disarankan), breadboard, jumper, kabel micro-USB.

### Wiring lengkap
```
                           ESP32 DevKit (daya: micro-USB dari laptop)
                       +----------------------------------+
 GY-521 (MPU6050)      |                                  |
   VCC ----------------| 3V3                              |
   GND ----------------| GND                              |
   SDA ----------------| IO21                             |
   SCL ----------------| IO22                             |
                       |                                  |
 GPS NEO-6M            |                                  |
   VCC ----------------| 3V3                              |
   GND ----------------| GND                              |
   TX  ----------------| IO16   (TX GPS ke RX ESP)        |
   RX  ----------------| IO17                             |
                       |                                  |
 Sensor air            |                                  |
   (lihat 2.2)         | IO34                             |
                       |                                  |
 Tombol SOS            |                                  |
   kaki A -------------| 3V3                              |
   kaki B ---+---------| IO27                             |
             |         |                                  |
          [10 kOhm]    |                                  |
             |         |                                  |
            GND        |                                  |
                       |                                  |
 Tombol power          |                                  |
   kaki A -------------| IO13                             |
   kaki B -------------| GND                              |
                       |                                  |
 Kapasitor 100 uF: antara pin 3V3 dan GND (kaki panjang ke 3V3)
                       +----------------------------------+
```
Dibiarkan kosong: IO4, IO32, IO35 (tidak dipakai di demo). Angka mV baterai di paket tidak berarti.
Semua GND disatukan di satu rel breadboard.

### 2.1 Upload
```bash
cd pandu-capstone/firmware/vest_node
python -m platformio run -t upload --upload-port COMx
python -m platformio device monitor --port COMx
```
Serial awal: `Boot: MPU=1 LoRa=0 wake=other`. `LoRa=0` **normal** (LoRa tidak dipasang), program tetap jalan dan mencetak paket ke serial.

### 2.2 Sensor air (pilih satu)
**Sensor murah (S, +, -):**
```
Sensor +  ---- 3V3   (jangan 5 V)
Sensor -  ---- GND
Sensor S  ---- IO34   (tanpa resistor)
```
Kering terbaca sekitar 150-250 mV, basah sekitar 1700-2000 mV. Ambang di firmware 1000 mV (`WATER_WET_MV`).

**XKC-Y25 (kalau sudah ada):**
```
XKC VCC (coklat) ---- pin VIN/5V DevKit   (5 V dari USB)
XKC GND (biru)   ---- GND
XKC OUT (kuning) ---- [10 kOhm] ---- IO34 ---- [20 kOhm] ---- GND
```
Ukur output dulu dengan multimeter (kering dan basah). Tanpa pembagi, output 5 V merusak IO34. Firmware menganggap **tegangan tinggi = ada air**; kalau XKC kamu kebalikannya, kabari supaya logika dibalik. Sensitivitas diatur di potensiometer sensor.

### 2.3 Tahap perakitan (cek tiap tahap sebelum lanjut)
| Tahap | Tambahkan | Yang harus muncul di serial |
|---|---|---|
| 1 | Hanya DevKit | `Boot: MPU=0 LoRa=0 ...` |
| 2 | + GY-521 | `MPU=1`, `g=` sekitar 1.00-1.20 di baris `[status]` |
| 3 | + tombol power dan SOS | Tahan SOS 2 detik: paket `PANDU,V1,SOS,...`. Tekan power: `Sleep...` |
| 4 | + sensor air | `air=kering (xxx mV)`, celup: `air=ADA AIR` |
| 5 | + GPS | `gps=NOFIX` (dalam ruangan), `FIX` di luar ruangan |
| 6 | Helmet menyala | `helm=1` setelah beberapa detik |

### 2.4 Baris serial Vest
Tiap 2 detik:
```
[status] helm=1 rssi=-62 dBm | air=kering (180 mV) | jendela MOB=0s | gps=NOFIX sat=0 | g=1.02
```
| Bagian | Arti |
|---|---|
| `helm=1` | Beacon helm terdengar dan dekat (RSSI di atas ambang) |
| `helm=0` | Terdengar tapi jauh (RSSI lemah) |
| `helm=2` | Tidak terdengar lebih dari 30 detik (helm OFF atau terlalu jauh) |
| `air` | `kering` atau `ADA AIR` plus tegangan sensor |
| `jendela MOB=Ns` | Sisa jendela 60 detik setelah FALL (0 = tidak aktif) |
| `g` | Besar percepatan (1.0 = diam) |

Paket yang terkirim (untuk LoRa nanti), contoh:
```
PANDU,V1,HB,NOFIX,NOFIX,<mV>,1,0      heartbeat tiap 30 detik
PANDU,V1,SOS,NOFIX,NOFIX,<mV>,1,0     SOS (ulang tiap 5 detik, 3 kali)
PANDU,V1,FALL,...                     jatuh
PANDU,V1,MOB,...                      jatuh + air
```
Kolom ke-7 = status helm (1/0/2), kolom ke-8 = usia posisi GPS (detik).

## 3. Skenario demo (urut)
Taruh Helmet sekitar 0,3-0,5 m dari Vest.

1. **Boot**: Vest `MPU=1 LoRa=0`, Helmet `beacon ON`.
2. **Helm dekat**: `helm=1` di status Vest dalam beberapa detik.
3. **Helm dimatikan**: tekan tombol Helmet (`BEACON OFF`). Setelah 30 detik status Vest jadi `helm=2` (tidak terjangkau). Tekan lagi, kembali `helm=1`.
4. **Helm dijauhkan** (beberapa meter atau di balik dinding): `helm=0` saat RSSI di bawah ambang -85 dBm (`HELM_RSSI_MIN`, perlu kalibrasi, lihat bawah).
5. **SOS manual**: tahan tombol SOS 2 detik, paket `SOS` muncul (diulang 3 kali).
6. **FALL**: jatuhkan Vest dari sekitar 0,5-1 m ke bantal tebal. Paket `FALL` muncul dan `jendela MOB` mulai 60 detik.
7. **MOB**: setelah FALL (dalam 60 detik), celupkan sensor air selama 3 detik atau lebih. Paket `MOB` muncul.
8. **Basah saja**: celup sensor air tanpa jatuh dulu, **tidak ada** alarm (hanya `air=ADA AIR` di status).
9. **Power**: tekan tombol power (`Sleep...`), lalu SOS saat tidur membangunkan dan langsung mengirim paket SOS. Tombol power juga membangunkan.
10. **GPS** (opsional): bawa ke luar ruangan dan tunggu fix. Kolom lat/lon terisi.

## 4. Kalibrasi singkat sebelum demo
- **RSSI helm**: letakkan Helmet pada jarak "dipakai" (sekitar 0,3-0,5 m dari Vest) dan lihat `rssi=` di status. Lalu pada jarak "tidak dipakai" (2-3 m). Pilih `HELM_RSSI_MIN` di tengahnya, ubah di `firmware/vest_node/src/main.cpp`, lalu upload ulang. Default -85 dBm.
- **Jatuh**: kalau FALL tidak terpicu di bantal, turunkan `IMPACT_G` (2,5 g); kalau terlalu sensitif, naikkan `FREEFALL_MS`.
- **Air**: kalau air tidak terbaca, cek mV saat basah dan sesuaikan `WATER_WET_MV`.

## 5. Masalah umum
| Gejala | Cek |
|---|---|
| Board reset terus dengan "Brownout detector was triggered" | Ganti kabel USB (pendek, tebal), tambah 100 µF di 3V3, lepas modul yang tidak dipakai, coba port USB lain |
| Port tidak terdeteksi | Kabel data, driver, tahan BOOT saat colok (SuperMini) |
| Serial kosong di SuperMini | Tekan RESET sekali, pastikan hanya satu monitor membuka port |
| `MPU=0` | SDA/SCL tertukar, VCC, GND |
| `helm=2` terus | Helmet belum menyala atau terlalu jauh, cek serial Helmet, dekatkan |
| FALL tidak terpicu | Jatuhkan lebih tinggi (>=0,5 m), cek `g=` turun di bawah 0,6 saat jatuh |
| MOB tidak terpicu | MOB hanya setelah FALL dan dalam 60 detik; air harus aktif 3 detik |
| SOS terpicu sendiri | Resistor 10 kΩ IO27 ke GND belum terpasang |

## 6. Batasan demo
- LoRa tidak dites; pengiriman ke Gateway dan dashboard belum ada.
- Daya dari USB, bukan baterai; umur baterai belum terbukti.
- Ambang jatuh, air, dan RSSI belum divalidasi di kondisi nyata (badan, kapal, hujan).
- GPS di dalam ruangan tidak akan fix.

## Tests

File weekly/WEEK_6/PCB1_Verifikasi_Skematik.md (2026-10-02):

# Verifikasi skematik PCB1 (Vest Node Master)

Sumber: netlist hasil export EasyEDA (`Netlist_PCB1_2026-10-01.tel`). Dibandingkan dengan
pinout datasheet dari ingatan, BUKAN dari datasheet yang dibuka langsung -> yang bertanda
"VERIFIKASI" harus dicek ke datasheet/modul fisik.

## Temuan serius (perlu diperbaiki sebelum order)

1. **AMS1117-3.3 (U3) tidak bisa menghasilkan 3.3 V dari baterai Li-ion.**
   Dropout ~1.1 V -> butuh Vin >= 4.4 V, padahal baterai 3.0-4.2 V (VBAT_RAW ke U3.3).
   Saat baterai < ~4.4 V, 3V3_SYS turun ikut baterai. Ganti ke LDO low-dropout
   (mis. AP2112K-3.3, HT7333, XC6220) atau suplai dari boost 5 V.
2. **Dua sumber 3.3 V diparalel.** 3V3_SYS (output U3) tersambung ke U1.2 (pin 3V3 DevKit),
   sementara U1.16 (VBAT_RAW) masuk ke pin daya DevKit yang punya LDO sendiri. Dua output
   regulator di satu net -> arus balik/berebut. Pilih satu: suplai DevKit lewat pin 5V
   dan jangan sambung 3V3_SYS ke pin 3V3 DevKit, atau sebaliknya.
3. **SW1 adalah tact switch SMD (SW-SMD L3.9 W3.0) dipakai sebagai saklar daya.**
   Momentary (tidak mengunci) dan rating ~50 mA, sedangkan jalur ini membawa seluruh
   arus beban. Ganti ke slide switch / saklar latching berarus >= 1 A.
4. **RA-02 (U6): hanya pin 1 yang ke GND.** Modul punya beberapa pad GND (VERIFIKASI
   pin 2/9/16 di datasheet). GND yang tidak tersambung merusak ground RF dan jangkauan.

## Perlu diverifikasi

5. U1 (ESP32-DevKitM-1): footprint bernama `34P-L43.8` sedangkan DevKitM-1 asli ~54 mm
   dengan 30 pin. VERIFIKASI footprint dan tabel pin sebelum percaya nomor pin di bawah.
6. GPS_RX/GPS_TX: modul GPS RX (U9.2) ke U1.11, TX (U9.3) ke U1.12. Cek di firmware
   bahwa pin 11/12 bukan pin flash/strapping dan UART di-map: RX modul <- TX ESP.
7. C1 100 uF dan C2 10 uF memakai footprint 0603. 100 uF di 0603 jarang/mahal dan
   kapasitansinya turun banyak saat dibias. AMS1117 juga minta kapasitor output >= 22 uF
   ber-ESR (tantalum), bukan keramik murni -> bisa osilasi.
8. TP4056 modul (U7): VBUS_5V hanya terhubung ke U7.5 (tidak dipakai di tempat lain),
   tidak berbahaya. VERIFIKASI urutan pin 1-6 modul fisik (OUT+, B+, GND...).
   Pastikan modul punya proteksi DW01 (over-discharge); tanpa itu sel Li-ion bisa rusak.

## Yang sudah sesuai

| Blok | Net | Hasil |
|---|---|---|
| LoRa SPI | SCK/MISO/MOSI/CS -> U6.12/13/14/15 | cocok dengan pinout Ra-02 (SCK, MISO, MOSI, NSS) |
| LoRa kontrol | RST U6.4, DIO0 U6.5, 3V3 U6.3 | cocok |
| I2C MPU6050 | SCL U8.6, SDA U8.5, VCC U8.8, GND U8.7 | konsisten; GY-521 sudah punya pull-up |
| Sensor air | VCC VBOOST_5V (U10.2), OUT -> R1 pull-up 10k ke 3V3 -> U1.8 | sesuai rencana (varian NPN) |
| Tombol SOS | SW2 -> 3V3, R2 10k pulldown, BTN_SOS -> U1.14 | benar, aktif-tinggi |
| Boost | U2.1 VBAT_RAW, U2.2/3 GND, U2.4 VBOOST_5V | konsisten dengan rencana |
| Baterai | BT1.1 VBAT_POS -> U7.2, BT1.2 GND | benar |

Semua net lain punya >= 2 simpul, tidak ada net yatim kecuali VBUS_5V (1 simpul).

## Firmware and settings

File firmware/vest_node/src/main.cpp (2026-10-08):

// PANDU Vest Node: firmware dasar (ESP32-DevKitC V4, Arduino core)
// Pin mengikuti HANDOVER.md. Nilai ber-tanda "KALIBRASI" perlu di-tune di perangkat nyata.
#include <Arduino.h>
#include <Wire.h>
#include <SPI.h>
#include <LoRa.h>
#include <TinyGPSPlus.h>
#include "driver/rtc_io.h"
#include <NimBLEDevice.h>
#ifdef DEMO_NO_BROWNOUT
#include "soc/soc.h"
#include "soc/rtc_cntl_reg.h"
#endif

// ---- Pin ----
constexpr int PIN_PWR_BTN  = 13;  // tact (ke GND), RTC: toggle deep sleep
constexpr int PIN_SOS      = 27;  // tact ke 3V3, pull-down R2 10k di PCB (aktif HIGH), tahan SOS_HOLD_MS
constexpr int PIN_BAT      = 35;  // BAT_SENSE: pembagi 100k/100k dari VBAT_RAW (ADC1_CH7, input-only)
constexpr int PIN_WATER    = 34;  // output XKC-Y25 (input-only, tanpa pull internal)
constexpr int PIN_GPS_EN   = 4;   // gate P-MOSFET Q1: LOW=ON, hi-Z=OFF (JANGAN drive HIGH)
constexpr int PIN_XKC_EN   = 32;  // via Q5: HIGH=ON, LOW/hi-Z=OFF
constexpr int PIN_GPS_RX   = 16;  // ESP RX <- GPS TX (asumsi, cek skematik)
constexpr int PIN_GPS_TX   = 17;
constexpr int PIN_SDA = 21, PIN_SCL = 22;
constexpr int PIN_LORA_CS = 5, PIN_LORA_RST = 25, PIN_LORA_DIO0 = 26;

// ---- Parameter (KALIBRASI) ----
constexpr long LORA_FREQ       = 915E6;   // modul dibeli 915 MHz (regulasi ID 920-923 MHz)
constexpr float FREEFALL_G     = 0.6f;    // |a| di bawah ini = jatuh bebas (tes nyata: terbaca 0,3-0,5 g karena offset sensor)
constexpr uint32_t FREEFALL_MS = 120;
constexpr float IMPACT_G       = 2.5f;    // benturan setelah jatuh bebas
constexpr uint32_t IMPACT_WIN  = 1000;    // jendela benturan setelah free-fall
constexpr uint32_t MOB_WINDOW_MS = 60000;   // MOB = jatuh DAN basah dalam jendela ini setelah jatuh
constexpr uint32_t WATER_MS    = 3000;    // sensor air harus aktif sebanyak ini = MOB
constexpr int WATER_WET_MV     = 1000;    // KALIBRASI: sensor murah analog, kering 140-230 mV, basah 1700-2070 mV
constexpr uint32_t SOS_HOLD_MS = 2000;
constexpr uint32_t HEARTBEAT_MS = 30000;
constexpr uint32_t ALERT_REPEAT_MS = 5000;
constexpr float BAT_DIV = 2.0f;     // KALIBRASI: faktor pembagi (cek dengan multimeter)
constexpr uint8_t MPU = 0x68;

TinyGPSPlus gps;
HardwareSerial gpsSerial(2);
bool loraOk = false, mpuOk = false;

void helmScanStop();  // didefinisikan di bagian Helm

// ---- Power gating ----
void gpsPower(bool on) {
  if (on) { pinMode(PIN_GPS_EN, OUTPUT); digitalWrite(PIN_GPS_EN, LOW); }
  else    { pinMode(PIN_GPS_EN, INPUT); }  // hi-Z: pull-up R3 100k ke 3V3_SYS mematikan Q1
}
void xkcPower(bool on) { pinMode(PIN_XKC_EN, OUTPUT); digitalWrite(PIN_XKC_EN, on); }

// ---- Deep sleep ----
void goToSleep() {
  Serial.println("Sleep...");
  gpsPower(false); xkcPower(false);
  helmScanStop();
  if (loraOk) LoRa.sleep();
  while (digitalRead(PIN_PWR_BTN) == LOW || digitalRead(PIN_SOS) == HIGH) delay(10);   // tunggu lepas agar tidak langsung bangun
  delay(50);
  rtc_gpio_pullup_en((gpio_num_t)PIN_PWR_BTN);
  rtc_gpio_pulldown_dis((gpio_num_t)PIN_PWR_BTN);
  esp_sleep_enable_ext0_wakeup((gpio_num_t)PIN_PWR_BTN, 0);          // tombol power: aktif-LOW
  rtc_gpio_pulldown_en((gpio_num_t)PIN_SOS);                         // SOS: aktif-HIGH (R2 10k juga menahan LOW)
  rtc_gpio_pullup_dis((gpio_num_t)PIN_SOS);
  esp_sleep_enable_ext1_wakeup(1ULL << PIN_SOS, ESP_EXT1_WAKEUP_ANY_HIGH);  // SOS membangunkan alat saat sleep
  esp_deep_sleep_start();
}

// ---- MPU6050 (register mentah, +-8 g) ----
void mpuWrite(uint8_t r, uint8_t v) { Wire.beginTransmission(MPU); Wire.write(r); Wire.write(v); Wire.endTransmission(); }
bool mpuInit() {
  Wire.beginTransmission(MPU);
  if (Wire.endTransmission() != 0) return false;
  mpuWrite(0x6B, 0x00);  // wake
  mpuWrite(0x1C, 0x10);  // +-8 g -> 4096 LSB/g
  return true;
}
float accelG() {
  Wire.beginTransmission(MPU); Wire.write(0x3B); Wire.endTransmission(false);
  if (Wire.requestFrom((int)MPU, 6) != 6) return 1.0f;  // gagal baca = anggap diam
  float ax = (int16_t)(Wire.read() << 8 | Wire.read()) / 4096.0f;
  float ay = (int16_t)(Wire.read() << 8 | Wire.read()) / 4096.0f;
  float az = (int16_t)(Wire.read() << 8 | Wire.read()) / 4096.0f;
  return sqrtf(ax * ax + ay * ay + az * az);
}

// ---- Helm (BLE scanner) ----
// Helmet menyiarkan manufacturer data {FF FF 'P' 'H' worn counter} tiap ~8 s (burst 400 ms).
constexpr uint32_t HELM_TIMEOUT_MS = 30000;   // tidak terdengar > 30 s = helm tidak terjangkau (KALIBRASI)
volatile uint32_t helmSeenAt = 0;             // millis() terakhir paket valid; 0 = belum pernah
volatile uint8_t helmWorn = 0;
constexpr int HELM_RSSI_MIN = -85;            // KALIBRASI: RSSI (dBm, dirata-rata) minimum agar worn=1 dihitung "dipakai"; lebih lemah = helm jauh = tidak dipakai
volatile float helmRssi = -127;               // rata-rata bergerak RSSI paket helm (EMA)

class HelmCb : public NimBLEAdvertisedDeviceCallbacks {
  void onResult(NimBLEAdvertisedDevice *d) override {
    if (!d->haveManufacturerData()) return;
    std::string m = d->getManufacturerData();
    if (m.size() >= 5 && (uint8_t)m[0] == 0xFF && (uint8_t)m[1] == 0xFF && m[2] == 'P' && m[3] == 'H') {
      helmWorn = (uint8_t)m[4] ? 1 : 0;
      helmRssi = helmSeenAt ? helmRssi * 0.8f + d->getRSSI() * 0.2f : d->getRSSI();   // RSSI BLE naik-turun +-10 dB: dirata-ratakan
      helmSeenAt = millis() ? millis() : 1;
    }
  }
};
HelmCb helmCb;

void helmScanStart() {
  NimBLEDevice::init("");
  NimBLEScan *scan = NimBLEDevice::getScan();
  scan->setAdvertisedDeviceCallbacks(&helmCb, true);
  scan->setActiveScan(false);                  // pasif: hemat daya, manufacturer data ada di paket iklan
  scan->setInterval(100);                      // satuan 0,625 ms -> 62,5 ms
  scan->setWindow(50);                         // ~50% radio aktif (KALIBRASI: turunkan jika boros, helm hanya 400 ms/8 s)
  scan->setDuplicateFilter(false);
  scan->start(0, nullptr, false);              // scan terus-menerus
}
void helmScanStop() { NimBLEDevice::getScan()->stop(); NimBLEDevice::deinit(true); }

// 1 = dipakai, 0 = terdengar tapi tidak dipakai, 2 = tidak terjangkau
int helmState() {
  if (!helmSeenAt || millis() - helmSeenAt > HELM_TIMEOUT_MS) return 2;
  return helmWorn && helmRssi >= HELM_RSSI_MIN;   // dipakai = sentuh terdeteksi DAN dekat
}

// ---- Baterai ----
int batMilliVolts() {  // rata-rata 8 sampel, analogReadMilliVolts memakai kalibrasi eFuse ESP32
  uint32_t sum = 0;
  for (int i = 0; i < 8; i++) sum += analogReadMilliVolts(PIN_BAT);
  return (int)(sum / 8 * BAT_DIV);
}

// ---- LoRa ----
void sendPkt(const char *type) {
  while (gpsSerial.available()) gps.encode(gpsSerial.read());
  static double lastLat, lastLon; static uint32_t lastFixAt = 0;  // posisi valid terakhir (RAM, hilang saat deep sleep)
  if (gps.location.isValid() && gps.location.age() < 3000) { lastLat = gps.location.lat(); lastLon = gps.location.lng(); lastFixAt = millis() ? millis() : 1; }
  char buf[120];
  int bat = batMilliVolts();  // format: PANDU,V1,<jenis>,<lat>,<lon>,<mV baterai>,<helm 0/1/2>,<usia posisi detik; 0 = baru>
  if (lastFixAt)
    snprintf(buf, sizeof buf, "PANDU,V1,%s,%.6f,%.6f,%d,%d,%lu", type, lastLat, lastLon, bat, helmState(), (unsigned long)((millis() - lastFixAt) / 1000));
  else
    snprintf(buf, sizeof buf, "PANDU,V1,%s,NOFIX,NOFIX,%d,%d,0", type, bat, helmState());
  Serial.println(buf);
  if (!loraOk) return;
  LoRa.beginPacket(); LoRa.print(buf); LoRa.endPacket();
}

// ---- Deteksi ----
enum Alert { NONE, FALL, MOB, SOS };
const char *alertName[] = {"", "FALL", "MOB", "SOS"};
Alert active = NONE;
bool sosWake = false;
int repeatsLeft = 0;  // SOS dikirim ulang min. 3x (LoRa tanpa ACK)
uint32_t lastSend = 0, lastBeat = 0;

Alert detectFall() {  // free-fall >= FREEFALL_MS lalu benturan dalam IMPACT_WIN
  static uint32_t ffStart = 0, ffEnd = 0;
  float g = accelG(); uint32_t now = millis();
  if (g < FREEFALL_G) { if (!ffStart) ffStart = now; if (now - ffStart >= FREEFALL_MS) ffEnd = now; }
  else ffStart = 0;
  if (ffEnd && g > IMPACT_G && now - ffEnd < IMPACT_WIN) { ffEnd = 0; return FALL; }
  if (ffEnd && now - ffEnd >= IMPACT_WIN) ffEnd = 0;
  return NONE;
}
bool waterWet() { return analogReadMilliVolts(PIN_WATER) > WATER_WET_MV; }
uint32_t fallAt = 0;  // millis() jatuh terakhir; 0 = belum pernah
Alert detectMob() {  // MOB = jatuh DAN sensor air aktif kontinu WATER_MS dalam MOB_WINDOW_MS setelah jatuh (basah saja tanpa jatuh = bukan alarm)
  static uint32_t since = 0;
  if (!fallAt || millis() - fallAt > MOB_WINDOW_MS) { since = 0; return NONE; }
  if (waterWet()) { if (!since) since = millis(); return millis() - since >= WATER_MS ? MOB : NONE; }
  since = 0; return NONE;
}
Alert detectSos() {
  static uint32_t since = 0;
  if (digitalRead(PIN_SOS) == HIGH) { if (!since) since = millis(); return millis() - since >= SOS_HOLD_MS ? SOS : NONE; }
  since = 0; return NONE;
}

void setup() {
  Serial.begin(115200);
#ifdef DEMO_NO_BROWNOUT
  WRITE_PERI_REG(RTC_CNTL_BROWN_OUT_REG, 0);   // HANYA demo di USB tanpa kapasitor: mematikan detektor brownout (jangan dipakai di produk)
#endif
  rtc_gpio_deinit((gpio_num_t)PIN_PWR_BTN);
  rtc_gpio_deinit((gpio_num_t)PIN_SOS);
  pinMode(PIN_PWR_BTN, INPUT_PULLUP);
  pinMode(PIN_SOS, INPUT);  // pull-down eksternal R2
  pinMode(PIN_WATER, INPUT);
  analogSetPinAttenuation(PIN_WATER, ADC_11db);
  analogSetPinAttenuation(PIN_BAT, ADC_11db);  // 0-3,1 V; baterai 4,2 V / 2 = 2,1 V
  while (digitalRead(PIN_PWR_BTN) == LOW) delay(10);   // abaikan tekanan yang membangunkan
  gpsPower(true); xkcPower(true);
  gpsSerial.begin(9600, SERIAL_8N1, PIN_GPS_RX, PIN_GPS_TX);
  Wire.begin(PIN_SDA, PIN_SCL);
  mpuOk = mpuInit();
  LoRa.setPins(PIN_LORA_CS, PIN_LORA_RST, PIN_LORA_DIO0);
  loraOk = LoRa.begin(LORA_FREQ);
  helmScanStart();
  sosWake = esp_sleep_get_wakeup_cause() == ESP_SLEEP_WAKEUP_EXT1;
  Serial.printf("Boot: MPU=%d LoRa=%d wake=%s\n", mpuOk, loraOk, sosWake ? "SOS" : "other");
}

void loop() {
  while (gpsSerial.available()) gps.encode(gpsSerial.read());

  // tombol power: tekan sebentar = tidur
  if (digitalRead(PIN_PWR_BTN) == LOW) { delay(30); if (digitalRead(PIN_PWR_BTN) == LOW) goToSleep(); }

  if (sosWake) { active = SOS; repeatsLeft = 3; lastSend = millis() - ALERT_REPEAT_MS; sosWake = false; }  // bangun karena SOS = langsung kirim, tanpa tahan 2 detik
  Alert a = detectSos();
  if (a == NONE) a = detectMob();
  if (a == NONE && mpuOk) a = detectFall();
  if (a == FALL) fallAt = millis() ? millis() : 1;
  if (a != NONE) { if (a != active) { repeatsLeft = (a == SOS ? 3 : 2); lastSend = millis() - ALERT_REPEAT_MS; } active = a; }  // alert baru: kirim segera

  uint32_t now = millis();
  if (active != NONE && now - lastSend >= ALERT_REPEAT_MS) {
    sendPkt(alertName[active]); lastSend = now;
    if (repeatsLeft > 0) repeatsLeft--;
    bool still = (active == SOS && digitalRead(PIN_SOS) == HIGH) || (active == MOB && waterWet());
    if (repeatsLeft == 0 && !still) active = NONE;  // berhenti setelah kirim ulang & kondisi berakhir
  }
  static uint32_t lastStat = 0;   // ringkasan status untuk demo/serial monitor
  if (now - lastStat >= 2000) {
    lastStat = now;
    uint32_t left = (fallAt && now - fallAt <= MOB_WINDOW_MS) ? (MOB_WINDOW_MS - (now - fallAt)) / 1000 : 0;
    Serial.printf("[status] helm=%d rssi=%d dBm | air=%s (%d mV) | jendela MOB=%lus | gps=%s sat=%d | g=%.2f\n", helmState(), (int)helmRssi,
                  waterWet() ? "ADA AIR" : "kering", analogReadMilliVolts(PIN_WATER), (unsigned long)left,
                  gps.location.isValid() ? "FIX" : "NOFIX", gps.satellites.isValid() ? (int)gps.satellites.value() : 0, mpuOk ? accelG() : 0.0f);
  }
  if (now - lastBeat >= HEARTBEAT_MS) { sendPkt("HB"); lastBeat = now; }
  delay(10);
}

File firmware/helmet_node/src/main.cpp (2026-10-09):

// PANDU Helmet Node: ESP32-C3 SuperMini. Beacon BLE: tombol ON = helm menyiarkan sinyal, Vest menilai "dekat" dari RSSI.
// Tidak ada sensor sentuh. Pin: PWR_BTN=GPIO4 (tact ke GND, pull-up R1).
// Format advertising: nama "PANDU-HELM", manufacturer data = {0xFF,0xFF,'P','H', 1, counter}  (byte ke-5 selalu 1 = helm menyala; dipertahankan agar cocok dengan Vest)
//
// HEMAT DAYA: library Arduino-ESP32 bawaan dikompilasi tanpa CONFIG_PM_ENABLE, jadi light sleep otomatis
// (dengan BLE) tidak tersedia. Pengganti: duty-cycle deep sleep. Tiap WAKE_PERIOD_S detik bangun,
// siaran BLE singkat (ADV_BURST_MS), lalu deep sleep lagi. State ON/OFF disimpan di memori RTC.
// Tombol (GPIO4) = toggle ON/OFF: bangun dari tidur kapan saja; OFF = tidur tanpa timer (tidak menyiarkan = Vest menilai "tidak terjangkau").
// #define TEST_BEACON
#include <Arduino.h>
#include <NimBLEDevice.h>
#include "esp_sleep.h"
#include "driver/gpio.h"  // <--- TAMBAHKAN INI UNTUK MENGONTROL PIN

constexpr int PIN_PWR   = 4;                       // GPIO0-5 bisa wake deep sleep di C3
constexpr uint32_t WAKE_PERIOD_S = 8;              // KALIBRASI: makin kecil makin responsif, makin boros
constexpr uint32_t ADV_BURST_MS  = 400;            // lama siaran per bangun

RTC_DATA_ATTR bool powered = true;                 // toggle tombol
RTC_DATA_ATTR uint8_t counter = 0;

void setAd(uint8_t c) {
  NimBLEAdvertising *adv = NimBLEDevice::getAdvertising();
  uint8_t d[6] = {0xFF, 0xFF, 'P', 'H', 1, c};
  NimBLEAdvertisementData ad, sr;
  ad.setFlags(BLE_HS_ADV_F_DISC_GEN | BLE_HS_ADV_F_BREDR_UNSUP);
  ad.setManufacturerData(std::string((char *)d, sizeof d));
  sr.setName("PANDU-HELM");
  adv->setAdvertisementData(ad);
  adv->setScanResponseData(sr);
}

#ifdef TEST_BEACON
// Mode demo (env supermini_test): siaran BLE TERUS-MENERUS, tanpa deep sleep, serial tetap hidup. Counter naik tiap 1 detik.
// Tombol GPIO4 = toggle ON/OFF siaran (seperti tombol di produk), status dicetak ke serial.
bool beaconOn = true;
void setup() {
  Serial.begin(115200);
  pinMode(PIN_PWR, INPUT_PULLUP);
  NimBLEDevice::init("PANDU-HELM");
  NimBLEDevice::setPower(ESP_PWR_LVL_N0);
  NimBLEAdvertising *adv = NimBLEDevice::getAdvertising();
  adv->setMinInterval(160); adv->setMaxInterval(240);   // 100-150 ms
  setAd(0);
  adv->start();
  Serial.println("HELMET demo: beacon ON. Tekan tombol (GPIO4) untuk ON/OFF.");
}
void loop() {
  static uint32_t last = 0; static uint8_t cnt = 0;
  NimBLEAdvertising *adv = NimBLEDevice::getAdvertising();
  if (digitalRead(PIN_PWR) == LOW) {
    delay(30);
    if (digitalRead(PIN_PWR) == LOW) {
      beaconOn = !beaconOn;
      if (beaconOn) { setAd(cnt); adv->start(); } else adv->stop();
      Serial.printf("BEACON %s\n", beaconOn ? "ON" : "OFF");
      while (digitalRead(PIN_PWR) == LOW) delay(10);
    }
  }
  if (beaconOn && millis() - last >= 1000) {
    last = millis(); cnt++;
    adv->stop(); setAd(cnt); adv->start();
    Serial.printf("siaran counter=%d\n", cnt);
  }
  delay(20);
}

#else
void sleepNow(bool withTimer) {
  while (digitalRead(PIN_PWR) == LOW) delay(10);   // tunggu tombol dilepas agar tidak langsung bangun
  delay(50);
  
  // KUNCI PERBAIKAN: Paksa internal pull-up tetap menyala & ditahan selama tidur
  gpio_pullup_en((gpio_num_t)PIN_PWR);
  gpio_hold_en((gpio_num_t)PIN_PWR);
  gpio_deep_sleep_hold_en();

  esp_deep_sleep_enable_gpio_wakeup(1ULL << PIN_PWR, ESP_GPIO_WAKEUP_GPIO_LOW);
  if (withTimer) esp_sleep_enable_timer_wakeup((uint64_t)WAKE_PERIOD_S * 1000000ULL);
  esp_deep_sleep_start();
}

void advertiseBurst() {
  NimBLEDevice::init("PANDU-HELM");
  NimBLEDevice::setPower(ESP_PWR_LVL_N0);          // 0 dBm cukup untuk jarak helm ke vest
  NimBLEAdvertising *adv = NimBLEDevice::getAdvertising();
  adv->setMinInterval(32);                         // 20 ms (satuan 0,625 ms) -> ~20 paket per burst
  adv->setMaxInterval(48);
  setAd(counter++);
  adv->start();
  delay(ADV_BURST_MS);
  adv->stop();
  NimBLEDevice::deinit(true);
}

void setup() {
  Serial.begin(115200);
  
  // Lepas status "hold" (tahan) saat bangun agar pin bisa dibaca normal oleh sistem
  gpio_hold_dis((gpio_num_t)PIN_PWR); 
  pinMode(PIN_PWR, INPUT_PULLUP);

  if (esp_sleep_get_wakeup_cause() == ESP_SLEEP_WAKEUP_GPIO) {   // tombol ditekan: toggle ON/OFF
    powered = !powered;
    Serial.printf("Tombol: %s\n", powered ? "ON" : "OFF");
  }
  if (!powered) sleepNow(false);                   // OFF: hanya tombol yang membangunkan

  Serial.println("siaran beacon");
  advertiseBurst();
  sleepNow(true);
}

void loop() {}  // tidak pernah tercapai: setup() selalu berakhir di deep sleep
#endif

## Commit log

2026-10-02 Initial commit: weekly reports, week 6 audit and casing
    [PANDU_HelmetNode_Casing.scad, PANDU_VestNode_Casing.scad]
2026-10-02 Handover: PCB1 now uses DevKitC V4 footprint
2026-10-02 Handover: PCB3 swapped to DevKitC, final pin map
2026-10-02 Add new Gerber for PCB1 and PCB3 (DevKitC, DRC clean)
2026-10-02 Add PCB2 Gerber with 100uF tantalum on CR2032 rail
2026-10-02 PCB1: rotate TP4056 180 so USB-C faces left wall; re-export Gerber
2026-10-02 Casing v5: DevKitC, TP4056 bottom-mounted, boost over DevKit, DevKit USB extension port
    [PANDU_VestNode_Casing.scad]
2026-10-06 Add Week 6 individual report, vest node firmware (compiles), MOSFET gating sim
2026-10-06 Add netlists + pin check, fix SOS polarity in firmware (active-high per schematic)
    [main.cpp]
2026-10-06 v2: antenna headers, bulk cap, 5V backfeed diode, single USB on gateway, SD_CS pull-up, IRLZ44N; new Gerbers and netlists
2026-10-06 PCB2 v2: remove series diode, new Gerber
2026-10-06 Firmware: SOS button wakes Vest Node from deep sleep (ext1 ANY_HIGH, power button stays ext0)
2026-10-06 PCB1 v2: battery voltage divider (IO35), firmware reports battery mV; new Gerber and netlist
2026-10-06 PCB2 v2: add on/off tact button (GPIO4) with pull-up; new Gerber and netlist
2026-10-06 Add helmet node firmware (BLE worn-status advertising, button deep sleep)
2026-10-06 Helmet firmware: duty-cycle deep sleep (RTC state), button ON/OFF toggle
2026-10-06 Add assembly test checklist (modules, power, sensors, LoRa link, helmet BLE, endurance)
2026-10-08 PCB2 v2.1: Helmet powered by LiPo + TP4056 (5V pin, slide switch), new Gerber/netlist, docs updated
2026-10-08 Demo tanpa LoRa: FALL lalu MOB, status serial Vest, helmet tanpa sensor sentuh (beacon + tombol), test sketches, audit, BOM v2, tutorial demo, plan revisi
2026-10-08 Fase 0: pindahkan Gerber lama ke _obsolete, tandai semua Gerber belum boleh dipesan
2026-10-08 Revisi PCB2 (BAT_NEG, tanpa TTP223, SAW1 diganti header J1) dan PCB3 (SD di SPI terpisah); netlist, check script, firmware Gateway, env demo_usb untuk Vest
2026-10-09 button config
2026-10-12 Add dashboard plan: stack, features, data contract, stage logic, responsive layouts, phases (scope prototipe 1 Vest)
2026-10-12 Week 7: individual report (docx/pdf + builder), progress audit Pekan 2-7, UTS presentation revision, device summary, report revision notes
2026-10-13 LoRa: switch to Ra-02 SX1278 433 MHz (firmware freq 433E6, breakout pinout/footprint doc, BOM and docs updated)
2026-10-13 test_lora_one: two-module link test (RX with RSSI/SNR, random TX jitter)
2026-10-13 XKC-Y25-V: update tutorial, BOM, checklist, plan (digital 5-24 V, 4-pin XH, divider, 5V ripple), test_water wiring notes
2026-10-13 Tutorial: remove stale Gateway SD shared-bus, TTP223 touch sensor, adapter 2 mm; align with Ra-02 433 and button/beacon helmet
2026-10-13 Firmware packet v2: Vest (vest_id, seq, OFF, heartbeat jitter) and Gateway (v1/v2 parse, radio dedupe, NTP, SD store-and-forward, HTTPS upload task); docs
2026-10-13 Docs: ESP32 DevKit V1 30-pin pinout and PCB impact (netlists are for DevKitC V4)
2026-10-13 Docs: Gateway PCB3 pin mapping for DevKit V1
2026-10-13 test_lora_diag: add ESP32 SPI loopback test (IO23->IO19 jumper)
2026-10-13 Add test_lora_wires: LED-based wiring test for LoRa pins (no multimeter needed)
2026-10-13 test_lora_wires: choose pin via serial, continuous blink (timing was too fast)
2026-10-13 Add test_lora_scan: bit-bang SPI over all 24 pin-role permutations to find swapped LoRa wires
2026-10-31 Pekan 10: BOM ukuran/daftar beli, AUDIT_V3, rekap, progress; Gateway http:// untuk uji lokal; probe LoRa; laporan individu
2026-11-11 Add footprint audit spec, DevKit/Ra-02 footprint scripts, week 11 progress draft
2026-11-11 Add CLAUDE.md, pre-order PCB checklist, and 3-agent parallel plan
2026-11-11 Gateway tanpa sirine: update docs, BOM, dan firmware
2026-11-11 Bersihkan catatan sirine Gateway di HANDOVER dan checklist uji rakit
